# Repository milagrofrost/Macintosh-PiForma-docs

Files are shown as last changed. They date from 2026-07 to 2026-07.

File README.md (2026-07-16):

# Macintosh PiForma

**A Raspberry Pi-powered Macintosh Performa fever dream built inside an Apple IIc Monitor.**

Macintosh PiForma is a finished Raspberry Pi 4B build inside a retired Apple IIc Monitor shell. It is not a restoration. It is not pretending to be a museum piece. It is a working, portable, weirdly sincere Apple-flavored machine that lives somewhere between a Macintosh Performa, a Raspberry Pi desktop, a retro game station, and a piece of early-2000s Mac mod forum nostalgia.

The original CRT was already too far gone to justify saving. The case, power switch, AC inlet, rear openings, and overall monitor shape were kept and reused. The inside was rebuilt around a modern LCD, a Raspberry Pi 4B, an Anker battery, a custom 5V JST power rail, a boot chime module, a capacitive Apple logo button, and a Bluetooth-converted Apple ADB keyboard.

It is called **Macintosh PiForma** because puns are allowed here.

## What it does

- Boots a Raspberry Pi desktop with a Mac OS 9-ish look.
- Runs at 800x480 on an internal LCD panel.
- Uses the original Apple monitor power switch to turn the system rail on and off.
- Can charge its internal Anker battery through the original rear AC inlet.
- Can run from battery power.
- Has HDMI from the Raspberry Pi and RCA composite video input through the LCD controller.
- Has a rear source-select switch wired to the LCD controller's source button.
- Has a boot chime selector with multiple startup sounds.
- Uses the front Apple logo as a capacitive multi-tap gesture button.
- Has an internal USB speaker for Raspberry Pi audio.
- Uses a converted Apple ADB keyboard over Bluetooth.
- Uses a matching 3D printed Apple-style wireless mouse.
- Travels in a custom velvet-lined bag with a hidden wireless charging pad.

## Why this exists

I grew up looking at Macintosh mods on places like AppleFritter and other early Mac modding corners of the internet. G3s, G4s, weird translucent plastics, practical hacks, dumb hacks, beautiful hacks. I always wanted to build something that felt like that era.

Macintosh PiForma is not a perfect recreation of anything Apple shipped. It is more like a fever dream of what a portable Macintosh Performa-ish object could have been if it had Raspberry Pi guts, a pile of JST connectors, too many HDMI ribbon cables, and a stubborn refusal to stop being charming.

## Project status

This is documented as a **finished project**.

That does not mean there are no future improvements. It means this version is complete enough to put a bow on it and stop mentally treating it as a pile of loose tasks.

## PiForma software projects

Macintosh PiForma is one integrated build spread across this documentation repository and several companion application repositories. This repo explains the machine, recovery notes, hardware, wiring, and how the software pieces fit together. The app repositories own their own source, build, and release details.

| Project | Repository | Role |
|---|---|---|
| PiForma Panel | https://github.com/milagrofrost/piforma-panel | active Macintosh-style top panel and menu bar |
| AtEase Simulator | https://github.com/milagrofrost/AtEase-simulator | At Ease-style launcher surface |
| ControlStrip Simulator | https://github.com/milagrofrost/ControlStrip-Simulator | bottom-left Control Strip and app focus helper |
| About This PiForma | https://github.com/milagrofrost/about-this-pi | About This Mac-style PiForma system window |
| Clippy PiForma fork | https://github.com/milagrofrost/clippy-rpi | retro desktop assistant |
| Flight of the Toasters | https://github.com/milagrofrost/Flight-of-the-Toasters | local Flying Toasters web app used by the launcher |

For the current system layout, see [Software](docs/software.md). For package inventory and rebuild planning, see [PiForma Package Inventory](docs/package-inventory.md) and [Macintosh PiForma Software Installation](docs/software-installation.md). For how the custom apps work together, see [Software Ecosystem](docs/software-ecosystem.md). For the canonical repo map, see [Related Projects](docs/related-projects.md).

## Photo placeholders

Add final project photos here:

```text
docs/images/front-beauty-shot.jpg
docs/images/rear-panel.jpg
docs/images/interior-open.jpg
docs/images/shelf-assembly.jpg
docs/images/power-rail.jpg
docs/images/display-controller.jpg
docs/images/battery-position.jpg
docs/images/boot-chime-selector.jpg
docs/images/apple-logo-touch-sensor.jpg
docs/images/keyboard-mod.jpg
docs/images/mouse.jpg
docs/images/bag-interior.jpg
docs/images/monitor-stand.jpg
```

## Hardware overview

At a high level:

```mermaid
flowchart TD
    AC[Original rear AC inlet] --> Charger[Internal 100W USB power adapter]
    Charger --> Battery[Anker Prime 26K 300W battery]
    Battery --> Switch[Original Apple monitor power switch]
    Switch --> Rail[Custom 5V JST power rail]

    Rail --> Pi[Raspberry Pi 4B]
    Rail --> LCD[LCD controller board]
    Rail --> Chime[YS-M3 boot chime module]
    Rail --> Touch[TTP223 Apple logo touch sensor]

    Pi --> HDMI[HDMI ribbon path]
    HDMI --> LCD
    Pi --> Speaker[Internal USB speaker]
    Pi --> GPIO[GPIO controls]
    GPIO --> Touch
    GPIO --> Volume[EC11 volume encoder]

    RCA[Rear RCA composite input] --> LCD
    Source[Rear source select switch] --> LCD
    Chime --> ChimeSpeaker[Salvaged laptop speaker]
```

## Repo layout

```text
/
├── README.md
├── docs/
│   ├── hardware.md
│   ├── software.md
│   ├── wiring.md
│   ├── bom.md
│   ├── printed-parts.md
│   ├── build-log.md
│   ├── maintenance.md
│   ├── known-issues.md
│   ├── safety.md
│   └── images/
├── stl/
│   ├── shelf/
│   ├── bezel/
│   ├── screen-feet/
│   ├── power-rail/
│   ├── battery-plunger/
│   ├── boot-chime-switch/
│   └── monitor-stand/
├── scripts/
├── systemd/
├── config/
└── references/
```

## Major docs

- [Hardware](docs/hardware.md)
- [Software](docs/software.md)
- [Package Inventory](docs/package-inventory.md)
- [Software Installation](docs/software-installation.md)
- [Software Ecosystem](docs/software-ecosystem.md)
- [Related Projects](docs/related-projects.md)
- [Wiring](docs/wiring.md)
- [Bill of Materials](docs/bom.md)
- [Printed Parts](docs/printed-parts.md)
- [Build Log](docs/build-log.md)
- [Maintenance](docs/maintenance.md)
- [Known Issues](docs/known-issues.md)
- [Safety](docs/safety.md)

## Credits

Built by **Matthew Frost**.

The Apple ADB keyboard Bluetooth conversion is based on Matt Chesters' excellent work:

<https://github.com/mattchesters/zmk-apple-desktop-bus-keyboard>

That keyboard work is not my original design. It is included here because the keyboard became part of the complete Macintosh PiForma setup.

## License

Suggested license split:

- Code, scripts, and service files: MIT
- Documentation and printed part notes: CC BY 4.0
- Third-party designs remain under their original licenses

See [LICENSE.md](LICENSE.md).

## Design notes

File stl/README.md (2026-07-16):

# Macintosh PiForma Printable Files

These are the normalized printable and editable model files used in the finished Macintosh PiForma build.

## File-format warning

The `.3mf` files in this archive were created or saved with **Microsoft 3D Builder**. They are not Bambu Studio project files and are not guaranteed to import correctly into Bambu Studio or another slicer. Assemblies, transforms, or mock-up geometry may be interpreted differently.

For normal printing:

1. Prefer the supplied `.stl` when one exists.
2. When only a `.3mf` exists, open it in Microsoft 3D Builder and export or save the printable geometry as STL before slicing.
3. Do not assume a 3MF and STL with related names contain identical geometry. The exceptions are documented below.

Bambu Studio successfully handled the printable models used for the actual build, including models that other mesh-analysis tools may describe as multi-shell or non-watertight. Do not automatically repair or simplify a model without checking that the resulting geometry still matches the installed part.

## General print guidance

- The supplied orientation is the intended starting orientation in most cases.
- Support requirements depend on printer, material, and slicer settings.
- Unless noted otherwise, print one copy of the supplied file.
- `screen-retaining-feet-four-piece.stl` already contains all four feet.
- Test-fit before final assembly. Several parts depend on the exact geometry of this modified Apple IIc Monitor shell.
- Pilot holes may need to be carefully enlarged with a drill when using thicker screws.

## File inventory

| Folder | File | Status and purpose |
|---|---|---|
| `power-rail/` | `5v-rail-enclosure.3mf`, `.stl` | Enclosure for the handmade 5V JST distribution rail mounted to the shelf. |
| `status-led/` | `apple-crt-status-led-cover.3mf`, `.stl` | Light shield around the replacement green status LED behind the original acrylic indicator area. Prevents light leakage inside the case. |
| `battery-plunger/` | `anker-battery-button-plunger.3mf` | Current spring/plunger assembly used to press the Anker battery button through an existing rear control hole. This newer geometry is kept as one assembly. The older STL was intentionally omitted because it does not match the final design. Export an STL through Microsoft 3D Builder before slicing. |
| `bezel/` | `lcd-curved-bezel-final.stl` | Known-good final curved bezel joining the flat LCD to the original curved CRT opening. |
| `bezel/` | `lcd-curved-bezel-generator.scad` | Editable OpenSCAD generator. Parameter naming is historically mixed up; read the warning in the source before changing values. |
| `bezel/` | `lcd-bezel-braces-three-piece.3mf` | Contains three shallow braces spanning the rear of the LCD and fastening into the bezel. Export through Microsoft 3D Builder before slicing. Use short, shallow screws; enlarge pilot holes only as needed. |
| `monitor-stand/` | `folding-monitor-stand.3mf`, `.stl` | Folding external monitor stand. Raises the viewing angle approximately 15–20 degrees and folds flat for transport. |
| `screen-feet/` | `screen-retaining-feet-four-piece.stl` | Four feet already arranged in one STL. The original case screws and metal frame press these against the bezel to retain it. The rejected experimental 3MF was intentionally omitted. |
| `power-switch/` | `narrow-original-power-switch.3mf`, `.stl` | Narrower replacement actuator for the original power-switch opening. Prevents binding caused by the shifted internal assembly. |
| `shelf/` | `internal-three-level-rack.3mf`, `.stl` | Internal rack for the Raspberry Pi, power rail, LCD controller, power adapter, and USB speaker. |
| `shelf/` | `rpi-elevator.3mf`, `.stl` | Raises the Raspberry Pi above the upper shelf to create an airflow gap and reduce heat transfer into the shelf. |
| `shelf/` | `rpi-shelf-spacer.3mf`, `.stl` | Small optional spacer used with the zip-tied shelf arrangement to limit movement and help keep the Pi positioned. |
| `boot-chime-switch/` | `boot-chime-board-speaker-case.3mf`, `.stl` | Case for the boot-chime soundboard and salvaged laptop speaker, attached inside the metal enclosure with double-sided adhesive. |
| `boot-chime-switch/` | `boot-chime-selector-dial.stl` | Actual printable selector-dial part for the multi-position startup-sound selector. |
| `boot-chime-switch/` | `boot-chime-selector-dial-reference-mockup.3mf` | 3D Builder mock-up containing surrounding reference geometry. It is included for design context, not as the preferred print file. Print the STL instead. |
| `usb-panel-mount/` | `usb-panel-mount.3mf`, `.stl` | Compact threaded panel mount for a solder-tab female USB receptacle installed in an enlarged original control hole. |

## Thermal and electrical safety

The Pi elevator and rack are part of the current thermal mitigation. The Raspberry Pi previously heated and warped the upper shelf, which then flexed the LCD controller board and caused display glitches and color loss.

Current mitigation includes an air gap, a zip tie supporting the shelf, and aluminum foil used as a reflective layer above and below the Pi. Aluminum foil is conductive. It must remain electrically isolated from the Pi, GPIO pins, USB shields, solder joints, display-controller board, power rail, and all exposed electronics. A nonconductive thermal barrier is preferred for a future revision.

Use PETG or another heat-tolerant material for the rack and Pi elevator when possible. A future rack revision should add a center support column or rib.

## Third-party mouse model

The Apple-style wireless mouse is not redistributed here. The build uses the third-party [Retro Wireless Computer Mouse](https://www.printables.com/model/1339297-retro-wireless-computer-mouse) shell plus the project-specific [Custom scroll wheel and axle](https://www.printables.com/model/1774131-scroll-wheel-and-axle-for-retro-wireless-computer) documented in `docs/hardware.md`.

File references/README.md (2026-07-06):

# References

Add links and third-party project references here.

## Keyboard conversion

Matt Chesters' Apple Desktop Bus keyboard ZMK project:

https://github.com/mattchesters/zmk-apple-desktop-bus-keyboard

Used as the basis for the A9M0330 Bluetooth keyboard conversion.

## Mouser boot chime selector

CK1028 selector switch:

https://www.mouser.com/ProductDetail/105-CK1028

Used to select the YS-M3 boot chime.

## AliExpress display and HDMI parts

Known order links from project purchase history:

- Final 9-inch display kit: https://www.aliexpress.com/item/3256805818626591.html
- FPV HDMI ribbon adapters: https://www.aliexpress.com/item/3256808758230576.html
- PCB800099 / VS-TY2662 controller experiment: https://www.aliexpress.com/item/2251832767582592.html
- PCB800099 controller order: https://www.aliexpress.com/item/3256807476829617.html
- 9-inch 1024x600 LCD experiment: https://www.aliexpress.com/item/3256808854350207.html

## Mouse shell

TODO: add original Apple-style 3D printed mouse shell link.

```text
references/apple-style-wireless-mouse-link.txt
```

## Photos

TODO: add build photos under:

```text
docs/images/
```

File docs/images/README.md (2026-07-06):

# Images

Drop project images here.

Recommended filenames:

```text
front-beauty-shot.jpg
rear-panel.jpg
interior-open.jpg
shelf-assembly.jpg
power-rail.jpg
display-controller.jpg
battery-position.jpg
boot-chime-selector.jpg
apple-logo-touch-sensor.jpg
keyboard-mod.jpg
mouse.jpg
bag-interior.jpg
monitor-stand.jpg
```

These filenames are referenced from the main README and docs.

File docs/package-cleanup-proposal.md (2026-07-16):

# PiForma APT Cleanup Proposal

Audit date: 2026-07-15

This is the pre-change cleanup proposal for the live `macintosh-piforma` Raspberry Pi.
It is not the final fresh-install package manifest.

## Current Status: Preserved Inventory, Not Removal

This document began as a cleanup investigation. The owner has since decided that no package removal is authorized as part of this task, and no packages were removed during this work.

Experimental, compatibility, development, source-build, and possible future-feature software should be preserved and documented. Packages that were previously described as removal candidates are now classification candidates. "Not currently referenced" does not mean "unneeded"; it may mean development, experiment, fallback, alternate implementation, compatibility support, diagnostic utility, historical build dependency, or intentionally preserved unknown.

This file remains useful as the initial audit record. The canonical long-term package results now live in:

- [PiForma Package Inventory](package-inventory.md)
- [Macintosh PiForma Software Installation](software-installation.md)
- [`../packages/`](../packages/)

## System Snapshot

- OS: Debian GNU/Linux 13.5 (trixie)
- Kernel: `6.18.34+rpt-rpi-v8`
- Architecture: `arm64` / aarch64
- Foreign architecture: `armhf`
- Active desktop session: LightDM autologin, `rpd-x`, X11
- Active desktop processes: `lxsession -s rpd-x -e LXDE`, Openbox, `pcmanfm --desktop`, PiForma Panel, AtEase, ControlStrip Simulator, Clippy, PipeWire, WirePlumber
- dpkg status rows before cleanup investigation: 2911
- Installed/held-installed package rows before cleanup investigation: 2909 (`ii`: 2908, `hi`: 1)
- Config/status residue rows before cleanup investigation: 2 (`rc`: 2, `rpi-connect-lite` and `tint2`)
- Manually marked APT packages before cleanup investigation: 401
- Automatically marked APT packages before cleanup investigation: 2508
- Held packages: `libsdl2-dev`
- Failed systemd units before cleanup: none
- Failed user units before cleanup: none

## APT Sources

Configured repositories are Debian Trixie and Raspberry Pi Foundation Trixie for `arm64` and `armhf`:

- `http://deb.debian.org/debian/` suites `trixie trixie-updates`
- `http://deb.debian.org/debian-security/` suite `trixie-security`
- `http://archive.raspberrypi.com/debian/` suite `trixie`

No third-party APT repository was found. Local PiForma application packages installed outside configured repositories:

- `about-this-pi-forma`
- `at-ease`
- `clippy`
- `control-strip-simulator`
- `pi-forma-panel`

## Definitely Keep

These have direct live evidence from active services, live processes, or current launchers:

- Base display/session: `lightdm`, `rpd-x-core`, `rpd-x-extras`, `xserver-xorg`, `openbox`, `pcmanfm`, `lxsession`, `lxpolkit`, `picom`, `xcompmgr`
- PiForma apps: `pi-forma-panel`, `at-ease`, `control-strip-simulator`, `clippy`, `about-this-pi-forma`
- Audio/runtime: `pipewire`, `pipewire-audio`, `pipewire-pulse`, `wireplumber`, `pulseaudio-utils`, `alsa-utils`
- Script/runtime tools: `python3`, `python3-gpiozero`, `python3-rpi-lgpio`, `wmctrl`, `xdotool`, `x11-utils`, `jq`
- Launchers/features: `chromium`, `qmmp`, `flatpak`, `lxterminal`, `pcmanfm`
- Raspberry Pi support: `raspi-firmware`, `raspi-utils`, `rpi-eeprom`, `raspberrypi-sys-mods`, `raspberrypi-net-mods`, firmware packages, networking and Bluetooth packages

## Keep If Local Development Continues

These appear to support local building/packaging rather than base runtime:

- General build: `build-essential`, `cmake`, `gcc`, `g++`, `git`, `devscripts`, `debhelper`, `dh-autoreconf`, `shellcheck`
- Node/Tauri: `nodejs`, `npm`, `libwebkit2gtk-4.1-dev`, `libgtk-3-dev`, `libayatana-appindicator3-dev`
- PiForma/ControlStrip media or native builds: `libpipewire-0.3-dev`, `libspa-0.2-dev`, `libasound2-dev`, `libpulse-dev`, `libudev-dev`, `libx11-xcb-dev`, `libgbm-dev`, `libdrm-dev`, `libusb-1.0-0-dev`, FFmpeg dev packages
- Qt/local app experiments: `qt6-base-dev`, `qt6-multimedia-dev`, `qt6-tools-dev`, `qtcreator`, related Python/Qt packages
- Emulator or media build headers: `libvlc-dev`, `libvlccore-dev`, `libcdio-dev`, `libiso9660-dev`, `libsdl2-dev`, `libfreeimage-dev`, `libfreetype-dev`, `libboost-filesystem-dev`, `libspeexdsp-dev`

Do not remove this group until the owner decides whether this Pi remains a development machine.

## Optional Feature Packages

Keep unless the feature is intentionally removed:

- `qmmp`: current Winamp launcher target
- `flatpak`: current Kiwix/Encarta launcher target; Flatpak apps found: `org.kiwix.desktop`, `org.kde.marble`, `org.qgis.qgis`
- `chromium`: many AtEase kiosk launchers and Weather Channel/Flying Toasters
- `vlc`: no current AtEase launcher, but may be retained as optional media support
- `x11vnc`, RealVNC packages: remote access; owner decision
- RetroPie/EmulationStation: current AtEase launcher calls `emulationstation`, but it is not owned by APT
- SheepShaver: current AtEase launcher uses `/home/frost/emulation/SheepShaver-aarch64.AppImage`

## First Batch Reclassified As Preserved Experiments

These were initially identified as a possible small cleanup batch. That removal framing is now superseded. They are preserved as installed experiments unless future owner review establishes a different purpose.

| Package | Evidence | Simulation | Installed size | Disposition |
| --- | --- | --- | ---: | --- |
| `dosbox-x` | Docs mark DOSBox-X / Windows 98 as experimental or pending confirmation; no current AtEase launcher or live process found. | Earlier simulation removed only the four named packages; no real removal was run. | 11452 KiB | preserved experiment |
| `qtractor` | Audio workstation / music production experiment candidate; no service, current launcher, or live process found. | Earlier simulation removed only named packages; no real removal was run. | 8574 KiB | preserved experiment |
| `tuxpaint` | Docs mark Tux Paint as historical/dormant/pending owner confirmation; no current AtEase launcher or live process found. | Earlier simulation removed only named packages; no real removal was run. | 617 KiB | preserved experiment |
| `tuxpaint-config` | Configuration tool associated with the preserved Tux Paint experiment. | Earlier simulation removed only named packages; no real removal was run. | 1414 KiB | preserved experiment |

## Other Groups Reframed As Preserved Classifications

- XFCE packages: alternate desktop/session and appmenu experiment. Preserve.
- Wayland and Weston packages: alternate display/session experiment and Raspberry Pi desktop compatibility. Preserve.
- Xephyr: nested display testing tool. Preserve as experiment/diagnostic utility.
- `rpd-wayland` packages: Raspberry Pi desktop Wayland stack and alternate implementation. Preserve.
- `labwc`: Wayland compositor retained for alternate desktop testing. Preserve.
- `wayvnc`: Wayland remote-access support retained with the Wayland stack. Preserve.
- Wine and `armhf` packages: compatibility layer and foreign-architecture support. Preserve.
- VLC: optional media player and media-development support. Preserve.
- VNC packages: remote administration and fallback access. Preserve.
- Firefox: Raspberry Pi desktop application/fallback browser. Preserve.
- Old kernels: kernel history and possible boot fallback. Do not remove during package inventory work.
- Development headers: intentionally retained local build environment. Preserve.
- Qt development packages: Qt/local app experiments and development. Preserve.
- Media development packages: confirmed or likely source-build dependencies. Preserve.
- Emulator development packages: confirmed or likely emulator/source-build dependencies. Preserve.

## Superseded Cleanup Plan

The earlier plan to remove a first explicit batch is superseded and must not be followed. Current plan:

1. Preserve installed software.
2. Snapshot exact dpkg/APT state.
3. Classify packages by role and rebuild profile.
4. Document local `.deb` packages and non-APT software.
5. Build a future fresh-install guide without claiming reproducibility until a separate-media rebuild is tested.

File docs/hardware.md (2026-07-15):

# Hardware

This document describes the physical Macintosh PiForma build from the final working state.

## Donor shell

- Donor: Apple IIc Monitor
- Model: A2M4090
- Manufacture date: February 1985
- Original CRT: removed years ago
- Final use: Raspberry Pi-powered Macintosh-inspired portable computer

This is not a restoration. The CRT was discolored, flickering, and not worth saving for this project. The case, original power switch, original AC inlet, rear openings, metal chassis, and monitor shape were reused because the shell still had life in it.

## Internal layout

The build has four main physical zones:

1. Front display area
2. Three-level printed shelf
3. Rear battery area
4. Rear controls and ports

The shelf does not hold the Anker battery. The Anker battery sits separately toward the rear of the monitor on the metal chassis floor. It is installed lengthwise and held by friction between the sides of the case.

## Three-level shelf

The custom 3D printed shelf is the main internal component carrier.

### Top shelf

- Raspberry Pi 4B, 4GB RAM
- Custom 5V JST power rail
- Power rail enclosure
- Related wiring

The Raspberry Pi is mounted with zip ties.

### Middle shelf

- Internal 100W USB power adapter
- LCD controller board

The LCD controller slides into printed notches like a tray, which makes it serviceable instead of permanently buried.

### Bottom shelf

- Internal USB speaker

The USB speaker is connected directly to the Raspberry Pi and handles normal system audio.

## Rear battery area

The Anker Prime 26K 300W battery sits lengthwise across the rear metal chassis floor. It is a very tight fit and is held by friction rather than a printed mount.

A custom 3D printed plunger reaches the Anker's physical button. From the outside rear of the case, pressing the plunger lets the user wake the battery display or interact with the battery without opening the case.

## Display system

The final installed display is the 9-inch HDMI/VGA/AV LCD kit purchased on May 16, 2026. The current working mode is:

- Resolution: 800x480
- Inputs used: HDMI and RCA composite
- VGA: available on the controller but unused

Earlier experiments included 1024x600-class 9-inch panels, PCB800099-style boards, and multiple HDMI ribbon cable orientations. Those are part of the build history, but the final working display is the May 16 display kit running at 800x480.

## LCD mounting

The LCD is mounted with:

- 3D printed bezel
- 3D printed screen feet
- 3D printed horizontal braces
- small hot glue dabs for alignment during assembly
- original chassis screws that pull the metal chassis and front case together

The screen rests into the printed bezel. The bezel aligns it. The horizontal braces help keep it registered. The feet really do their job once the metal chassis is screwed into the front shell.

## Display ribbon

The current LCD ribbon is about 150mm. It is longer than needed, but it works.

Known behavior:

- the connection is sensitive
- the ribbon is taped down to reduce movement
- shorter 80mm or 50mm cable may be a future improvement
- once it works, do not mess with it just because you are bored

## Video paths

### Raspberry Pi video

The Raspberry Pi connects to the LCD controller over HDMI using angled and ribbon-style adapters. A normal HDMI connector would protrude too far and contact the back of the LCD, causing distortion.

### Composite video

A rear RCA panel jack replaces one of the original brightness/contrast control openings. It connects to the composite input on the LCD controller.

### Source select

The LCD controller's button daughterboard is mounted inside the case. The IR receiver is unused. The source button was soldered to wires and routed to a rear physical switch.

The source switch cycles:

```text
HDMI -> RCA -> VGA -> RCA2 -> repeat
```

Only HDMI and RCA are normally useful.

## Power system

The Anker battery is the heart of the power system.

Final power path:

```text
Original AC inlet
  -> internal 100W USB power adapter
  -> Anker Prime 26K 300W battery
  -> original Apple monitor power switch
  -> custom 5V JST power rail
  -> Raspberry Pi, LCD controller, boot chime module, touch sensor
```

The original monitor power switch interrupts battery output to the 5V rail. It does not interrupt AC input to the internal charger. That means the battery can still charge while the monitor is off.

The final internal charger is the 100W USB power adapter from eBay. A different Amazon power adapter caused noise and EMI weirdness, including false triggers from sensors and relay instability, so it was not used.

## Custom 5V JST rail

The rail is handmade from:

- through-hole perfboard
- about six small 2-pin JST outputs
- stripped solid-core wire used as bus bars
- soldered underside connections
- 3D printed enclosure

Connected loads include:

- Raspberry Pi 4B
- LCD controller
- YS-M3 boot chime module
- TTP223 Apple logo touch sensor

The USB speaker is powered through the Raspberry Pi USB port, not from the JST rail.

There are no relays in the final build and no fuses on the custom rail. The build relies on the Anker and connected devices for protection.

## Boot chime system

Parts:

- YS-M3 MP3 sound module
- Mouser CK1028 selector switch
- salvaged laptop speaker
- custom 3D printed sound module and speaker housing
- rear-mounted boot chime selector

Behavior:

- YS-M3 is powered from the 5V rail
- it plays a selected sound a couple seconds after power is applied
- CK1028 selects between about 9 or 10 boot chimes
- audio plays through its own salvaged laptop speaker

The selector is mounted in one of the rear holes where the original brightness/contrast controls used to be.

## Main audio

Normal Raspberry Pi audio uses the internal USB speaker mounted on the bottom shelf.

An external USB-to-3.5mm/RCA audio adapter can be used if RCA audio is needed, but it is not built into the monitor. The rear RCA jack is composite video only.

MAX98357A amplifier boards were purchased and tested but are not part of the final installed audio path.

## Apple logo gesture input

The front Apple logo has a TTP223 capacitive touch sensor behind it.

- Sensor: TTP223
- GPIO: 23
- Function: multi-tap and hold gesture input

Gesture map:

| Gesture | Action |
|---|---|
| 1 tap | Open Internet Explorer themed launcher |
| 2 taps | Open Mac OS 9 / SheepShaver |
| 3 taps | Open Winamp/QMMP style player |
| 4 taps | Open RetroPie / EmulationStation |
| Hold | Close the active window |

The four-tap RetroPie gesture is the practical one. Power on, plug in a controller, tap the Apple logo four times, and start playing without pulling out the keyboard and mouse.

The hold gesture also solves the N64 controller hotkey problem. Instead of sacrificing a controller button, holding the Apple logo closes the active game or EmulationStation.

## Volume knob

The original monitor volume area is repurposed with an EC11 rotary encoder.

| Function | GPIO |
|---|---:|
| Encoder A | GPIO 17 |
| Encoder B | GPIO 27 |
| Encoder push | GPIO 22 |

Rotation adjusts system volume. Push-to-mute exists in software but is not physically usable in the final installation.

## Keyboard

Keyboard: Apple ADB Keyboard A9M0330

The keyboard is converted to Bluetooth using Matt Chesters' ZMK ADB keyboard project:

https://github.com/mattchesters/zmk-apple-desktop-bus-keyboard

This keyboard conversion is part of the Macintosh PiForma setup, but it is not an original design from this project.

Installed keyboard components:

- Seeed XIAO nRF52840
- custom PCB
- nice!view display
- MCP23017 I/O expander
- USB-C charging
- JST battery connector
- 110mAh LiPo battery
- ZMK firmware

The keyboard currently works over Bluetooth and charges over USB-C.

## Mouse

The matching mouse uses:

- Bambu wireless mouse kit electronics
- [Retro Wireless Computer Mouse](https://www.printables.com/model/1339297-retro-wireless-computer-mouse) 3D printed shell
- [Custom scroll wheel and axle](https://www.printables.com/model/1774131-scroll-wheel-and-axle-for-retro-wireless-computer)
- USB receiver plugged into the Raspberry Pi
- Retro Platinum PLA for the printed shell

The original mouse design required the Bambu-supplied scroll wheel to be cut and whittled down to fit. That wheel broke during modification, so a complete replacement scroll wheel and axle were designed and printed instead.

## Bag system

The travel bag is part of the project.

Bag features:

- LOVFEIFAN / LOVFEI FAN style 55x30x20 cm bag
- corrugated plastic liner
- foam bottom
- green velvet covering
- spray adhesive
- hidden wireless charging transmitter
- alignment grooves for the monitor bottom

The bag stores the computer, ADB Bluetooth keyboard, mouse, controllers, USB hub, stand, cables, and power accessories.

The wireless charging pad is hidden under the velvet. A USB cable runs through the bag into a back pocket, where it can be pulled out to power the wireless charger. This is a trickle-charge setup for charging Macintosh PiForma while it is stored in the bag.

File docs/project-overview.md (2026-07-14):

# Project Overview

**Macintosh PiForma** is a Raspberry Pi-powered Macintosh Performa fever dream built inside an Apple IIc Monitor.

It is not a restoration. It is not trying to be a museum piece. It is a working, portable, weirdly sincere Apple-flavored machine that lives somewhere between a Macintosh Performa, a Raspberry Pi desktop, a retro game station, and a piece of early-2000s Mac mod forum nostalgia.

## The short version

This is a 1985 Apple IIc Monitor shell turned into a portable Raspberry Pi Macintosh-ish computer.

It has:

- a Raspberry Pi 4B running an 800x480 Mac OS 9-ish desktop
- the original monitor power switch repurposed as the system power switch
- an internal Anker Prime 26K battery
- an internal USB-C charger wired to the original rear AC inlet
- a handmade 5V JST power rail
- HDMI and RCA composite video support through the LCD controller
- a boot chime selector with multiple startup sounds
- a front Apple logo that works as a capacitive gesture button
- a Bluetooth-converted Apple ADB keyboard
- a 3D printed Apple-style wireless mouse
- a custom At Ease-style launcher
- a Control Strip-style dock
- an About This PiForma app
- a retro Clippy assistant
- a velvet-lined travel bag with hidden wireless trickle charging

## The software family

Macintosh PiForma now includes a small family of companion apps.

| Project | Repo | What it does |
|---|---|---|
| PiForma Panel | https://github.com/milagrofrost/piforma-panel | Macintosh-style top panel and menu bar |
| AtEase Simulator | https://github.com/milagrofrost/AtEase-simulator | At Ease-style launcher shell |
| ControlStrip Simulator | https://github.com/milagrofrost/ControlStrip-Simulator | Mac OS-style utility strip / dock |
| About This PiForma | https://github.com/milagrofrost/about-this-pi | About This Mac-style system info window |
| Clippy PiForma fork | https://github.com/milagrofrost/clippy-rpi | retro desktop assistant |
| Macintosh PiForma docs | https://github.com/milagrofrost/Macintosh-PiForma-docs | the build, BOM, wiring, lore, and maintenance notes |

## Why this works

The hardware gives the machine a body. The software gives it a personality.

The power switch, boot chime, Apple logo gestures, AtEase launcher, Control Strip, and matching keyboard all work together. Any one of those pieces alone would be cute. Together, they make the build feel like a complete little computer from a timeline that never existed.

## The important trick

The front Apple logo is a real input device.

| Gesture | Action |
|---|---|
| 1 tap | Open Internet Explorer / Netscape-style launcher |
| 2 taps | Open Mac OS 9 / SheepShaver |
| 3 taps | Open Winamp / QMMP |
| 4 taps | Open RetroPie / EmulationStation |
| Hold | Close the active game or window |

The four-tap RetroPie gesture is not just cute. It means the keyboard and mouse can stay in the bag when the only goal is playing games.

## What to read next

- [Hardware](hardware.md)
- [Software](software.md)
- [Software Ecosystem](software-ecosystem.md)
- [Live System Audit Summary](live-system-audit.md)
- [Wiring](wiring.md)
- [Bill of Materials](bom.md)
- [Printed Parts](printed-parts.md)
- [Build Log](build-log.md)
- [Related Projects](related-projects.md)
- [Cleanup and Archival Plan](cleanup-plan.md)
- [Media Plan](media-plan.md)
- [Maintenance](maintenance.md)
- [Known Issues](known-issues.md)
- [Safety](safety.md)

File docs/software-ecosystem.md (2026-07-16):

# Software Ecosystem

Macintosh PiForma is not just a Raspberry Pi in a monitor shell. The software stack is what makes it feel like a machine instead of a parts bin.

The hardware gives it a body. The software gives it a personality.

The package-level inventory and rebuild profile work lives in [PiForma Package Inventory](package-inventory.md) and [Macintosh PiForma Software Installation](software-installation.md).

## The desktop illusion

The live system is a Raspberry Pi 4 Model B running a Raspberry Pi OS / Debian 13 Trixie-style desktop stack on X11. The shell is built around LightDM, LXDE, Openbox, PCManFM, PiForma Panel, AtEase, ControlStrip Simulator, PipeWire, and a pile of intentionally nostalgic launchers.

The point is not to fake macOS perfectly. The point is to make a Raspberry Pi behave like a computer that fell out of a late-90s Apple fever dream.

Core pieces:

| Layer | Role |
|---|---|
| LightDM | graphical login |
| rpd-x / LXDE | session environment |
| Openbox | window manager |
| PiForma Panel | active Mac-style top menu bar |
| PCManFM | desktop background and file-manager integration |
| AtEase | At Ease-style launcher surface |
| ControlStrip Simulator | bottom-left dock and app focus helper |
| PipeWire / WirePlumber | audio |
| systemd | boots custom services into the graphical target |

## Custom apps in the PiForma family

These are the companion apps that turned the desktop from a theme into an ecosystem.

| App | Repo | Role |
|---|---|---|
| PiForma Panel | https://github.com/milagrofrost/piforma-panel | active Macintosh-style top panel and menu bar |
| AtEase Simulator | https://github.com/milagrofrost/AtEase-simulator | full-screen At Ease-style launcher shell |
| ControlStrip Simulator | https://github.com/milagrofrost/ControlStrip-Simulator | transparent Mac OS-style Control Strip dock |
| About This PiForma | https://github.com/milagrofrost/about-this-pi | About This Mac-style system window for the build |
| Clippy PiForma fork | https://github.com/milagrofrost/clippy-rpi | retro desktop assistant, forked from Felix Rieseberg's Clippy |
| Flight of the Toasters | https://github.com/milagrofrost/Flight-of-the-Toasters | local Flying Toasters web app used by the launcher |
| Macintosh PiForma docs | https://github.com/milagrofrost/Macintosh-PiForma-docs | build documentation, BOM, wiring, lore, and maintenance notes |

## AtEase Simulator

AtEase is the main retro launcher shell.

It is a Tauri app modeled after Apple's At Ease experience. It shows tabbed pseudo-folders full of big beveled launcher buttons. Each item launches a configured `.desktop` file rather than letting the front end run arbitrary shell commands.

Known installed paths from the live audit:

```text
/usr/bin/atease
/usr/share/applications/AtEase.desktop
~/.local/share/atease/config.yaml
~/.local/share/atease/apps/
~/.local/share/atease/apps-2/
~/.local/share/atease/
```

Service:

```text
atease.service
```

The current live config renders at x=77, y=0, width=656, height=480. It starts on the main At Ease Items folder and also defines a second `sites` folder backed by `~/.local/share/atease/apps-2/`.

This is the part that makes PiForma feel less like a Linux desktop and more like a kid-safe restoration CD from an alternate Apple timeline.

## ControlStrip Simulator

ControlStrip Simulator is the dock-like utility strip.

It is a Tauri app that runs as a frameless transparent window under X11. It reads pinned apps from YAML, detects visible windows using X11 tooling, marks running apps, and launches or focuses them.

Known installed paths from the live audit:

```text
/usr/bin/controlstrip-simulator
/usr/share/applications/ControlStrip Simulator.desktop
~/.local/share/control-strip/config.yaml
```

Service:

```text
controlstrip-simulator.service
```

The live config pins Chromium/Netscape, LXTerminal, and PCManFM. It detects running windows with X11 tooling and focuses windows through `wmctrl`. Wayland is not the target right now.

## About This PiForma

About This PiForma is the machine's little brag window, except it is not really bragging. It is the classic About This Mac format translated into PiForma language.

Instead of pretending to be a real Mac, it reports the things that make sense for this build:

- PiForma name and version
- Raspberry Pi model
- memory
- swap
- running apps
- OS/system details

Repo:

```text
https://github.com/milagrofrost/about-this-pi
```

## Clippy

Clippy is not Mac at all, which is why it is funny.

It is Felix Rieseberg's Clippy idea pushed into the PiForma world as a retro desktop assistant. It runs locally and gives the machine that late-90s software-toy energy.

Installed paths from the audit:

```text
/usr/bin/clippy
/usr/lib/clippy/Clippy
~/.config/autostart/clippy.desktop
```

Repo:

```text
https://github.com/milagrofrost/clippy-rpi
```

## The launcher set

The AtEase launcher set is intentionally a little ridiculous.

| Launcher | Actually runs |
|---|---|
| Netscape | Chromium with scaling |
| America Online | Chromium kiosk to a web AOL simulator |
| Encarta | Kiwix |
| Flying Toasters | Chromium kiosk to local web server |
| LimeWire | Chromium kiosk launcher |
| Macintosh HD | PCManFM home folder |
| Mac OS 9 | SheepShaver AppImage |
| RetroPie | EmulationStation in LXTerminal |
| Winamp | QMMP |
| Weather Channel | local Weather Channel launcher script |
| Terminal | LXTerminal |

Kid Pix, LinApple, DOSBox-X, Windows 98, and Tux Paint should be documented as historical, dormant, or pending owner confirmation until they have current launchers in the live AtEase folders.

This is not about historical purity. It is about making the machine fun to touch.

## Apple logo gestures

The front Apple logo is not just decorative. It is a capacitive gesture button.

| Gesture | Action |
|---|---|
| 1 tap | Open Internet Explorer / Netscape-style browser launcher |
| 2 taps | Open Mac OS 9 / SheepShaver |
| 3 taps | Open Winamp / QMMP |
| 4 taps | Open RetroPie / EmulationStation |
| hold 2 seconds | close active window |
| hold 6 seconds | close all windows and show desktop |
| hold 10 seconds | power off |

This is one of the most important usability details in the whole build. It lets the machine work as a game station without needing to pull out the keyboard and mouse.

## Weather Channel subsystem

The Weather Channel launcher recreates a cable-TV WeatherStar style flow.

```text
~/weather-channel/weather-channel.sh
  -> pkill chromium
  -> chromium kiosk
  -> local launch.html
  -> satellite.png splash
  -> weatherstar.netbymatt.com kiosk mode
```

It is one of those features that sounds optional until you see it running. Then it becomes obvious why it belongs here.

## Audio behavior

The system uses PipeWire and WirePlumber with a USB audio device as the default output.

The physical volume knob changes `@DEFAULT_SINK@` through `pactl`. The boot chime is separate and plays through the YS-M3 module and its own salvaged laptop speaker.

That split matters:

- boot chime is part of the machine's power-on personality
- USB speaker is normal operating audio
- optional USB-to-RCA adapter handles external RCA audio needs

## The important part

The software is not just a skin. It is how the machine becomes usable.

The Apple logo launches apps. The Control Strip gives it a living dock. AtEase makes it feel approachable. The boot chime gives it ceremony. The AtEase launcher set makes it silly in the right way.

That is the difference between a Raspberry Pi project and Macintosh PiForma.

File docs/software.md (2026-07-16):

# Software

This document captures the Macintosh PiForma software stack as currently known.

The software is not trying to be a perfect clone of classic Mac OS. It is Raspberry Pi OS dressed up like a Mac OS 9 / At Ease / early internet fever dream.

For the audited APT/dpkg inventory, local `.deb` packages, non-APT software, and rebuild profiles, see [PiForma Package Inventory](package-inventory.md) and [Macintosh PiForma Software Installation](software-installation.md).

## System

| Item | Value |
|---|---|
| Board | Raspberry Pi 4 Model B |
| RAM | 4GB |
| Storage | 256GB microSD |
| Hostname | `macintosh-piforma` |
| User | `frost` |
| OS | Raspberry Pi OS / Debian 13 Trixie-style Raspberry Pi desktop stack |
| Desktop | LXDE / Openbox / PCManFM desktop |
| Session | X11 |
| Display mode | 800x480 |

## Current graphical stack

The current live desktop is an X11 `rpd-x` session launched by LightDM. Openbox manages windows, PCManFM owns the desktop background, and PiForma Panel is the active top panel.

| Layer | Current implementation |
|---|---|
| Display manager | LightDM |
| Session | `rpd-x` / LXDE on X11 |
| Window manager | Openbox |
| Desktop background | PCManFM |
| Top panel | PiForma Panel |
| Launcher shell | AtEase |
| Dock / Control Strip | ControlStrip Simulator |
| Assistant | Clippy |
| Audio | PipeWire / WirePlumber |

LXPanel-pi and tint2 configuration files may still exist on the machine, but they are not the active top panel in the July 2026 live audit.

## Boot flow

Expected flow:

```text
Power switch on
  -> Anker battery output energizes 5V rail
  -> YS-M3 boot chime plays
  -> Raspberry Pi boots
  -> Plymouth splash
  -> RetroPie asplashscreen
  -> LightDM
  -> LXDE/Openbox desktop
  -> custom services start
```

## Desktop look

The desktop is intended to feel like a Mac OS 9-ish Raspberry Pi system.

Visual pieces:

- Mac OS 9 Platinum-style GTK theme
- Chicago-style font
- MoNine icons
- PiXflat as fallback
- At Ease inspired wallpaper
- Apple-menu-style top panel
- retro launchers

It is not macOS. It is Raspberry Pi OS wearing a thrift-store Macintosh costume, and honestly that is kind of the point.

## Important config paths

Known files and directories touched during the build:

```text
/boot/firmware/config.txt                 active boot config
/boot/config.txt                          pointer to /boot/firmware/config.txt
/etc/default/keyboard                     active keyboard defaults
/etc/xdg/lxsession/rpd-x/autostart        system LXSession fallback
~/.config/lxsession/rpd-x/autostart       active user LXSession override
~/.config/openbox/rpd-rc.xml              active Openbox config
~/.config/pcmanfm/LXDE-pi/desktop-items-0.conf
~/.local/share/piforma-panel/config.yaml
~/.local/share/control-strip/config.yaml
~/.local/share/control-strip/scripts/window-check.sh
~/.local/share/atease/config.yaml
~/.local/share/atease/apps/
~/.local/share/atease/apps-2/
~/.config/SheepShaver/prefs
~/weather-channel/
~/Desktop/
~/.icons/
~/.themes/
```

Historical or missing paths found during the July 2026 config audit:

```text
~/.config/lxpanel-pi/panels/panel         historical; PiForma Panel is active
~/.config/tint2/tint2rc                   historical; no tint2 process active
~/.config/atease/config.yaml              historical AtEase schema/path
~/.config/pcmanfm/default/desktop-items-0.conf
~/.sheepshaver_prefs                      not found
~/.asoundrc                               not found
```

## Custom services

| Service | Scope | Purpose |
|---|---|---|
| `apple-gesture-button.service` | system | Handles Apple logo capacitive gestures |
| `volume-knob.service` | system | Handles EC11 volume knob |
| `atease.service` | system | Starts the AtEase launcher as user `frost` |
| `flyingtoasters.service` | system | Serves local Flying Toasters web build |
| `piforma-panel.service` | user | Starts PiForma Panel |
| `controlstrip-simulator.service` | user | Starts ControlStrip Simulator |
| `usb-audio-loop.service` | user | Optional external USB audio-input loop |

## Apple logo gesture button

Script:

```text
/usr/local/bin/apple_gesture_button.py
```

Service:

```text
apple-gesture-button.service
```

Hardware:

- TTP223 capacitive touch sensor
- mounted behind the Apple logo
- GPIO 23
- active-low
- uses `gpiozero`
- uses `LGPIOFactory`

Gesture mapping:

| Gesture | Action |
|---|---|
| 1 tap | Open Internet Explorer / Netscape-style browser launcher |
| 2 taps | Open Mac OS 9 / SheepShaver |
| 3 taps | Open Winamp / QMMP |
| 4 taps | Open RetroPie / EmulationStation |
| Hold 2 seconds | Close active window |
| Hold 6 seconds | Close all windows and show desktop |
| Hold 10 seconds | Power off |

The four-tap RetroPie gesture exists so the keyboard and mouse can stay packed when the only goal is playing games. Power on, plug in a controller, tap the Apple logo four times, and go.

The timed hold gestures provide keyboard-free window and system control. A two-second hold closes the active game or application, a six-second hold clears the desktop, and a ten-second hold shuts down the PiForma.

## Volume knob

Script:

```text
/usr/local/bin/volume_knob.py
```

Service:

```text
volume-knob.service
```

Hardware:

- EC11 rotary encoder
- GPIO 17 and 27 for rotation
- GPIO 22 for push/mute support

Behavior:

- rotate clockwise: volume up
- rotate counterclockwise: volume down
- push-to-mute supported in software
- push-to-mute not physically usable in final hardware

## Audio stack

Normal output:

- PipeWire
- internal USB speaker
- speaker plugged directly into Raspberry Pi

Optional external audio:

- `usb-audio-loop.service` is not Nintendo 64-specific. It watches for the configured external USB audio-input or capture device and loops incoming audio to the PiForma's normal output speakers.
- The current helper selects the C-Media Cable Creation adapter by its PipeWire/PulseAudio source name.
- RCA is only one possible upstream connection method before the signal reaches the USB audio adapter; 3.5 mm or other analog connectors can also feed an appropriate adapter.
- The rear RCA jack described in the hardware documentation is composite video only. Analog external audio input requires an external USB audio adapter.

Previous experiments included MAX98357A I2S amplifier boards and other audio adapters. The final installed path is the internal USB speaker because it works.

## Included apps and launchers

Current visible launchers are managed by AtEase from `~/.local/share/atease/apps/` and `~/.local/share/atease/apps-2/`, not from `~/Desktop`.

| App / Feature | Role | Status |
|---|---|---|
| RetroPie / EmulationStation | games | primary practical use |
| Web browser | general use | primary practical use |
| SheepShaver / Mac OS 9 | classic Mac nostalgia | included |
| LinApple | Apple II emulation | dormant or pending confirmation |
| DOSBox-X / Windows 98 | retro Windows | experimental or pending confirmation |
| WeatherStar / Weather Channel kiosk | ambient retro weather | included |
| Flying Toasters | screensaver nostalgia | included |
| AOL simulator | early internet nostalgia | included |
| Netscape launcher | early internet nostalgia | included |
| Encarta | encyclopedia nostalgia | included |
| LimeWire | early internet nostalgia | included |
| Kid Pix | classic creative software | historical or pending confirmation |
| Winamp / QMMP style player | music nostalgia | included |

Some are practical. Some are there because the computer would feel wrong without them.

## Weather Channel kiosk

Known path:

```text
~/weather-channel/
```

Known files:

```text
weather-channel.sh
launch.html
satellite.png
```

The kiosk flow shows a satellite image first, then opens the WeatherStar web interface in Chromium kiosk/app mode.

## Archived repo files

The repository now archives the verified live service units and key helper/config snapshots. Use the service inventory in [../systemd/README.md](../systemd/README.md) as the scope-aware source for unit paths, enablement state, and recovery commands.

Archived scripts:

```text
scripts/apple_gesture_button.py
scripts/volume_knob.py
scripts/weather-channel.sh
scripts/usb-audio-loop.sh
```

Archived systemd units:

```text
systemd/system/apple-gesture-button.service
systemd/system/volume-knob.service
systemd/system/atease.service
systemd/system/flyingtoasters.service
systemd/user/piforma-panel.service
systemd/user/controlstrip-simulator.service
systemd/user/usb-audio-loop.service
```

Archived config snapshots:

```text
config/boot/firmware/config.txt
config/keyboard/default-keyboard
config/lxsession/rpd-x-autostart
config/lxsession/system-rpd-x-autostart
config/openbox/rpd-rc.xml
config/pcmanfm/desktop-items-0.conf
config/piforma-panel/config.yaml
config/control-strip/config.yaml
config/control-strip/scripts/window-check.sh
config/atease/config.yaml
config/atease/apps/
config/atease/apps-2/
config/sheepshaver/prefs
config/historical/lxpanel-pi/panel
config/historical/tint2/tint2rc
config/historical/atease-legacy/config.yaml
config/historical/pcmanfm-default/desktop-items-0.conf
```

See `config/README.md` for the verified archive status, restore paths, validation commands, and missing files such as `/home/frost/.asoundrc`.

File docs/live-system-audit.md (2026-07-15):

# Live System Audit Summary

This page summarizes the live PiForma software audit generated on 2026-06-23 and revised on 2026-07-05 with the newer apps and theme work.

> **Dated snapshot:** this page is historical. It was superseded by the July 14, 2026 Phase 1 and Phase 2 audits. Use `docs/software.md` for the current software architecture. Keep this file as a point-in-time audit record, not as the source of truth for active panel, launcher, or service state.

The audit matters because it captures what is actually running on the machine, not just what the build was supposed to be.

## Machine identity

| Item | Value |
|---|---|
| Hostname | `macintosh-piforma` |
| Primary user | `frost` |
| Board | Raspberry Pi 4 Model B, Rev 1.1 |
| OS base | Debian 13 / Trixie-style Raspberry Pi desktop stack |
| Session | X11, `rpd-x` |
| Window manager | Openbox |
| Display manager | LightDM |

## Active custom services

| Service | State | Purpose |
|---|---|---|
| `apple-gesture-button.service` | enabled, active | reads the Apple logo capacitive touch sensor on GPIO 23 and maps taps/holds to app launches and window actions |
| `atease.service` | enabled, active | starts the AtEase Tauri launcher shell at graphical target |
| `controlstrip-simulator.service` | enabled, active user unit | runs the Control Strip-style dock as a per-user graphical-session service |
| `flyingtoasters.service` | enabled, active | serves the local After Dark Flying Toasters web build on localhost port 3000 |
| `volume-knob.service` | enabled, active | reads the EC11 rotary encoder and controls PipeWire volume through `pactl` |
| `asplashscreen.service` | enabled, active oneshot | RetroPie VLC boot splash |

## Stock services worth knowing about

Running stock services include:

- LightDM
- NetworkManager
- wpa_supplicant
- PipeWire / WirePlumber
- Bluetooth
- CUPS
- Avahi
- cron
- ssh
- systemd-timesyncd

`pigpiod` is installed but inactive. The final GPIO scripts use `gpiozero` with `lgpio`, not pigpio.

`wayvnc-control.service` exists but is inactive because the system is using X11, not Wayland.

## Startup sequence

```text
Power on
  -> firmware reads /boot/firmware/config.txt
  -> kernel starts with quiet splash and Plymouth
  -> asplashscreen.service runs RetroPie VLC splash
  -> multi-user.target starts networking and support services
  -> graphical.target starts LightDM
  -> user frost enters rpd-x LXDE/Openbox session
  -> pcmanfm-pi and session autostart entries run
  -> custom graphical services start
```

Boot splash chain:

```text
Plymouth pix theme -> RetroPie asplashscreen -> LightDM -> desktop
```

Mac-style Plymouth themes are installed but not currently selected.

## GPIO integrations

| BCM pin | Hardware | Service | Function |
|---|---|---|---|
| GPIO 23 | capacitive touch pad behind Apple logo | `apple-gesture-button.service` | multi-tap and hold gestures |
| GPIO 17 | rotary encoder A | `volume-knob.service` | volume control |
| GPIO 27 | rotary encoder B | `volume-knob.service` | volume control |
| GPIO 22 | rotary encoder push | `volume-knob.service` | mute toggle in software |

All final GPIO code uses BCM numbering and `LGPIOFactory`.

## Apple logo gesture map

The deployed script lives at:

```text
/usr/local/bin/apple_gesture_button.py
```

The older copy at `~/apple_gesture_button.py` is a stale placeholder and should not be treated as source of truth.

Live gesture behavior:

| Gesture | Action |
|---|---|
| 1 tap | Chromium/Netscape style launcher |
| 2 taps | Mac OS 9 / SheepShaver |
| 3 taps | Winamp / QMMP |
| 4 taps | RetroPie / EmulationStation |
| hold 2 seconds | close active window |
| hold 6 seconds | close all windows and show desktop |
| hold 10 seconds | power off |

## Volume knob

The deployed script lives at:

```text
/usr/local/bin/volume_knob.py
```

It uses:

```text
RotaryEncoder(17, 27)
Button(22)
```

Each detent changes `@DEFAULT_SINK@` by roughly 2 percent through `pactl`.

Older scripts like `volume_control.py`, `volume_control2.py`, and `volume_knob.py_old` are superseded.

## Desktop theme state

Active visual stack:

| Area | Current choice |
|---|---|
| GTK theme | `Mac-OS-9-Platinum-Default` |
| Icons | `MoNine` |
| Cursor | `retrosmart-xcursor-black-color-shadow` |
| Font | `ChicagoFLF Medium 7` |
| Wallpaper | `~/atease-1.png` |
| Panel | Historical note: this audit revision listed `lxpanel-pi`, but the July 14, 2026 audit verified PiForma Panel as the active top panel |

Additional PiForma theme work exists in:

```text
~/.themes/PiForma-Platinum9-Classic
~/.themes/PiForma-PlatiPlus
~/.themes/PiForma-PlatiPlus26
~/.icons/PiForma-NineIcons
~/theme-lab/
```

## Desktop launchers

| Launcher | Backing app |
|---|---|
| Netscape | Chromium |
| America Online | Chromium kiosk to web AOL simulator |
| Encarta | Kiwix |
| Flying Toasters | Chromium kiosk to localhost:3000 |
| Kid Pix | Tux Paint |
| Macintosh HD | PCManFM home folder |
| Mac OS 9 | SheepShaver AppImage |
| RetroPie | EmulationStation |
| Winamp | QMMP |
| Weather Channel | local Weather Channel script |
| Terminal | LXTerminal |

## Weather Channel flow

```text
Desktop Weather Channel launcher
  -> ~/weather-channel/weather-channel.sh
  -> pkill chromium
  -> chromium kiosk fullscreen
  -> file:///home/frost/weather-channel/launch.html
  -> satellite.png splash for 3 seconds
  -> WeatherStar web emulator
```

Files:

```text
~/weather-channel/weather-channel.sh
~/weather-channel/launch.html
~/weather-channel/satellite.png
```

## Audio state

The live audit found PipeWire, WirePlumber, and `pipewire-pulse` active.

Known sinks include:

- GEMBIRD USB DAC, default output
- onboard 3.5mm audio
- HDMI audio

The volume knob controls `@DEFAULT_SINK@` through `pactl`.

The audit originally found the helper under the name `n64-audio-loop.sh`. It has since been renamed `usb-audio-loop.sh` because the helper supports any compatible external USB audio-input device and is not specific to Nintendo 64. It watches for the configured USB capture device and can loop external audio through the PiForma speakers when connected.

## Newer post-audit apps

The 2026-07-05 revision added the newer apps:

| App | Path | Purpose |
|---|---|---|
| AtEase | `~/atEase/` | fullscreen At Ease-style launcher shell |
| ControlStrip Simulator | `~/controlstrip-simualtor/` | transparent Mac-style Control Strip dock |
| Clippy | `~/clippy-rpi/` | local retro assistant |
| About This PiForma | `~/about-my-piforma/about-piforma-tauri/` | About This Mac-style info window |

Note the misspelling in the local ControlStrip directory: `controlstrip-simualtor`.

## Cleanup candidates

The audit identified old scripts, logs, and backups that can likely be archived once the live paths are copied into this repo.

Do not delete these without checking:

- `~/toggle-panel.sh`, still referenced
- `~/xdg.sh`, still referenced
- `/usr/local/bin/apple_gesture_button.py`, live source of truth
- `/usr/local/bin/volume_knob.py`, live source of truth

Good cleanup targets after review:

- old GPIO discovery scripts
- older home-directory placeholder gesture scripts
- old volume control iterations
- stale Weston logs
- old theme zip archives
- audit zip packages after they are preserved

## Best next archival step

Copy these from the Pi into this repo:

```text
/usr/local/bin/apple_gesture_button.py
/usr/local/bin/volume_knob.py
/etc/systemd/system/apple-gesture-button.service
/etc/systemd/system/volume-knob.service
/etc/systemd/system/atease.service
~/.config/systemd/user/controlstrip-simulator.service
~/.config/lxpanel-pi/panels/panel  # historical; July 2026 audit verified PiForma Panel as active
~/.config/openbox/rpd-rc.xml
~/.config/gtk-3.0/settings.ini
/boot/firmware/config.txt
~/weather-channel/
```

That is the difference between documentation and recoverability.

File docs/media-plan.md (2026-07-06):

# Media Plan

This project needs photos and video because the best parts are physical.

A wiring table can explain the build, but a shot of the original power switch waking the machine up will sell it in two seconds.

## Best video angle

Do not make the video about being a genius.

Make the machine the main character.

The pitch:

> This dead 1985 Apple IIc Monitor became a portable Raspberry Pi Macintosh fever dream with a boot chime selector, Bluetooth ADB keyboard, 3D printed mouse, Apple logo gestures, RetroPie, and a velvet-lined charging bag.

That is enough. The project is already interesting. It does not need chest-thumping.

## Title ideas

Best title:

```text
I Turned a Dead 1985 Apple Monitor into a Portable Raspberry Pi Macintosh
```

Other options:

```text
Macintosh PiForma: A Raspberry Pi Mac Built Inside an Apple IIc Monitor
This Dead Apple Monitor Became a Portable Retro Computer
I Built the Weird Macintosh Performa Apple Never Made
A Raspberry Pi, a Dead Apple Monitor, and Way Too Many HDMI Cables
```

## Thumbnail ideas

Use one strong image, not a clutter pile.

Best thumbnail:

- Macintosh PiForma powered on
- ADB keyboard next to it
- maybe the mouse visible
- Apple logo visible if possible

Short thumbnail text:

```text
Dead Monitor Reborn
```

Other options:

```text
Portable Pi Mac
1985 Apple Hack
Macintosh PiForma
```

## Video structure

### 0:00 to 0:30: cold open

Show the finished thing immediately.

Shots:

- dead-looking Apple monitor on desk
- flip original power switch
- boot chime plays
- screen lights up
- Apple logo tap launches app
- four taps opens RetroPie
- controller starts game
- quick shot of keyboard, mouse, bag

Voiceover idea:

```text
This started as a dead Apple IIc monitor from 1985. The CRT was gone, the case was too good to throw away, and I had this dumb idea stuck in my head for years. So I turned it into Macintosh PiForma.
```

### 0:30 to 1:30: what is it?

Explain the premise fast.

```text
It is not a restoration. It is not really a Hackintosh either. It is a Raspberry Pi 4 stuffed into an Apple IIc Monitor shell, dressed up like a Macintosh Performa that fell through a time portal.
```

Show:

- front
- rear ports
- side/profile
- keyboard
- mouse
- bag

### 1:30 to 3:30: show the fun features

Order matters. Start with the stuff normal people can understand.

1. Original power switch
2. Boot chime selector
3. Apple logo touch gestures
4. RetroPie without keyboard/mouse
5. Bluetooth ADB keyboard
6. 3D printed Apple-style mouse
7. Bag with wireless trickle charging

### 3:30 to 7:00: open it up

Show the inside.

Shots:

- shelf assembly
- Raspberry Pi on top shelf
- custom 5V JST rail
- LCD controller on middle shelf
- USB speaker on bottom shelf
- Anker battery wedged in rear
- battery plunger
- YS-M3 chime board and speaker
- source select wiring
- display ribbon taped down

Suggested line:

```text
The inside became a game of millimeters.
```

Another good line:

```text
This 5V rail is not fancy. It is perfboard, JST connectors, and solid-core wire. But it makes the whole thing serviceable.
```

### 7:00 to 9:00: show the ugly parts

People trust builds more when you show the failures.

Include:

- wrong display boards
- too many HDMI ribbons
- noisy Amazon power adapter causing EMI weirdness
- relay/touch source switching abandoned
- fragile LCD ribbon
- battery fit being too tight

Suggested line:

```text
A lot of this project was not genius. It was ordering every possible cable direction because I had no idea which way physics was going to betray me.
```

### 9:00 to 11:00: software world

Show the desktop and apps.

Shots:

- Mac OS 9-ish desktop
- AtEase
- ControlStrip
- About This PiForma
- Clippy
- Weather Channel
- Flying Toasters
- RetroPie
- SheepShaver / Mac OS 9
- Winamp / QMMP

Suggested line:

```text
This is not macOS. It is Raspberry Pi OS wearing a thrift-store Macintosh costume, and honestly that is kind of the point.
```

### 11:00 to end: close

Bring it back to the project feeling finished.

Suggested line:

```text
I do not think this is the most practical computer I own. But it might be the most complete expression of the kind of computer I wanted to build when I was reading Mac mod forums twenty years ago.
```

End with:

- boot chime
- Apple logo four taps
- game launch
- bag zip-up
- GitHub repo on screen

## Required photo list

Add these to `docs/images/`:

```text
front-beauty-shot.jpg
rear-panel.jpg
left-side.jpg
right-side.jpg
powered-on-desktop.jpg
atease-running.jpg
controlstrip-running.jpg
about-this-piforma.jpg
clippy-running.jpg
retropie-launch.jpg
weather-channel.jpg
flying-toasters.jpg
interior-open.jpg
shelf-assembly.jpg
power-rail.jpg
display-controller.jpg
battery-position.jpg
battery-plunger.jpg
boot-chime-selector.jpg
apple-logo-touch-sensor.jpg
keyboard-mod.jpg
mouse.jpg
bag-interior.jpg
bag-wireless-charger.jpg
monitor-stand.jpg
```

## B-roll checklist

- hand flipping original power switch
- boot chime selector click
- Apple logo tap sequence
- four taps launching RetroPie
- hold gesture closing game
- volume knob turning
- rear source switch cycling HDMI/RCA
- battery plunger press
- plugging in USB controller
- opening the bag
- setting PiForma into the charging grooves
- closing the bag
- closeup of the keyboard nice!view
- mouse movement on screen
- HDMI ribbon clearance shot
- display ribbon taped down

## The tone

Aim for:

```text
This is ridiculous. I love it. Here is how it works.
```

That tone gives people permission to enjoy the project without needing you to prove anything.

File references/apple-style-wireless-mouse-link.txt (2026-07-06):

TODO: add source link for the Apple-style 3D printed wireless mouse shell.

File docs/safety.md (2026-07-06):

# Safety

This build modifies a vintage monitor shell, reuses an AC inlet, contains a high-capacity lithium battery pack, and includes custom power wiring.

Do not copy the power wiring blindly.

## AC inlet warning

The original Apple IIc Monitor AC inlet is reused as part of the charging path.

In the final build:

- the AC inlet feeds an internal 100W USB power adapter
- the original monitor power switch does not switch mains AC
- the original power switch interrupts battery output to the 5V rail

This is safer than switching AC with the old monitor switch, but it still means there is AC wiring inside the case.

If reproducing:

- strain-relieve AC wiring
- insulate all AC connections
- keep AC wiring physically separated from low-voltage wiring
- do not leave exposed mains terminals
- do not route AC where it can rub against printed parts or sharp metal
- do not build this part if you are not comfortable with mains wiring

## Lithium battery warning

The build uses an Anker Prime 26K 300W battery.

The Anker handles battery management internally, but the build still physically traps a large battery inside an old monitor shell.

Do not:

- puncture the battery
- crush the battery
- block heat dissipation excessively
- use a swollen or damaged pack
- leave it charging unattended in a questionable state

## No custom rail fusing

The custom JST rail currently does not have separate fuse protection.

The build relies on the Anker and device protections.

If reproducing this, consider adding:

- a fuse on rail input
- per-output protection
- clear polarity markings
- strain relief
- wire gauge appropriate for load

## CRT warning

The donor CRT was removed years ago.

Anyone working with a vintage CRT monitor should understand that CRTs can hold dangerous voltages even after being unplugged. This documentation is for the finished LCD conversion, not a CRT repair guide.

## Heat

The build includes:

- Raspberry Pi 4B
- LCD driver
- internal USB power adapter
- Anker battery
- closed vintage plastic shell

Check heat under real use. Do not assume it is fine because it boots.

## The honest rule

If something smells hot, flickers weirdly, makes relays go crazy, causes touch sensors to false trigger, or behaves possessed, stop and debug power first.

That is not superstition. That is what already happened once.

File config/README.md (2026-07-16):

# PiForma Configuration Archive

## Purpose

This directory stores verified recovery snapshots for PiForma configuration files that are needed to rebuild the live `macintosh-piforma` desktop, launchers, panel layout, boot behavior, input defaults, and emulator preferences.

Configuration restore order and package prerequisites are documented in [../docs/software-installation.md](../docs/software-installation.md). The audited package state lives in [../docs/package-inventory.md](../docs/package-inventory.md) and [`../packages/`](../packages/).

The initial audit found that `config/` contained only this README. The files now archived here were copied from the live Pi during the July 2026 audit rather than recreated from documentation.

## Source-of-truth Policy

During the initial archival audit, the live Pi is the source of truth. Once a live file has been verified and imported here, the repository should become the maintained source for future revisions.

For future changes:

1. Compare the repository copy with the deployed file.
2. Import the verified live version if this archive is stale.
3. Make future changes in a Git branch.
4. Validate syntax and application-specific behavior.
5. Deploy the reviewed file to the Pi.
6. Restart the associated service or session component.
7. Verify logs and behavior.
8. Commit configuration and documentation changes together.

Do not replace a working live configuration with a file reconstructed from old notes. Also do not blindly restore files marked historical, fallback, missing, sanitized, hardware-specific, or unverified.

## Current Configuration Inventory

| Repository path | Live destination | Component | Status | Sanitized | Last verified |
|---|---|---|---|---|---|
| `config/boot/firmware/config.txt` | `/boot/firmware/config.txt` | Raspberry Pi firmware boot config | active | no | July 2026 audit |
| `config/keyboard/default-keyboard` | `/etc/default/keyboard` | Keyboard defaults | active | no | July 2026 audit |
| `config/lxsession/rpd-x-autostart` | `/home/frost/.config/lxsession/rpd-x/autostart` | User LXSession autostart | active user override | no | July 2026 audit |
| `config/lxsession/system-rpd-x-autostart` | `/etc/xdg/lxsession/rpd-x/autostart` | System LXSession autostart | system fallback | no | July 2026 audit |
| `config/openbox/rpd-rc.xml` | `/home/frost/.config/openbox/rpd-rc.xml` | Openbox window manager | active | no | July 2026 audit |
| `config/pcmanfm/desktop-items-0.conf` | `/home/frost/.config/pcmanfm/LXDE-pi/desktop-items-0.conf` | PCManFM desktop | active | no | July 2026 audit |
| `config/piforma-panel/config.yaml` | `/home/frost/.local/share/piforma-panel/config.yaml` | PiForma Panel | active | no | July 2026 audit |
| `config/control-strip/config.yaml` | `/home/frost/.local/share/control-strip/config.yaml` | Control Strip simulator | active | no | July 2026 audit |
| `config/control-strip/scripts/window-check.sh` | `/home/frost/.local/share/control-strip/scripts/window-check.sh` | Control Strip window detector | active helper | no | July 2026 audit |
| `config/atease/config.yaml` | `/home/frost/.local/share/atease/config.yaml` | AtEase shell | active | no | July 2026 audit |
| `config/atease/apps/*.desktop` | `/home/frost/.local/share/atease/apps/` | AtEase main folder launchers | active launcher configs | no | July 2026 audit |
| `config/atease/apps-2/*.desktop` | `/home/frost/.local/share/atease/apps-2/` | AtEase sites folder launchers | active launcher configs | no | July 2026 audit |
| `config/sheepshaver/prefs` | `/home/frost/.config/SheepShaver/prefs` | SheepShaver Mac OS 9 emulator | active for launcher | no | July 2026 audit |
| `config/historical/lxpanel-pi/panel` | `/home/frost/.config/lxpanel-pi/panels/panel` | LXPanel | historical fallback | no | July 2026 audit |
| `config/historical/tint2/tint2rc` | `/home/frost/.config/tint2/tint2rc` | tint2 | historical fallback | no | July 2026 audit |
| `config/historical/tint2/tint2rc_bak` | `/home/frost/.config/tint2/tint2rc_bak` | tint2 backup | historical fallback | no | July 2026 audit |
| `config/historical/atease-legacy/config.yaml` | `/home/frost/.config/atease/config.yaml` | older AtEase config path/schema | historical | no | July 2026 audit |
| `config/historical/pcmanfm-default/desktop-items-0.conf` | `/home/frost/.config/pcmanfm/default/desktop-items-0.conf` | older PCManFM profile | historical fallback | no | July 2026 audit |

The live `/boot/config.txt` file is only a pointer to `/boot/firmware/config.txt` on this Debian 13 Raspberry Pi installation and is not archived separately. `/home/frost/.asoundrc` and `/home/frost/.sheepshaver_prefs` were not found during the audit.

## Active Configurations

### Boot Firmware

`config/boot/firmware/config.txt` is the authoritative boot configuration. It preserves the live comments and PiForma-specific settings, including HDMI overscan margins, forced HDMI hotplug, disabled splash, UART enablement, VC4 KMS graphics, onboard audio enablement, CM4 USB OTG host behavior, and CM5 USB host overlay behavior.

The archived file should be restored to `/boot/firmware/config.txt`, not `/boot/config.txt`.

### Keyboard

`config/keyboard/default-keyboard` archives `/etc/default/keyboard`. The live file uses the US keyboard layout and sets `XKBOPTIONS="ctrl:swap_lwin_lctl"`, which affects modifier behavior on the PiForma keyboard setup.

### LXSession Autostart

The live user override and the system default both contain only:

```text
@pcmanfm-pi
@xscreensaver -no-splash
```

PiForma Panel, Control Strip, and AtEase are handled by services rather than by this autostart file. Restoring an older autostart that starts those components directly could create duplicate launches.

### Openbox

`config/openbox/rpd-rc.xml` is the active Openbox configuration. The live session is running `openbox --config-file /home/frost/.config/openbox/rpd-rc.xml`.

This snapshot includes PiForma-specific window placement and application rules, including behavior for the panel, Control Strip, AtEase, Clippy, fullscreen windows, decorations, focus, and desktop count. Restore it as a full file unless a later migration deliberately changes the window-manager policy.

### PCManFM Desktop

`config/pcmanfm/desktop-items-0.conf` controls the active PCManFM desktop profile. The live file uses a black color background, ChicagoFLF desktop font, no window-manager desktop menu, no thumbnails, trash icon visible, and mounted volumes hidden.

The historical default PCManFM profile is archived separately under `config/historical/pcmanfm-default/`.

### PiForma Panel

`config/piforma-panel/config.yaml` is the active PiForma Panel configuration. The live `piforma-panel.service` runs `/usr/bin/piforma-panel`, and the verified configuration path is `/home/frost/.local/share/piforma-panel/config.yaml`.

The file defines the panel size and position, top corner radii, Charcoal font settings, Apple logo path, clock format, application scan directories, menu visibility, and desktop applications that should continue showing while the panel is active.

The checked source code recognizes the `bar`, `apple`, `clock`, `applications`, `menus`, `actions`, and `diagnostics` sections. The live file also includes `show_desktop_apps`; preserve that key when restoring because it is part of the deployed configuration even though it was not present in the checked source schema.

### Control Strip

`config/control-strip/config.yaml` is the active Control Strip configuration and `config/control-strip/scripts/window-check.sh` is the archived helper script from `/home/frost/.local/share/control-strip/scripts/window-check.sh`.

The live `controlstrip-simulator.service` runs `/usr/bin/controlstrip-simulator` with `WorkingDirectory=%h/.local/share/control-strip`. The configuration defines window geometry, visible icon behavior, snap-back timing, rounded bottom-left screen corner behavior, filtered window classes, and pinned applications for Chromium, LXTerminal, and PCManFM.

The Control Strip source checkout on the Pi uses the misspelled path `/home/frost/controlstrip-simualtor`. Do not silently correct that path in source or service references; treat it as an operational detail until a coordinated migration is made.

### AtEase

`config/atease/config.yaml`, `config/atease/apps/`, and `config/atease/apps-2/` archive the current AtEase configuration. The live `atease.service` runs `/usr/bin/atease`.

The current config uses the newer `/home/frost/.local/share/atease/config.yaml` layout with render geometry, window behavior, two folders, and `startup_folder: main`. An older schema still exists at `/home/frost/.config/atease/config.yaml` and is archived as historical only.

### SheepShaver

`config/sheepshaver/prefs` archives the active SheepShaver preference file referenced by the Mac OS 9 AtEase launcher. It contains local paths for the disk image, ROM, shared folder, serial port, and display settings.

The ROM, disk images, and other binary emulator assets are not stored in this configuration archive. They must be supplied separately during recovery.

## Historical And Fallback Configurations

`config/historical/lxpanel-pi/panel` is preserved because the old desktop stack used LXPanel-style configuration, but no `lxpanel` process was active during the audit. PiForma Panel is the active top panel.

`config/historical/tint2/` is preserved because tint2 configuration files exist on the live system, but no `tint2` process was active during the audit.

`config/historical/atease-legacy/config.yaml` preserves the older AtEase configuration path and schema. It should not be restored over the current `.local/share/atease` configuration without checking the installed AtEase build.

`config/historical/pcmanfm-default/desktop-items-0.conf` preserves the older default PCManFM profile. The active profile is `LXDE-pi`.

## AtEase Launchers

These `.desktop` files were copied from the live AtEase folders. The executable targets were checked during the audit; all were present. `desktop-file-validate` reports category-field errors in several copied live launchers, and the Space Jam launcher references a missing icon file. These files are preserved as live snapshots rather than silently rewritten during archival.

| Launcher | Repository file | Live file | Exec target | Notes |
|---|---|---|---|---|
| America Online | `config/atease/apps/America Online.desktop` | `/home/frost/.local/share/atease/apps/America Online.desktop` | `chromium` | Chromium kiosk web app |
| Netscape | `config/atease/apps/Chromium-70.desktop` | `/home/frost/.local/share/atease/apps/Chromium-70.desktop` | `chromium` | Uses `--force-device-scale-factor=0.7` |
| Encarta | `config/atease/apps/Encarta.desktop` | `/home/frost/.local/share/atease/apps/Encarta.desktop` | `flatpak` | Runs `org.kiwix.desktop` |
| Flying Toasters | `config/atease/apps/FlyingToasters.desktop` | `/home/frost/.local/share/atease/apps/FlyingToasters.desktop` | `chromium` | Chromium kiosk to localhost; companion HTTP server is `flyingtoasters.service` |
| LimeWire | `config/atease/apps/LimeWire.desktop` | `/home/frost/.local/share/atease/apps/LimeWire.desktop` | `chromium` | Chromium kiosk web app |
| Mac OS 9 | `config/atease/apps/MacOS9.desktop` | `/home/frost/.local/share/atease/apps/MacOS9.desktop` | `/home/frost/emulation/SheepShaver-aarch64.AppImage` | Uses archived SheepShaver prefs |
| Macintosh HD | `config/atease/apps/Macintosh-HD.desktop` | `/home/frost/.local/share/atease/apps/Macintosh-HD.desktop` | `pcmanfm` | Opens `/home/frost` |
| Retropie | `config/atease/apps/Retropie.desktop` | `/home/frost/.local/share/atease/apps/Retropie.desktop` | `lxterminal` | Runs `emulationstation --debug` |
| Terminal | `config/atease/apps/Terminal.desktop` | `/home/frost/.local/share/atease/apps/Terminal.desktop` | `/usr/bin/lxterminal` | Opens zsh |
| Weather Channel | `config/atease/apps/Weather Channel.desktop` | `/home/frost/.local/share/atease/apps/Weather Channel.desktop` | `/home/frost/weather-channel/weather-channel.sh` | Custom script discovered through launcher |
| Winamp | `config/atease/apps/Winamp.desktop` | `/home/frost/.local/share/atease/apps/Winamp.desktop` | `qmmp` | Music player launcher |
| Cameron's World | `config/atease/apps-2/01-camerons-world.desktop` | `/home/frost/.local/share/atease/apps-2/01-camerons-world.desktop` | `chromium` | Uses `--force-device-scale-factor=0.7` |
| Homestar Runner | `config/atease/apps-2/02-homestar-runner.desktop` | `/home/frost/.local/share/atease/apps-2/02-homestar-runner.desktop` | `chromium` | Uses `--force-device-scale-factor=0.7` |
| Space Jam 1996 | `config/atease/apps-2/03-space-jam-1996.desktop` | `/home/frost/.local/share/atease/apps-2/03-space-jam-1996.desktop` | `chromium` | Icon path missing: `/home/frost/.local/share/icons/space-jam-1996.png` |
| Windows 93 | `config/atease/apps-2/04-windows-93.desktop` | `/home/frost/.local/share/atease/apps-2/04-windows-93.desktop` | `chromium` | Uses `--force-device-scale-factor=0.7` |
| Infinite Mac | `config/atease/apps-2/05-infinite-mac.desktop` | `/home/frost/.local/share/atease/apps-2/05-infinite-mac.desktop` | `chromium` | Uses `--force-device-scale-factor=0.7` |
| Shareware CDs | `config/atease/apps-2/06-shareware-cds.desktop` | `/home/frost/.local/share/atease/apps-2/06-shareware-cds.desktop` | `chromium` | Uses `--force-device-scale-factor=0.7` |
| TEXTFILES.COM | `config/atease/apps-2/07-textfiles.desktop` | `/home/frost/.local/share/atease/apps-2/07-textfiles.desktop` | `chromium` | Uses `--force-device-scale-factor=0.7` |
| Neocities | `config/atease/apps-2/08-neocities.desktop` | `/home/frost/.local/share/atease/apps-2/08-neocities.desktop` | `chromium` | Uses `--force-device-scale-factor=0.7` |
| The Old Net | `config/atease/apps-2/09-the-old-net.desktop` | `/home/frost/.local/share/atease/apps-2/09-the-old-net.desktop` | `chromium` | Uses `--force-device-scale-factor=0.7` |
| Web Design Museum | `config/atease/apps-2/10-web-design-museum.desktop` | `/home/frost/.local/share/atease/apps-2/10-web-design-museum.desktop` | `chromium` | Uses `--force-device-scale-factor=0.7` |

The Weather Channel launcher is the only archived launcher that directly invokes a custom shell script. Other launchers invoke Chromium, Flatpak, PCManFM, SheepShaver, EmulationStation through LXTerminal, LXTerminal itself, or QMMP. Launcher validation currently reports unregistered or incomplete `Categories` values for America Online, Encarta, LimeWire, Macintosh HD, Weather Channel, and Winamp; those values match the deployed files.

## Permissions And Ownership

The archive preserves live file modes. Important examples from the audit:

| Live file | Owner | Mode |
|---|---|---|
| `/boot/firmware/config.txt` | `root:root` | `755` |
| `/etc/default/keyboard` | `root:root` | `644` |
| `/home/frost/.config/openbox/rpd-rc.xml` | `frost:frost` | `644` |
| `/home/frost/.local/share/control-strip/scripts/window-check.sh` | `frost:frost` | `755` |
| `/home/frost/.local/share/atease/apps/*.desktop` | `frost:frost` | `775` |
| `/home/frost/.local/share/atease/apps-2/*.desktop` | `frost:frost` | `755` |

Executable helper scripts and launchers should retain executable mode. Service files belong under `systemd/system/` or `systemd/user/`, not in `config/`.

Check repository modes with:

```bash
git ls-files --stage config/
```

Check live modes with:

```bash
stat -c '%A %a %U:%G %n' /path/to/live/file
```

## Validation

Use format-specific validation after importing or editing files:

```bash
python3 - <<'PY'
import pathlib
import yaml

for path in pathlib.Path("config").rglob("*.yaml"):
    with path.open("r", encoding="utf-8") as handle:
        yaml.safe_load(handle)
    print(f"OK: {path}")
PY

xmllint --noout config/openbox/rpd-rc.xml
bash -n config/control-strip/scripts/window-check.sh
desktop-file-validate config/atease/apps/*.desktop
desktop-file-validate config/atease/apps-2/*.desktop
```

If `xmllint` is unavailable, use Python XML parsing:

```bash
python3 - <<'PY'
import xml.etree.ElementTree as ET
ET.parse("config/openbox/rpd-rc.xml")
print("OK: config/openbox/rpd-rc.xml")
PY
```

YAML parsing only proves syntax. For PiForma Panel, Control Strip, and AtEase, compare keys against the installed application source or the current documented schema before changing behavior.

## Comparing Before Copying

Always compare before importing from the live Pi or restoring to it:

```bash
diff -u \
  config/piforma-panel/config.yaml \
  /home/frost/.local/share/piforma-panel/config.yaml

diff -u \
  config/control-strip/config.yaml \
  /home/frost/.local/share/control-strip/config.yaml

diff -ruN \
  config/atease/apps \
  /home/frost/.local/share/atease/apps
```

For a verified import from live to repository:

```bash
cp --preserve=mode,timestamps \
  /home/frost/.local/share/control-strip/scripts/window-check.sh \
  config/control-strip/scripts/window-check.sh
```

For a reviewed restore from repository to live, use the matching destination from the inventory table, then restart or reload the owning component. For example:

```bash
cp --preserve=mode,timestamps \
  config/piforma-panel/config.yaml \
  /home/frost/.local/share/piforma-panel/config.yaml

systemctl --user restart piforma-panel.service
systemctl --user status piforma-panel.service --no-pager
```

Do not use the historical files as restore inputs unless you are intentionally rolling back to an older desktop stack.

## Sensitive Data Policy

The audit did not find passwords, tokens, private keys, API keys, Wi-Fi credentials, browser cookies, SSH keys, or private certificates in the archived files.

The SheepShaver prefs include local emulator asset paths, but not the ROM or disk images themselves. Those supporting binary files are intentionally excluded.

These locations are intentionally excluded from this archive unless a separate sanitized backup strategy is requested:

```text
/etc/NetworkManager/system-connections/
/home/frost/.ssh/
/home/frost/.config/chromium/
/home/frost/.mozilla/
```

If a future configuration file contains a required private value, replace only the repository snapshot with a clear marker such as `REDACTED_NOT_STORED_IN_REPOSITORY` and document that the archived file cannot be copied blindly.

## Missing Or Not Archived

| Live path | Status | Reason |
|---|---|---|
| `/boot/config.txt` | not archived | Stub pointing to `/boot/firmware/config.txt` |
| `/home/frost/.asoundrc` | not found | Current audio services do not depend on an archived ALSA dotfile |
| `/home/frost/.sheepshaver_prefs` | not found | Active SheepShaver prefs are under `.config/SheepShaver/prefs` |
| Browser profiles and caches | intentionally excluded | Runtime state and possible secrets |
| NetworkManager connections | intentionally excluded | Wi-Fi/network credentials |
| SSH configuration and keys | intentionally excluded | private credentials |

## Related Documentation

- [Software overview](../docs/software.md)
- [Maintenance guide](../docs/maintenance.md)
- [Live system audit](../docs/live-system-audit.md) is a dated snapshot, not the current source of truth.
- [Scripts archive](../scripts/README.md)
- [Systemd archive](../systemd/README.md)

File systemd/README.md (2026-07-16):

# PiForma systemd Services

## Purpose

This directory archives the verified systemd unit files from the live `macintosh-piforma` Pi. It is a recovery and maintenance reference, not a place for reconstructed service files.

Audit date: 2026-07-15.

Service package dependencies and rebuild profiles are documented in [../docs/package-inventory.md](../docs/package-inventory.md) and [../docs/software-installation.md](../docs/software-installation.md).

## System Units And User Units

System units are installed under `/etc/systemd/system/` and managed with `systemctl`. PiForma currently uses system units for GPIO hardware helpers, AtEase, and the Flying Toasters local web server.

User units are installed under `/home/frost/.config/systemd/user/` and managed with `systemctl --user` from the `frost` user manager. PiForma currently uses user units for graphical desktop components and the USB audio loop.

Running `systemctl status` without `--user` will not show a user unit.

## Source-Of-Truth Policy

1. During the initial audit, the installed live unit is the source of truth.
2. Import the verified live unit into Git.
3. After archival, make future service changes in this repository.
4. Validate the edited unit.
5. Deploy it to the correct system or user location.
6. Run the matching daemon reload.
7. Restart only the affected service.
8. Verify service state, logs, and actual behavior.
9. Commit implementation and documentation changes together.

Do not normalize or redesign a working unit during import unless the live system has a verified defect or a deliberate migration requires it.

## Current Service Inventory

Observed active state is a point-in-time audit result, not a permanent guarantee.

| Unit | Scope | Purpose | Live fragment path | Repository path | Enabled | Active | Started after | Exec target | Last verified |
|---|---|---|---|---|---|---|---|---|---|
| `apple-gesture-button.service` | system | Apple-logo touch gesture handler | `/etc/systemd/system/apple-gesture-button.service` | `systemd/system/apple-gesture-button.service` | enabled | active/running | `graphical.target`, `display-manager.service` | `/usr/bin/python3` -> `/usr/local/bin/apple_gesture_button.py` | 2026-07-15 |
| `volume-knob.service` | system | EC11 GPIO volume knob | `/etc/systemd/system/volume-knob.service` | `systemd/system/volume-knob.service` | enabled | active/running | `graphical.target` | `/usr/bin/python3` -> `/usr/local/bin/volume_knob.py` | 2026-07-15 |
| `atease.service` | system | AtEase launcher shell | `/etc/systemd/system/atease.service` | `systemd/system/atease.service` | enabled | active/running | `display-manager.service`, `graphical.target` | `/usr/bin/atease` | 2026-07-15 |
| `flyingtoasters.service` | system | Local Flying Toasters HTTP server | `/etc/systemd/system/flyingtoasters.service` | `systemd/system/flyingtoasters.service` | enabled | active/running | `network.target` | `/usr/bin/python3` | 2026-07-15 |
| `piforma-panel.service` | user | PiForma top panel | `/home/frost/.config/systemd/user/piforma-panel.service` | `systemd/user/piforma-panel.service` | enabled | active/running | `graphical-session.target` | `/usr/bin/piforma-panel` | 2026-07-15 |
| `controlstrip-simulator.service` | user | Control Strip simulator | `/home/frost/.config/systemd/user/controlstrip-simulator.service` | `systemd/user/controlstrip-simulator.service` | enabled | active/running | `graphical-session.target` | `/usr/bin/controlstrip-simulator` | 2026-07-15 |
| `usb-audio-loop.service` | user | External USB audio-input loop | `/home/frost/.config/systemd/user/usb-audio-loop.service` | `systemd/user/usb-audio-loop.service` | enabled | active/running | default user target | `/home/frost/bin/usb-audio-loop.sh` | 2026-07-15 |

No PiForma-specific drop-ins were found for these units.

`n64-audio-loop.service` was checked and was `not-found`. Keep that old name only in historical migration notes.

## Startup Relationships

| Component | System service | User service | LXSession autostart | XDG autostart | Openbox autostart | Desktop launcher only | AtEase launcher only | Manual command | Application self-start | Duplicate automatic startup |
|---|---|---|---|---|---|---|---|---|---|---|
| Apple gesture button | yes | no | no | no | no | no | no | no | no | no |
| Volume knob | yes | no | no | no | no | no | no | no | no | no |
| AtEase | yes | no | no | no | no | yes, `/usr/share/applications/AtEase.desktop` | no | possible | no | no |
| Flying Toasters server | yes | no | no | no | no | no | paired with AtEase Chromium launcher | possible | no | no |
| PiForma Panel | no | yes | no | no | no | yes, `/usr/share/applications/PiForma Panel.desktop` | no | possible | no | no |
| Control Strip | no | yes | no | no | no | yes, `/usr/share/applications/ControlStrip Simulator.desktop` | no | possible | no | no |
| USB audio loop | no | yes | no | no | no | no | no | possible | no | no |
| Clippy | no | no | no | yes, `/home/frost/.config/autostart/clippy.desktop` | no | yes | no | possible | no | not a systemd duplicate |

The visible `.desktop` files for AtEase, PiForma Panel, and Control Strip are manual launchers, not automatic startup paths. LXSession autostart contains only `pcmanfm-pi` and `xscreensaver` in the inspected files. Openbox autostart has no PiForma service launches.

`/etc/xdg/autostart/env-display.desktop` runs `dbus-update-activation-environment --systemd DISPLAY WAYLAND_DISPLAY`, which helps imported graphical environment state reach the user manager.

## System Services

### `apple-gesture-button.service`

Runs as `User=frost` from `/home/frost`:

```ini
ExecStart=/usr/bin/python3 /usr/local/bin/apple_gesture_button.py
Restart=always
RestartSec=1
```

The script monitors GPIO 23 through `gpiozero` with `LGPIOFactory`. It maps taps to desktop launchers under `/home/frost/Desktop` and timed holds to closing windows, showing the desktop, or running `sudo /bin/systemctl poweroff`.

Although this is a system unit, it launches user desktop actions by running as `frost` and setting:

```text
HOME=/home/frost
DISPLAY=:0
XAUTHORITY=/home/frost/.Xauthority
XDG_RUNTIME_DIR=/run/user/1000
DBUS_SESSION_BUS_ADDRESS=unix:path=/run/user/1000/bus
```

The live script exists and is executable. During the audit it was owned by `nobody:nogroup`, mode `0755`; that ownership is unusual for a system-executed helper and should be reviewed before future hardening.

### `volume-knob.service`

Runs as `User=frost` from `/home/frost`:

```ini
ExecStart=/usr/bin/python3 /usr/local/bin/volume_knob.py
Restart=always
RestartSec=1
```

The script reads the EC11 rotary encoder on GPIO 17 and 27 and the push switch on GPIO 22. It controls the PipeWire-compatible default sink with `pactl`, not direct ALSA mixer calls. The service supplies `XDG_RUNTIME_DIR=/run/user/1000` so `pactl` can reach the `frost` user audio session.

The live script exists and is executable. It was also owned by `nobody:nogroup`, mode `0755`; review that ownership before future hardening.

### `atease.service`

Runs AtEase as a system service under the `frost` user:

```ini
ExecStart=/usr/bin/atease
Restart=on-failure
RestartSec=2
```

The unit sets `DISPLAY=:0`, `XAUTHORITY=/home/frost/.Xauthority`, and `XDG_RUNTIME_DIR=/run/user/1000`. It does not set `DBUS_SESSION_BUS_ADDRESS`. The AtEase process was active during the audit and launched applications through `gio` from `/home/frost/.local/share/atease/apps/`.

AtEase also has a normal application launcher at `/usr/share/applications/AtEase.desktop`; that launcher is manual and is not an automatic duplicate.

The journal showed recurring Chromium D-Bus warnings from GUI applications launched by AtEase. These were not observed to stop the service.

### `flyingtoasters.service`

Runs a local static HTTP server as `frost`:

```ini
WorkingDirectory=/home/frost/.local/share/flyingtoasters/build
ExecStart=/usr/bin/python3 -m http.server 3000 --bind 127.0.0.1
Restart=always
RestartSec=3
```

The server listens on `127.0.0.1:3000`, so it is not exposed beyond localhost by this unit. Chromium is launched separately by the AtEase launcher `/home/frost/.local/share/atease/apps/FlyingToasters.desktop`.

The working directory exists. The journal showed normal local GET traffic and repeated 404s for `/joemama`; no restart loop was observed.

## User Services

### `piforma-panel.service`

Runs the PiForma top panel in the `frost` user manager:

```ini
ExecStart="/usr/bin/piforma-panel"
Restart=on-failure
RestartSec=2
After=graphical-session.target
PartOf=graphical-session.target
```

The binary exists and is executable. The service relies on the user manager's imported graphical environment. During the audit, `systemctl --user show-environment` included `DISPLAY=:0`, `XAUTHORITY=/home/frost/.Xauthority`, `DBUS_SESSION_BUS_ADDRESS=unix:path=/run/user/1000/bus`, `XDG_RUNTIME_DIR=/run/user/1000`, and `XDG_SESSION_TYPE=x11`.

The panel is the custom menu bar and should not be duplicated by LXPanel or tint2 startup entries.

### `controlstrip-simulator.service`

Runs the Control Strip in the `frost` user manager:

```ini
ExecStart=/usr/bin/controlstrip-simulator
WorkingDirectory=%h/.local/share/control-strip
Restart=on-failure
RestartSec=2
After=graphical-session.target
PartOf=graphical-session.target
```

The binary and working directory exist. It uses the live configuration under `/home/frost/.local/share/control-strip`. The source checkout on the Pi is known to use the misspelled path `/home/frost/controlstrip-simualtor`; do not silently correct that operational path unless every reference is migrated together.

The status log showed active window placement and a non-fatal duplicate `.desktop` match for `About-piforma`.

### `usb-audio-loop.service`

Runs the canonical external USB audio loop helper:

```ini
ExecStart=%h/bin/usb-audio-loop.sh
Restart=always
```

The service runs `/home/frost/bin/usb-audio-loop.sh`. The old `n64-audio-loop.sh` and `n64-audio-loop.service` names are retired.

The script checks every five seconds for this PipeWire/PulseAudio source:

```text
alsa_input.usb-C-Media_Electronics_Inc._Cable_Creation-00.mono-fallback
```

When present, it sets the source volume to `50%` and starts `pw-loopback --capture="$SOURCE"` if `pgrep -f "$SOURCE"` does not already find a matching process. The supervising script stays active while the USB device is absent. It uses `pactl` and `pw-loopback`; it does not use `arecord`, `aplay`, `parec`, or `pacat` in the current live script.

## Installing Units

Install only units that are intended to be present and enabled on the target system.

System unit example:

```bash
sudo install -m 0644 \
  systemd/system/UNIT.service \
  /etc/systemd/system/UNIT.service

sudo systemctl daemon-reload
sudo systemctl enable UNIT.service
sudo systemctl restart UNIT.service
systemctl status UNIT.service --no-pager
```

User unit example:

```bash
install -m 0644 \
  systemd/user/UNIT.service \
  /home/frost/.config/systemd/user/UNIT.service

systemctl --user daemon-reload
systemctl --user enable UNIT.service
systemctl --user restart UNIT.service
systemctl --user status UNIT.service --no-pager
```

Do not enable every archived unit indiscriminately. Enabled state is deployment metadata, not unit source.

## Enabling And Disabling Units

Common unit-file states:

- `enabled`: starts through an install target.
- `disabled`: installed but not linked into an install target.
- `static`: has no independent enablement configuration.
- `indirect`: enabled through another unit relationship.
- `masked`: deliberately prevented from starting.
- `generated`: created dynamically.
- `not-found`: stale reference or missing unit.

This archive does not include `.wants/` or `.requires/` symlinks. Recreate enablement with `systemctl enable` or `systemctl --user enable` only when the target deployment should start that service.

## Validating Units

Repository validation commands:

```bash
systemd-analyze verify systemd/system/*.service
systemd-analyze --user verify systemd/user/*.service
grep -RIn '^ExecStart=' systemd/
grep -RIn '^WorkingDirectory=' systemd/
grep -RIn '^EnvironmentFile=' systemd/
```

Audit result: `systemd-analyze --user verify systemd/user/*.service` succeeded. `systemd-analyze verify systemd/system/*.service` could not run in the sandboxed shell because the system bus check failed with `SO_PASSCRED failed: Operation not permitted`; validate the system units on the Pi console or an unrestricted shell before deployment.

Syntax validation does not prove that the executable, display, D-Bus session, audio server, or working directory is available.

## Viewing Service Status And Logs

System services:

```bash
systemctl status UNIT.service --no-pager
journalctl -u UNIT.service -b --no-pager
systemctl cat UNIT.service
systemctl show UNIT.service
```

User services:

```bash
systemctl --user status UNIT.service --no-pager
journalctl --user -u UNIT.service -b --no-pager
systemctl --user cat UNIT.service
systemctl --user show UNIT.service
```

If running through `sudo` or from another account, make sure `systemctl --user` is querying the `frost` user manager, not root's user manager.

## Linger And Login Behavior

`loginctl show-user frost` could not be queried from this sandbox because the system bus was unavailable. User services were successfully queried through the active `frost` user manager, and the observed user environment had an active X11 `rpd-x` session.

Do not enable lingering automatically. Graphical user services generally should start after the graphical session exists. Persistent background user services can use lingering when intentionally configured, but audio and X11 applications may still fail without an active session even if lingering is enabled.

## Updating A Service

1. Edit the repository unit.
2. Run the relevant `systemd-analyze verify` command.
3. Check every `ExecStart=`, `WorkingDirectory=`, and `EnvironmentFile=` path.
4. Deploy only the affected unit.
5. Run `systemctl daemon-reload` or `systemctl --user daemon-reload`.
6. Restart only the affected service.
7. Check status, logs, and actual user-visible behavior.

## Recovery Procedure

For a broken system service:

```bash
sudo install -m 0644 systemd/system/UNIT.service /etc/systemd/system/UNIT.service
sudo systemctl daemon-reload
sudo systemctl restart UNIT.service
systemctl status UNIT.service --no-pager
journalctl -u UNIT.service -b --no-pager
```

For a broken user service:

```bash
install -m 0644 systemd/user/UNIT.service /home/frost/.config/systemd/user/UNIT.service
systemctl --user daemon-reload
systemctl --user restart UNIT.service
systemctl --user status UNIT.service --no-pager
journalctl --user -u UNIT.service -b --no-pager
```

If a graphical service fails, confirm `DISPLAY`, `XAUTHORITY`, `DBUS_SESSION_BUS_ADDRESS`, and `XDG_RUNTIME_DIR` in `systemctl --user show-environment`.

## Historical And Retired Units

- `n64-audio-loop.service`: obsolete name, `not-found` during this audit. Use `usb-audio-loop.service`.
- `n64-audio-loop.sh`: obsolete script name. Use `/home/frost/bin/usb-audio-loop.sh`.
- `asplashscreen.service`: present on the system as a RetroPie boot splash unit, but not archived here because it was outside the PiForma-specific service set for this task.
- `app-clippy@autostart.service`: generated from XDG autostart, not a hand-authored PiForma unit.
- `pipewire-media-session.service`, `pipewire-session-manager.service`, and `pulseaudio.service`: stale/not-found user references shown by `systemctl --user list-units --all`; current audio uses PipeWire and WirePlumber.

## Security Notes

- PiForma system services are configured with absolute paths and run as `frost`, not root, except for systemd itself supervising them.
- `apple-gesture-button.service` intentionally allows a desktop gesture to request shutdown through `sudo /bin/systemctl poweroff`; keep the corresponding sudoers rule narrow.
- The live `/usr/local/bin/apple_gesture_button.py`, `/usr/local/bin/volume_knob.py`, `/usr/bin/atease`, `/usr/bin/piforma-panel`, and `/usr/bin/controlstrip-simulator` were owned by `nobody:nogroup` during the audit. That is unusual for executable deployment paths and should be reviewed before any hardening pass.
- `flyingtoasters.service` binds to `127.0.0.1`, limiting exposure to localhost.
- No `EnvironmentFile=` directives were found, and no secrets were copied.
- `/home/frost/bin/usb-audio-loop.sh` and several working directories are user-writable by `frost`; this is expected for user services but should not be reused from root-running units without review.

## Related Documentation

- [Software](../docs/software.md)
- [Maintenance](../docs/maintenance.md)
- [Scripts](../scripts/README.md)
- [Config archive](../config/README.md)
- [Historical live audit](../docs/live-system-audit.md)

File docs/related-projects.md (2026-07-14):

# Related Projects

Macintosh PiForma is the hardware build, but the full experience now spans several companion repos.

This page keeps those pieces tied together so the project does not look like a random pile of separate apps.

## Project map

| Project | Repo | What it is | Role in PiForma |
|---|---|---|---|
| Macintosh PiForma docs | https://github.com/milagrofrost/Macintosh-PiForma-docs | documentation repo | build docs, BOM, wiring, maintenance, photos, STLs |
| PiForma Panel | https://github.com/milagrofrost/piforma-panel | Tauri top panel | active Macintosh-style menu bar |
| AtEase Simulator | https://github.com/milagrofrost/AtEase-simulator | Tauri launcher shell | full-screen At Ease-style app launcher |
| ControlStrip Simulator | https://github.com/milagrofrost/ControlStrip-Simulator | Tauri dock/control strip | Mac OS-style utility strip and app focus helper |
| About This PiForma | https://github.com/milagrofrost/about-this-pi | About This Mac-style app | shows PiForma system info and top-memory apps |
| Clippy PiForma fork | https://github.com/milagrofrost/clippy-rpi | forked retro AI assistant | desktop personality layer |
| Flight of the Toasters | https://github.com/milagrofrost/Flight-of-the-Toasters | local web app | Flying Toasters launcher backend |

## How they fit together

```mermaid
flowchart TD
    PiForma[Macintosh PiForma hardware] --> OS[Raspberry Pi OS / Debian desktop]
    OS --> Theme[Mac OS 9-ish theme, icons, fonts]
    OS --> Panel[PiForma Panel]
    OS --> AtEase[AtEase Simulator]
    OS --> ControlStrip[ControlStrip Simulator]
    OS --> About[About This PiForma]
    OS --> Clippy[Clippy]
    OS --> Retro[RetroPie and nostalgia launchers]

    AtEase --> Launchers[AtEase launcher folders and .desktop files]
    ControlStrip --> WindowMgmt[X11 window detection and focus]
    About --> SystemInfo[Pi model, OS, memory, top apps]
    Clippy --> Assistant[local assistant / retro personality]
```

## AtEase Simulator

Repo:

```text
https://github.com/milagrofrost/AtEase-simulator
```

Role:

- replaces a normal Linux desktop launcher with an At Ease-style shell
- gives PiForma a simple front-end for launching the curated app set
- runs as `atease.service`
- uses `~/.local/share/atease/config.yaml`
- reads launcher files from `~/.local/share/atease/apps/` and `~/.local/share/atease/apps-2/`
- launches through `.desktop` files instead of arbitrary front-end commands

Why it matters:

AtEase makes the machine feel like something you can hand to a kid, a friend, or your future self without explaining Linux menus.
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

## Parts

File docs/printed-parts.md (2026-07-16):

# Printed Parts

The `stl/` directory contains the normalized printable and editable model files used in the finished Macintosh PiForma build. These are custom mechanical parts for the Apple IIc Monitor enclosure, internal electronics, controls, display, and external stand.

Most hidden internal parts were printed from whatever filament was available. The current internal rack was printed in brown PETG. Dark colors work well inside the case because they disappear visually. PETG or another heat-tolerant material is strongly preferred for parts near the Raspberry Pi.

For file-specific warnings, original-to-normalized filename mapping, and SHA-256 hashes, see:

- [`../stl/README.md`](../stl/README.md)
- [`../stl/file-manifest.tsv`](../stl/file-manifest.tsv)

## Important 3MF warning

The `.3mf` files were created or saved with **Microsoft 3D Builder**. They are not Bambu Studio project files. Bambu Studio and other slicers may interpret their assemblies, transforms, or reference objects incorrectly.

Use this order of preference:

1. Print the supplied STL when one exists.
2. When only a 3MF exists, open it in Microsoft 3D Builder and export the printable geometry to STL.
3. Read the part notes before assuming a related 3MF and STL contain the same geometry.

The actual models printed successfully through the Bambu workflow used for this project. Some files may be described by mesh-analysis tools as multi-shell or non-watertight. Do not automatically repair or simplify them without confirming that the result still matches the installed part.

## Repository layout

```text
stl/
├── README.md
├── file-manifest.tsv
├── battery-plunger/
│   └── anker-battery-button-plunger.3mf
├── bezel/
│   ├── lcd-bezel-braces-three-piece.3mf
│   ├── lcd-curved-bezel-final.stl
│   └── lcd-curved-bezel-generator.scad
├── boot-chime-switch/
│   ├── boot-chime-board-speaker-case.3mf
│   ├── boot-chime-board-speaker-case.stl
│   ├── boot-chime-selector-dial-reference-mockup.3mf
│   └── boot-chime-selector-dial.stl
├── monitor-stand/
│   ├── folding-monitor-stand.3mf
│   └── folding-monitor-stand.stl
├── power-rail/
│   ├── 5v-rail-enclosure.3mf
│   └── 5v-rail-enclosure.stl
├── power-switch/
│   ├── narrow-original-power-switch.3mf
│   └── narrow-original-power-switch.stl
├── screen-feet/
│   └── screen-retaining-feet-four-piece.stl
├── shelf/
│   ├── internal-three-level-rack.3mf
│   ├── internal-three-level-rack.stl
│   ├── rpi-elevator.3mf
│   ├── rpi-elevator.stl
│   ├── rpi-shelf-spacer.3mf
│   └── rpi-shelf-spacer.stl
├── status-led/
│   ├── apple-crt-status-led-cover.3mf
│   └── apple-crt-status-led-cover.stl
└── usb-panel-mount/
    ├── usb-panel-mount.3mf
    └── usb-panel-mount.stl
```

## Printed parts inventory

| Part | Repository location | Purpose | Installed? | Important notes |
|---|---|---|---|---|
| Three-level internal rack | `stl/shelf/internal-three-level-rack.*` | Holds the Raspberry Pi, 5V rail, LCD controller, internal power adapter, and USB speaker | yes | Current part was printed in brown PETG |
| Raspberry Pi elevator | `stl/shelf/rpi-elevator.*` | Raises the Pi above the upper shelf to provide airflow and reduce heat transfer | yes | Part of the current thermal mitigation; PETG recommended |
| Raspberry Pi shelf spacer | `stl/shelf/rpi-shelf-spacer.*` | Small optional spacer used with the zip-tied shelf arrangement to limit lift and movement | yes | Not essential to basic operation |
| Curved LCD bezel | `stl/bezel/lcd-curved-bezel-final.stl` | Mates the flat LCD to the original curved CRT opening | yes | Known-good final print |
| Bezel generator | `stl/bezel/lcd-curved-bezel-generator.scad` | Parametric OpenSCAD source for changing curvature, thickness, and opening | source | Historical variable names are mixed up; read comments before editing |
| LCD bezel braces | `stl/bezel/lcd-bezel-braces-three-piece.3mf` | Three braces span the back of the LCD and screw into the bezel | yes | 3MF only; export to STL in 3D Builder; use short, shallow screws |
| Screen-retaining feet | `stl/screen-feet/screen-retaining-feet-four-piece.stl` | Original case screws and metal frame press the feet against the bezel to retain it | yes | STL already contains all four feet; rejected experimental 3MF omitted |
| 5V rail enclosure | `stl/power-rail/5v-rail-enclosure.*` | Protects and mounts the handmade JST power rail | yes | Keeps the soldered underside isolated while leaving connectors accessible |
| Anker battery-button plunger | `stl/battery-plunger/anker-battery-button-plunger.3mf` | Spring/plunger mechanism presses the physical Anker button through an existing rear hole | yes | Final newer geometry is kept as one assembly; older mismatched STL omitted |
| Narrow original power-switch actuator | `stl/power-switch/narrow-original-power-switch.*` | Replaces the original actuator with a narrower version that does not bind | yes | Needed because the rebuilt internal assembly shifted the original alignment |
| Boot-chime board and speaker case | `stl/boot-chime-switch/boot-chime-board-speaker-case.*` | Holds the soundboard and salvaged laptop speaker as one module | yes | Mounted inside the metal case with double-sided adhesive |
| Boot-chime selector dial | `stl/boot-chime-switch/boot-chime-selector-dial.stl` | Interfaces with the multi-position selector used to choose startup sounds | yes | STL is the actual printable part |
| Selector reference mock-up | `stl/boot-chime-switch/boot-chime-selector-dial-reference-mockup.3mf` | Shows the selector part with surrounding reference geometry | reference | Not the preferred print file; print the STL instead |
| Green status-LED cover | `stl/status-led/apple-crt-status-led-cover.*` | Surrounds the replacement green LED behind the original acrylic indicator area | yes | Prevents light from bleeding through the interior |
| USB panel mount | `stl/usb-panel-mount/usb-panel-mount.*` | Minimal threaded mount for a solder-tab female USB receptacle | yes | Installed in an original control opening that was drilled slightly larger |
| Folding monitor stand | `stl/monitor-stand/folding-monitor-stand.*` | Angles the monitor upward and folds flat for transport | yes | Approximate working angle is 15–20 degrees |
| Apple-style wireless mouse | third-party links below | Matching wireless mouse using the Bambu electronics kit | yes | Third-party shell is linked, not redistributed here |

## Shelf arrangement

The rack is a three-level structure. It does not hold the Anker battery.

Approximate placement:

```text
Top shelf:
  Raspberry Pi 4B on the Pi elevator
  custom 5V JST rail

Middle shelf:
  internal USB power adapter
  LCD controller board

Bottom shelf:
  USB speaker

Rear metal floor:
  Anker battery, friction fit
```

The small Pi shelf spacer is optional. It was added to keep the Pi and zip-tied shelf arrangement from moving farther than intended.

## Display bezel, braces, and retaining feet

The display assembly uses the original case geometry, metal chassis, screws, and several printed parts together:

- curved bezel visually frames and aligns the LCD
- three braces span the rear of the LCD and fasten into the bezel
- four retaining feet press the bezel into position when the original metal frame is screwed down
- small hot-glue dabs may be used to prevent movement during assembly

The screen-feet STL already contains all four feet. Print the file once.

Use short, shallow screws for the three bezel braces so the screws do not penetrate farther than intended. The existing holes are best treated as pilot holes. If thicker screws are used, enlarge the holes carefully in the printed parts rather than forcing the screws and splitting the plastic.

## Bezel OpenSCAD source warning

The final STL is the known-good installed bezel. The OpenSCAD source is included so the curvature and thickness can be adapted, but its historical axis naming is confusing:

- `gap_long_*` controls curvature across the 147 mm X/width axis
- `gap_short_*` controls curvature across the 197 mm Y/height axis

The names therefore do not correspond cleanly to the physical long and short dimensions. Width and height assumptions elsewhere in the file may also feel reversed. Do not casually rename or swap the variables. Compare every changed render against the known-good final STL and expect some trial and error.

## Battery-button plunger

The Anker battery is buried tightly in the rear of the enclosure. This part uses a mechanical plunger and spring to provide access to the battery's physical button through one of the original control holes.

Only the newer 3MF assembly is included. The older STL did not match the final geometry and was intentionally excluded. Open the 3MF in Microsoft 3D Builder and export the printable assembly to STL before bringing it into a slicer.

## Boot-chime selector and soundboard case

The boot-chime system uses a multi-position selector and a small soundboard connected to a salvaged laptop speaker.

Two selector files are intentionally different:

- `boot-chime-selector-dial.stl` is the actual printable part
- `boot-chime-selector-dial-reference-mockup.3mf` contains surrounding mock-up geometry for design context

The reference 3MF should not be mistaken for the preferred print file.

## Thermal and electrical warning

The Raspberry Pi previously sat directly on the upper printed shelf. Heat softened and warped the shelf, which then pressed against and flexed the LCD controller board below it. That caused graphical glitches, color loss, instability, and apparent ribbon-cable problems.

Current mitigation includes:

- Pi elevator creating an air gap
- shelf supported with a zip tie
- reflective aluminum foil below and above the Pi
- display controller checked for mechanical pressure

Aluminum foil is conductive. It must remain electrically isolated from the Raspberry Pi, GPIO pins, USB shields, solder joints, LCD controller, power rail, and all exposed electronics. A properly secured nonconductive thermal barrier is preferable in a future revision.

Use PETG or another heat-tolerant material for the rack and Pi elevator when possible. A future rack revision should add a center support column or reinforcing rib.

## Mouse shell

The matching mouse is documented in [Hardware](hardware.md#mouse). The project does not redistribute the third-party shell files.

- [Retro Wireless Computer Mouse](https://www.printables.com/model/1339297-retro-wireless-computer-mouse)
- [Custom scroll wheel and axle](https://www.printables.com/model/1774131-scroll-wheel-and-axle-for-retro-wireless-computer)

The mouse uses the Bambu wireless mouse kit electronics and was printed in Retro Platinum PLA.

## General print settings

These are starting points, not strict requirements:

| Setting | Recommendation |
|---|---|
| Material | PETG for the rack and Pi elevator; PLA or PETG for most other hidden parts |
| Layer height | approximately 0.20 mm |
| Walls | 3 |
| Infill | approximately 15–25 percent |
| Supports | choose based on slicer preview and printer capability |
| Orientation | begin with the supplied model orientation |
| Quantity | one file unless noted; the feet STL already contains four feet |
| Color | darker colors for hidden internals; retro/off-white for visible parts |

Test-fit every mechanical part before final assembly. The models reflect one heavily modified Apple IIc Monitor shell and may need adjustment for another enclosure.

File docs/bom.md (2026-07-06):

# Bill of Materials

This BOM is based on the final installed build, purchase history, and project notes. Some parts are exact. Some are representative because they came from existing bins, local hardware stores, old project stock, or salvage.

The goal is not to pretend the project was clean. Hardware projects are not clean. This is the closest practical record of what is actually in the machine.

## Core donor and compute

| Item | Qty | Status | Purpose | Source / Notes |
|---|---:|---|---|---|
| Apple IIc Monitor A2M4090, Feb 1985 | 1 | final | donor shell | existing collection |
| Original Apple IIc Monitor AC inlet | 1 | final | charger input | reused from donor |
| Original Apple IIc Monitor power switch | 1 | final | interrupts battery output to 5V rail | reused from donor |
| Raspberry Pi 4 Model B, 4GB | 1 | final | compute board | already owned |
| 256GB microSD card | 1 | final | storage | already owned or existing stock |

## Display

| Item | Qty | Status | Purpose | Source / Notes |
|---|---:|---|---|---|
| 9-inch 800x480 HDMI/VGA/AV LCD monitor kit | 1 | final | screen and controller | May 16 AliExpress order |
| LCD controller board from final kit | 1 | final | HDMI/RCA display control | May 16 AliExpress order |
| 150mm FFC/LVDS ribbon cable | 1 | final | LCD to controller | currently installed |
| 50mm or 80mm FFC/LVDS ribbon cable | 1+ | future/backup | shorter cleaner LCD ribbon path | purchased as possible replacement |
| HDMI ribbon / angled adapter path | multiple | final | tight internal HDMI routing | AliExpress/Amazon experiments |
| Micro HDMI angled adapter | 1 | final | Raspberry Pi HDMI clearance | Amazon/AliExpress |
| RCA panel jack | 1 | final | composite video input | Amazon |
| RCA internal cable | 1 | final | rear RCA to LCD controller | Amazon/existing stock |

## Display experiments and engineering tax

| Item | Qty | Status | Purpose |
|---|---:|---|---|
| 9-inch 1024x600 LCD with board | 1 | experiment | early display approach |
| Additional 9-inch LCD panel | 1 | experiment | early panel attempt |
| PCB800099 LCD controller board | 1 | experiment/canceled | early controller attempt |
| PCB800099 / VS-TY2662 style controller | 1 | experiment | HDMI/VGA/AV LCD control |
| Multiple FPV HDMI ribbon cables | many | experiment/final mix | find the orientation that physically fit |
| VSDISPLAY 50-pin ZIF extension | 1 | experiment/backup | display ribbon extension |
| MECCANIXITY 50-pin 0.5mm FFC cables | 1 set | backup | possible shorter ribbon options |

Known AliExpress references:

- Final 9-inch display kit: https://www.aliexpress.com/item/3256805818626591.html
- FPV HDMI ribbon adapters: https://www.aliexpress.com/item/3256808758230576.html
- PCB800099 / VS-TY2662 controller experiment: https://www.aliexpress.com/item/2251832767582592.html
- PCB800099 controller order: https://www.aliexpress.com/item/3256807476829617.html
- 9-inch 1024x600 LCD experiment: https://www.aliexpress.com/item/3256808854350207.html

## Power

| Item | Qty | Status | Purpose | Source / Notes |
|---|---:|---|---|---|
| Anker Prime Power Bank 26K 300W | 1 | final | main battery / UPS / power management | eBay Jan 30 order |
| 100W USB-C power adapter | 1 | final | internal charger | eBay Jan 31 order |
| Original AC inlet wiring reuse | 1 | final | routes rear AC input to internal charger | donor part |
| Custom 5V JST rail | 1 | final | power distribution | handmade |
| Through-hole perfboard | 1 | final | power rail base | existing stock/local |
| Solid-core wire | several | final | soldered bus bars | existing stock |
| Small 2-pin JST connectors | about 6 | final | pluggable 5V outputs | Amazon/LCSC |
| 3D printed rail enclosure | 1 | final | protect rail underside and expose JST ports | printed |
| 18AWG DC barrel pigtails | set | final/stock | power wiring options | Amazon |
| USB-A to bare wire cable | set | final/stock | 5V power lead fabrication | Amazon |
| USB-C solder connector boards | set | stock/experiment | custom USB power/cable work | Amazon |
| Hook and loop cable wrap | 1 roll | final | cable management | Amazon |

Important: no fuses are currently installed in the custom rail. The build relies on the Anker and connected devices for protection.

## Audio

| Item | Qty | Status | Purpose | Source |
|---|---:|---|---|---|
| USB speaker | 1 | final | Raspberry Pi system audio | eBay Jan 30 order |
| YS-M3 MP3 module | 1 | final | boot chime playback | existing/purchased module |
| Mouser CK1028 selector switch | 1 | final | boot chime selector | https://www.mouser.com/ProductDetail/105-CK1028 |
| Salvaged laptop speaker | 1 | final | YS-M3 boot chime output | salvaged |
| 3D printed YS-M3/speaker mount | 1 | final | holds sound module and speaker | printed |
| USB-to-3.5mm/RCA audio adapter | 1 | external accessory | RCA audio when needed | Amazon |
| 3.5mm to RCA audio cable | 1 | external accessory | adapter to RCA | already owned |
| MAX98357A I2S amplifier boards | 2 | unused/experiment | possible audio amp path | Amazon |

## Controls and sensors

| Item | Qty | Status | Purpose | Source |
|---|---:|---|---|---|
| TTP223 capacitive touch sensor | 1 | final | Apple logo gesture input | Amazon |
| TTP223 spare modules | many | stock | experiments/spares | Amazon |
| EC11 rotary encoder | 1 | final | volume knob | Amazon |
| Physical source-select switch | 1 | final | LCD source button extension | existing stock/Amazon |
| Battery plunger button | 1 | final | external Anker button access | printed |
| LDR / LM393 light sensor modules | set | unused/experiment | possible ambient light behavior | Amazon |
| Relay modules | set | unused/abandoned | early touch/source switching idea | Amazon |
| MOSFET modules / transistors | set | unused/experiment | switching experiments | Amazon |

## Keyboard

| Item | Qty | Status | Purpose | Source |
|---|---:|---|---|---|
| Apple ADB Keyboard A9M0330 | 1 | final | main keyboard | existing collection |
| Seeed Studio XIAO nRF52840 | 1 | final | BLE keyboard controller | Seeed order #4000477519 |
| Custom keyboard PCB | 1 | final | ADB keyboard conversion | Fusion PCB order |
| nice!view display | 1 | final | keyboard status display | nice!view order |
| MCP23017-E/SS I/O expander | 2 purchased | final/stock | keyboard matrix I/O | LCSC |
| 110mAh LiPo battery | 1 | final | keyboard battery | Amazon |
| USB-C receptacle | multiple | final/stock | keyboard charging | LCSC |
| JST battery connector | multiple | final/stock | keyboard battery connector | LCSC |
| Slide switch | multiple | final/stock | keyboard power switch | LCSC |
| 10k resistors | 100 | stock | keyboard PCB passives | LCSC |
| 5.1k resistors | 100 | stock | USB-C CC resistors | LCSC |
| ZMK firmware | 1 | final | keyboard firmware | https://github.com/mattchesters/zmk-apple-desktop-bus-keyboard |

Keyboard attribution: the BLE ADB keyboard conversion is based on Matt Chesters' work and should be credited as such.

## Mouse

| Item | Qty | Status | Purpose | Source |
|---|---:|---|---|---|
| Bambu wireless mouse kit | 1 kit in use, 4 purchased | final/spares | matching wireless mouse electronics | Amazon |
| Apple-style 3D printed mouse shell | 1 | final | matching mouse enclosure | link to be added |
| Bambu Smooth PEI plate | 1 | used | better mouse shell printing | Bambu |
| Retro Platinum PLA | 1kg | used | retro-colored printed mouse | Polar Filament |
| USB mouse receiver | 1 | final | plugged into Raspberry Pi | from mouse kit |

## Bag and portability

| Item | Qty | Status | Purpose | Source |
|---|---:|---|---|---|
| LOVFEIFAN / LOVFEI FAN 55x30x20 cm bag | 1 | final | carrying case | Amazon |
| Corrugated plastic | several panels | final | bag liner | Menards/local hardware |
| Foam bottom | 1 | final | padding and alignment | Menards/local hardware |
| Green velvet fabric | 1 yard | final | interior finish | Amazon |
| Spray adhesive | 1 | final | velvet to liner/foam | local hardware |
| Qi wireless charging transmitter | 1 | final | hidden bag trickle charger | Amazon/existing |
| Hidden USB cable | 1 | final | powers wireless charging pad | existing/Amazon |
| Alignment grooves | 1 set | final | aligns monitor with charging pad | handmade/printed/foam work |
| Monitor stand | 1 | final | supports monitor when in use | 3D printed |

## Purchased but not final

| Item | Reason |
|---|---|
| Relay modules | source switching via touch was abandoned |
| Noisy Amazon power adapter | caused EMI problems |
| MAX98357A amps | USB speaker path won |
| Extra LCD panels/controllers | final May 16 display kit won |
| Many HDMI ribbons | only the fit-friendly path mattered |
| LDR modules | not part of final installed behavior |
| MOSFET switch boards | not part of final installed behavior |

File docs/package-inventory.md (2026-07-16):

# PiForma Package Inventory

## Purpose

This document explains the package snapshots under `packages/`. Those machine-readable files are the authoritative record of the live `macintosh-piforma` package state as audited on 2026-07-15.

## Audit scope and non-destructive decision

This began as a cleanup investigation, but the owner decided not to remove packages as part of this task. No APT or dpkg packages were installed, removed, purged, upgraded, marked, held, unheld, or reconfigured during this inventory work.

Experimental, compatibility, and development software is intentionally preserved. A package may belong to more than one conceptual role; the TSV assigns one primary role so future audits have readable diffs.

## System baseline

- Current OS: Debian GNU/Linux 13.5 / Raspberry Pi OS Trixie-style desktop stack.
- Hostname: `macintosh-piforma`.
- Native architecture: `arm64`.
- Foreign architecture: `armhf`.
- Active session: LightDM, Xorg, `rpd-x`, LXSession/LXDE, Openbox, PCManFM.
- Active PiForma processes: AtEase, PiForma Panel, Control Strip Simulator, Clippy, PipeWire, WirePlumber, Apple gesture button, volume knob, USB audio loop.
- Initial counts: 2911 dpkg status rows, 2908 fully installed `ii` rows, 1 held-installed `hi` row (`libsdl2-dev:arm64`), 2 config/status residue `rc` rows, 401 manual marks, 2508 automatic marks, held package `libsdl2-dev`.

The probable original image family is Raspberry Pi OS with desktop for Debian 13/Trixie. The exact image date or filename is not proven and must be named only after a rebuild test.

## APT repositories and architectures

Configured APT sources are Debian Trixie, Trixie updates, Trixie security, and Raspberry Pi Foundation Trixie. Components include `main`, `contrib`, `non-free`, and `non-free-firmware` for Debian, and `main` for Raspberry Pi.

See `packages/apt-sources.txt` for the sanitized source snapshot, architecture settings, policy output, and packages with no configured repository version. The scan found only the five local PiForma Debian packages as local-only; `libsdl2-dev` has a held local/status version but a lower Debian repository version exists.

## Installed package summary

There are two layers under `packages/`:

- Forensic state snapshots record what exists now, including dependency closure, local-only packages, experiments, foreign-architecture packages, historical kernels, and dpkg residue rows.
- Curated rebuild roots are deliberately selected top-level APT package names for future rebuild experiments. They are not generated from categories and intentionally omit dependency closure, local `.deb` packages, residue rows, and exact historical kernels.

Primary forensic classification totals:

- `base-os`: 41
- `compatibility`: 14
- `dependency`: 1593
- `development-toolchain`: 600
- `experiment`: 71
- `feature-runtime`: 16
- `foreign-architecture`: 262
- `kernel-history`: 20
- `local-deb`: 5
- `optional-utility`: 227
- `piforma-core-runtime`: 29
- `raspberry-pi-hardware`: 31
- `unknown`: 2

APT marks are not functional roles. Manual marks may be experiments or convenience utilities. Automatic marks may be required by active applications.

## How packages were classified

Classification used dpkg status, APT marks, APT history, dpkg history, live process evidence, systemd unit files, launcher `Exec=` lines, script imports and commands, local source checkouts, and installed dependency parents.

For automatic packages, `packages/apt-package-roles.tsv` records dependency status and, where practical, nearby installed parent/root packages. Many dependency families are intentionally documented as groups here rather than thousands of repeated paragraphs.

## Base operating system and Raspberry Pi support

The curated base profile selects Debian/Raspberry Pi OS roots, firmware and hardware support, networking, Bluetooth, supported Pi 4 arm64 kernel metapackages, and LightDM/X11 desktop foundations. Exact historical kernels and `rpd-wayland-*` are excluded from this X11 base profile and documented separately.

See `packages/apt-system-base.txt`.

## Desktop runtime

The active desktop runtime is X11. Live process evidence shows LightDM, Xorg, `lxsession -s rpd-x -e LXDE`, Openbox, PCManFM, `picom`, and `xcompmgr`.

Both compositors are installed and were observed running with parent PID 1 and the same start time. `picom` has explicit user LXDE-pi autostart evidence in `/home/frost/.config/lxsession/LXDE-pi/autostart`; `xcompmgr -aR` is referenced by `/etc/xdg/autostart/xcompmgr.desktop`. The core curated runtime includes `picom` only. `xcompmgr` is preserved in the experimental profile as a current-state compatibility/anomaly until a display test proves whether it is intentionally required.

## Core PiForma runtime

Confirmed core repository-backed runtime roots include:

`pipewire-audio`, `pipewire-bin`, `pipewire-pulse`, `wireplumber`, `pulseaudio-utils`, `python3`, `python3-gpiozero`, `python3-lgpio`, `wmctrl`, `xdotool`, `x11-utils`, `jq`, `libglib2.0-bin`, `lxterminal`, `zsh`, and `picom`.

The five local PiForma `.deb` packages (`about-this-pi-forma`, `at-ease`, `clippy`, `control-strip-simulator`, and `pi-forma-panel`) are core runtime applications but are deliberately excluded from repository-backed APT install commands.

`pulseaudio-utils` is core because it supplies `pactl`, used by the volume knob and USB audio loop scripts. `alsa-utils` is preserved as audio foundation/diagnostic support; no current script directly requires it as core runtime.

`libglib2.0-bin` is included because it supplies `gio`. No active launcher or service inspected in this audit directly invokes `gio`, and `dex` is not installed; AtEase may still use desktop-launching behavior internally, so `gio` is preserved as runtime support rather than treated as disposable. The AtEase and Control Strip repositories recommend `dex` as an optional fallback, so it should be tested during the fresh-media rebuild before deciding whether to add it to the runtime roots.

`python3-dbus-next`, `python3-libgpiod`, and `python3-rpi-lgpio` remain in the forensic installed-package inventory, but no direct active consumer was established during this audit. They are therefore not treated as minimal core installation roots.

See `packages/apt-piforma-runtime.txt`.

## Optional PiForma features

Optional/current features include Chromium kiosk launchers, QMMP/Winamp launcher, Flatpak/Kiwix Encarta launcher, VLC, Firefox, VNC packages, media tools, Flying Toasters, Weather Channel, RetroPie/EmulationStation, and SheepShaver.

Not all optional features are APT-owned. SheepShaver is an AppImage, RetroPie lives outside APT, and Kiwix is a Flatpak.

## Development and build toolchains

Development packages are intentionally preserved. Confirmed or likely groups include:

- Tauri/Rust/Node: `nodejs`, `npm`, Rust/Cargo from user-local tooling, WebKitGTK, GTK, Ayatana appindicator, GLib/GIO, OpenSSL, XDo, and related libraries for PiForma Panel, AtEase, Control Strip, and About This PiForma.
- Debian packaging: `devscripts`, `debhelper`, `dh-autoreconf`, `dpkg-dev`, `build-essential`.
- C/C++ and media: GCC/G++, CMake, FFmpeg development libraries, PipeWire/ALSA/PulseAudio development libraries, USB/udev/DRM/GBM/X11 headers.
- Qt/media experiments: Qt 6 development packages and Qt Creator.
- Emulator/media source builds: SDL, FreeImage, FreeType, Boost filesystem, SpeexDSP, VLC development libraries, CDIO/ISO9660.

APT history shows explicit February 2026 source-build dependency batches for these groups.

## Experiments and possible future features

Preserved experiments include DOSBox-X, Qtractor, Tux Paint, XFCE, appmenu plugins, Weston/Wayland, Xephyr, `rpd-wayland`, `labwc`, `wayvnc`, Qt tools, and alternate desktop/media paths.

The first previously proposed removal batch, `dosbox-x`, `qtractor`, `tuxpaint`, and `tuxpaint-config`, is now classified as preserved experiments.

## Compatibility and foreign architecture

Compatibility packages include `armhf` libraries, Wine-related packages, Xwayland, Wayland libraries, and fallback display/session support. The foreign architecture remains configured and unchanged.

## Local Debian packages

Five locally built Debian packages are installed and not available from configured repositories:

- `about-this-pi-forma`
- `at-ease`
- `clippy`
- `control-strip-simulator`
- `pi-forma-panel`

Source paths, current checkout commits, dirty state, found `.deb` paths, found `.deb` metadata, SHA-256 hashes, file-comparison notes, and build-command confidence are recorded in `packages/local-deb-packages.tsv`. Current checkout commit does not prove the found `.deb` was built from that commit; `verified_build_source_commit` remains blank unless a build record proves it.

The discovered About This PiForma `.deb` did not fully match the live installed files. One compared file differed and another expected file was missing. Treat that package as an unverified recovery artifact until it is rebuilt or independently validated.

## Non-APT software

Non-APT inventory includes Flatpak apps (`org.kiwix.desktop`, `org.kde.marble`, `org.qgis.qgis`), SheepShaver AppImage, Tauri AppImage helpers, Pi-Apps, RetroPie, `/opt/retropie`, local emulation files, user-local Codex/Claude binaries, the rustup Rust toolchain, and Python virtual environments. `packages/python-environments.tsv` separates Debian-managed Python distributions from virtualenvs and is not a pip restore manifest.

An APT-only package list cannot recreate the complete PiForma software stack.

## Held packages

`libsdl2-dev` is held. Installed version: `2.32.10+1rpi` for `arm64`; candidate version is also `2.32.10+1rpi` from the local dpkg status, while Debian Trixie offers `2.32.4+dfsg-1`. APT/dpkg history shows it was installed on 2026-02-21 during emulator/media development dependency work. No log line proving when the hold was set was found. The exact reason for the hold was not conclusively identified, so it remains unresolved for owner review. The hold was not changed.

## Unknown or unresolved package purposes

`packages/apt-unknown.txt` currently contains no curated install roots. The dpkg config/status residue rows `rpi-connect-lite` and `tint2` are recorded in `packages/dpkg-residue.txt` and remain visible in the forensic snapshots for transparency.

## Rebuild profiles

- Core PiForma: `apt-system-base.txt`, `apt-piforma-runtime.txt`, local PiForma `.deb` packages, scripts, configs, systemd units, and required visual assets.
- Current-feature PiForma: core plus `apt-optional-features.txt`, Flatpak applications, SheepShaver, RetroPie/EmulationStation, Weather Channel assets, Flying Toasters build, and retained remote access.
- PiForma development workstation: current-feature plus `apt-development.txt`, Rust toolchain, Node/npm build environment, and project source repositories.
- Experimental full clone: development workstation plus `apt-experiments.txt`, `apt-compatibility.txt`, foreign architecture configuration, and forensic historical package-state references. Historical exact kernel packages are documented but not automatically installed without an explicit historical-clone decision.

Curated root counts are: system base 36, PiForma runtime 15, optional features 31, development 85, experiments 25, compatibility 9, unknown 0. `apt-kernel-history.txt` records 20 historical kernel status entries.

## Known limitations

Exact package versions may not remain available in repositories forever. Local `.deb` files are present on this machine but are not committed here. Private or copyrighted assets, ROMs, disk images, Kiwix content, and some visual assets need separate archival decisions.

## Related files

- `packages/README.md`
- `packages/apt-installed.tsv`
- `packages/apt-package-roles.tsv`
- `packages/local-deb-packages.tsv`
- `packages/non-apt-software.tsv`
- `packages/python-environments.tsv`
- `packages/development-toolchains.md`
- `packages/validate-package-profiles.py`
- `docs/software-installation.md`
- `docs/package-cleanup-proposal.md`

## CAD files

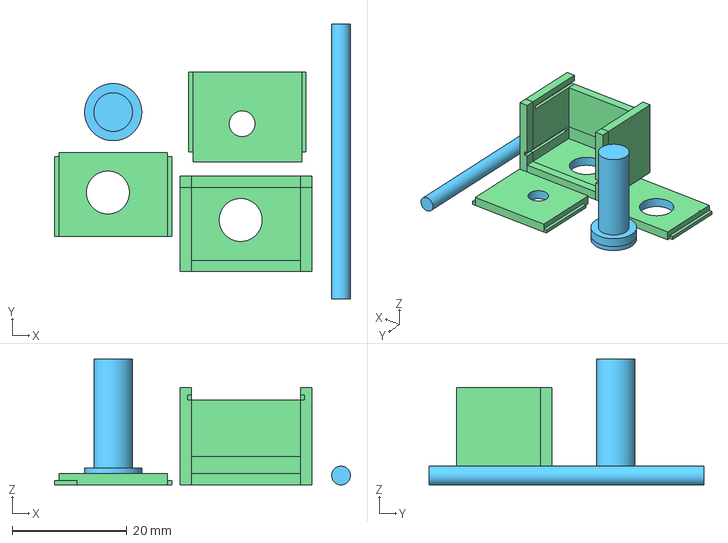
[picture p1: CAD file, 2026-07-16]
stl/battery-plunger/anker-battery-button-plunger.3mf
51.7 x 48.0 x 22.0 mm

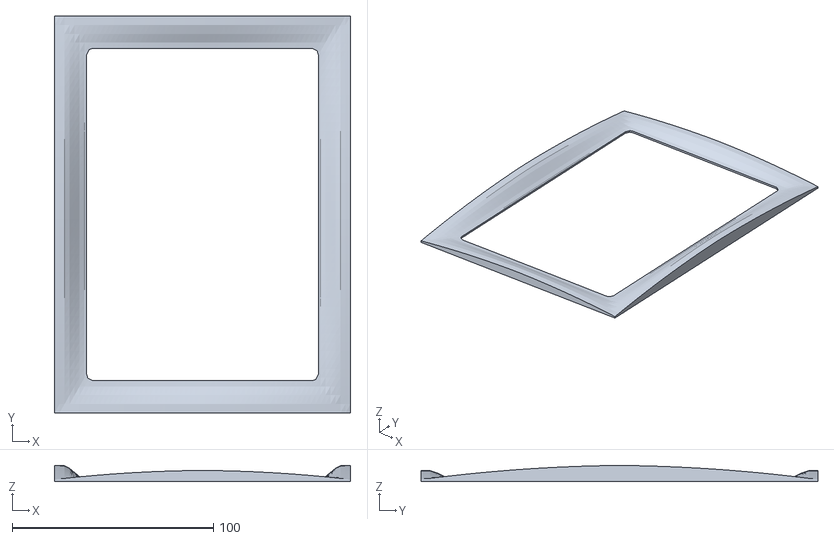
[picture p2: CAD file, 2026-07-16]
stl/bezel/lcd-curved-bezel-final.stl
147.0 x 197.0 x 7.97

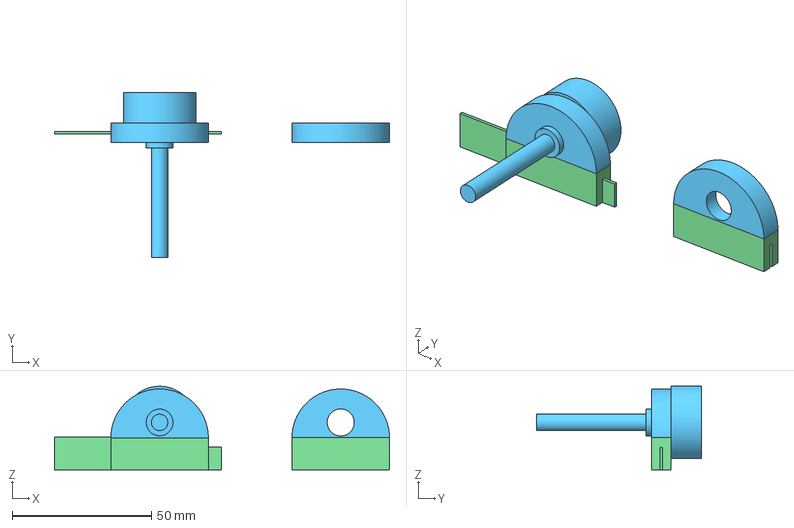
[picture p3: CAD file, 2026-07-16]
stl/boot-chime-switch/boot-chime-selector-dial-reference-mockup.3mf
120.2 x 59.3 x 30.0 mm

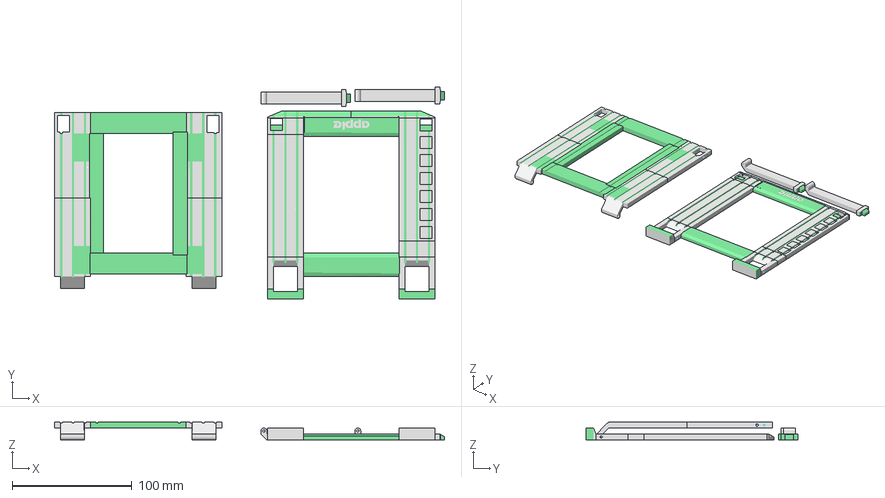
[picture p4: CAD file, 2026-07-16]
stl/monitor-stand/folding-monitor-stand.3mf
326.2 x 176.9 x 15.0 mm

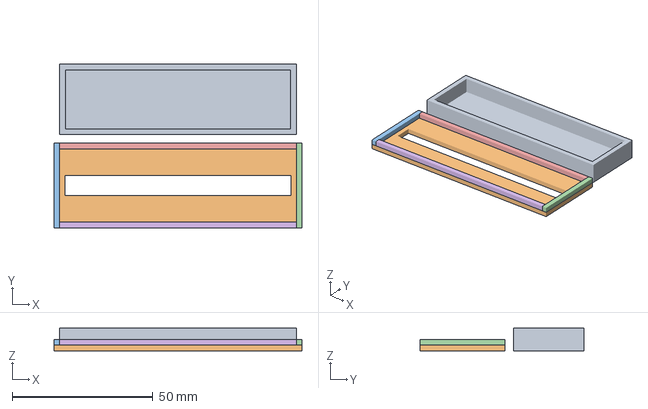
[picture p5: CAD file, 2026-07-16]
stl/power-rail/5v-rail-enclosure.3mf
88.0 x 58.0 x 8.00 mm

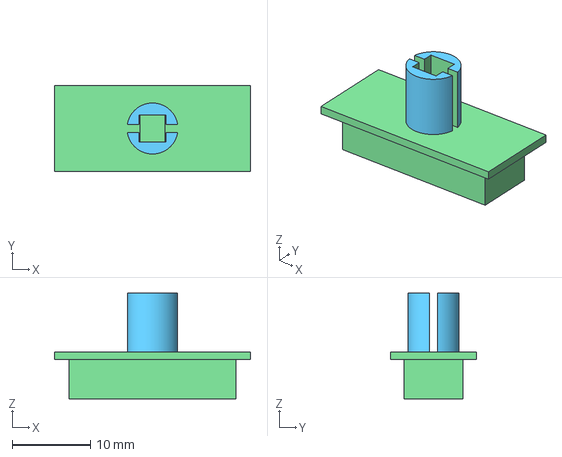
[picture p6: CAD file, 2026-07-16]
stl/power-switch/narrow-original-power-switch.3mf
25.0 x 11.0 x 13.5 mm

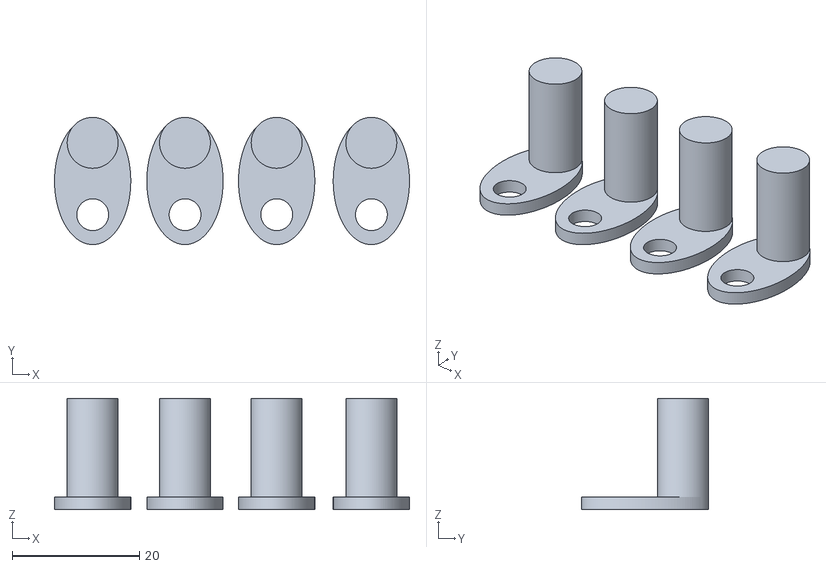
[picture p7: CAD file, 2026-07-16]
stl/screen-feet/screen-retaining-feet-four-piece.stl
55.8 x 20.0 x 17.5

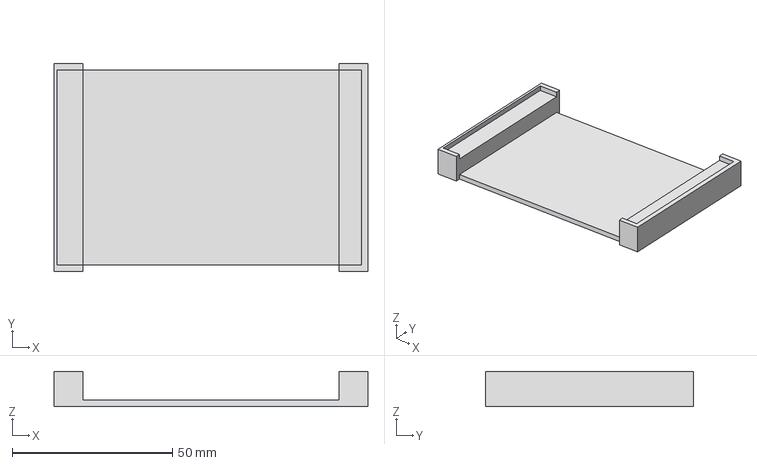
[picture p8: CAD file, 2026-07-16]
stl/shelf/rpi-elevator.3mf
98.0 x 65.0 x 11.0 mm

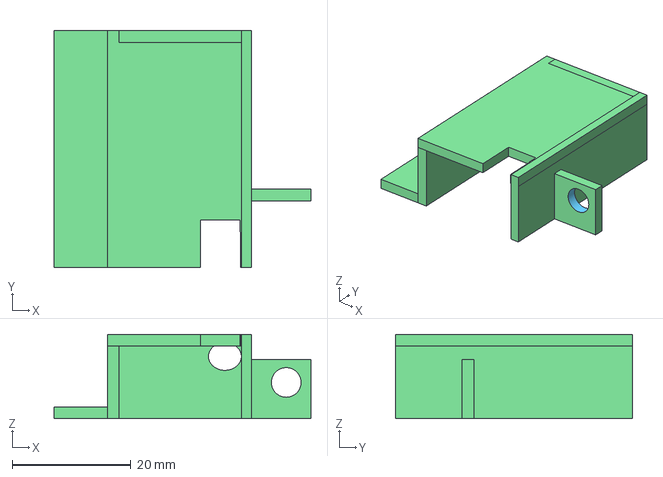
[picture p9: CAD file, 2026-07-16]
stl/status-led/apple-crt-status-led-cover.3mf
43.3 x 40.0 x 14.3 mm

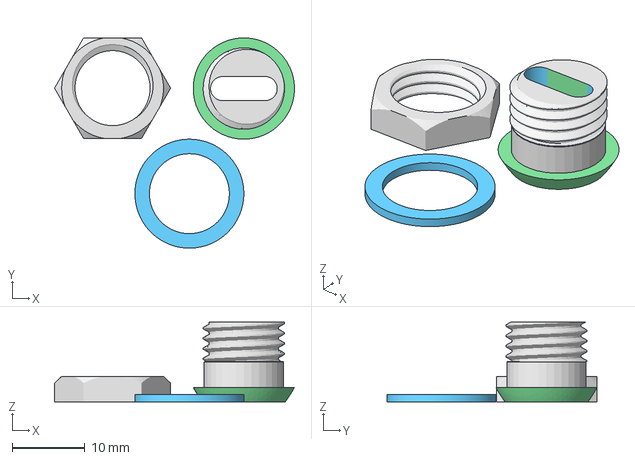
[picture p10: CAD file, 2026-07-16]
stl/usb-panel-mount/usb-panel-mount.3mf
33.0 x 29.0 x 11.0 mm

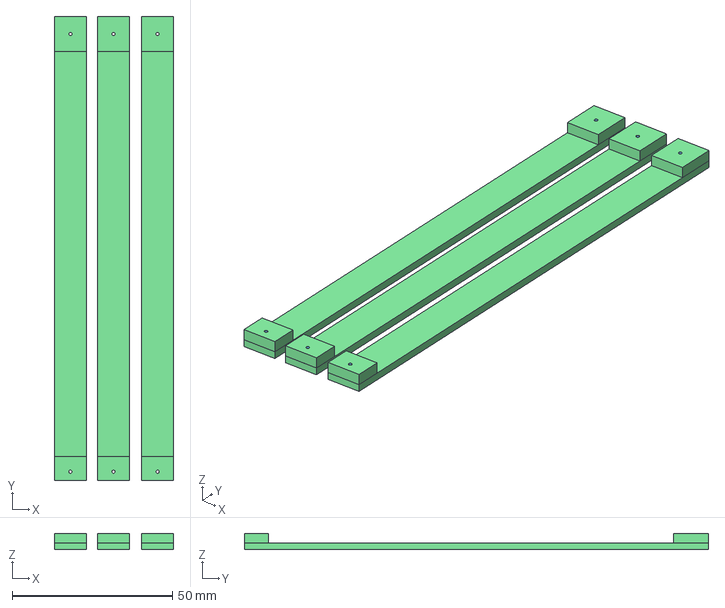
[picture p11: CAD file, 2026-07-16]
stl/bezel/lcd-bezel-braces-three-piece.3mf
37.2 x 145.0 x 5.00 mm

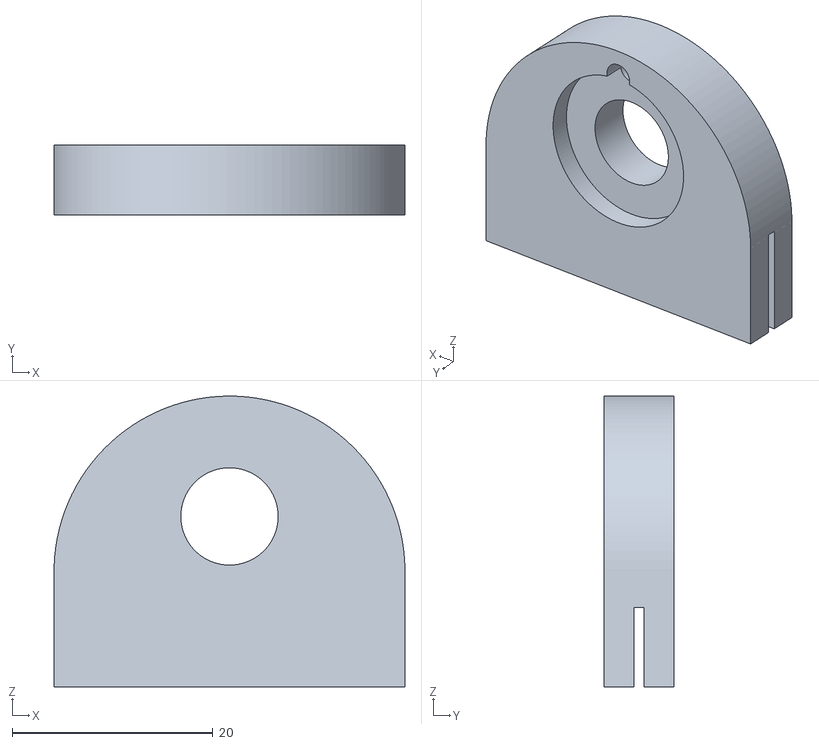
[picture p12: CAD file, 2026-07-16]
stl/boot-chime-switch/boot-chime-selector-dial.stl
35.0 x 7.00 x 29.0

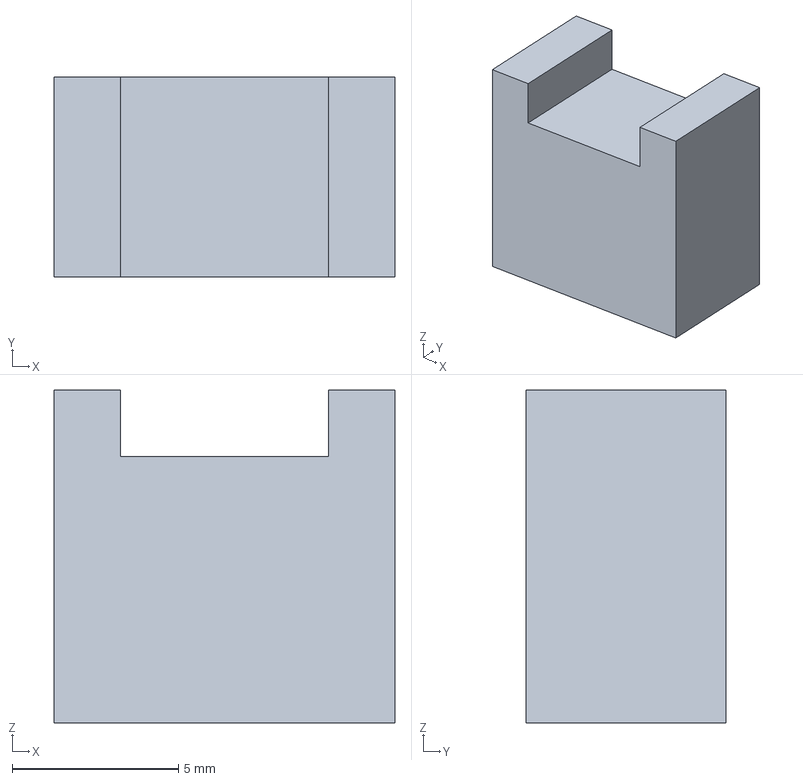
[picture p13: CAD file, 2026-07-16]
stl/shelf/rpi-shelf-spacer.3mf
10.2 x 6.00 x 10.00 mm

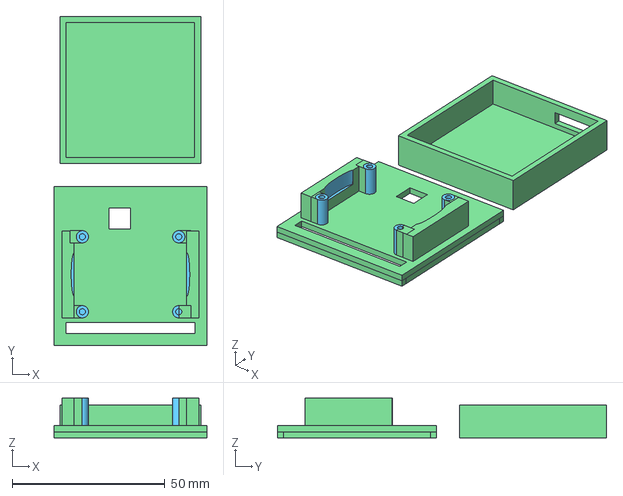
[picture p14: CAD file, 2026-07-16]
stl/boot-chime-switch/boot-chime-board-speaker-case.3mf
50.0 x 107.5 x 13.0 mm

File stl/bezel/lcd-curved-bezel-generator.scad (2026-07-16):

////////////////////////////////////////////////////////////
// CRT BEZEL GAP FILLER
// Inner region flat at t_flat, outer region follows curve
// Transition based on distance from INNER cutout edge
////////////////////////////////////////////////////////////

// ---------- BEZEL INNER OPENING (mm) ----------
bezel_inner_w = 147;
bezel_inner_h = 197;

// IMPORTANT HISTORICAL PARAMETER WARNING:
// This file generates the installed bezel, but some axis names are reversed.
// The gap_long_* values are evaluated with tx(x), so they control curvature
// across the 147 mm X/width axis. The gap_short_* values are evaluated with
// ty(y), so they control curvature across the 197 mm Y/height axis.
// In other words, "long" and "short" do not match the physical long and short
// dimensions. Width/height terminology elsewhere may also feel counterintuitive.
// Do not rename, swap, or "correct" these variables without comparing the
// rendered result to the known-good final STL. Expect trial and error when
// adapting this generator to another display or enclosure.

// ---------- GAP MEASUREMENTS (lip -> LCD plane) ----------
gap_short_center  = 7.0;
gap_short_quarter = 5.0;
gap_short_corner  = 0.0;

gap_long_center  = 4.25;
gap_long_quarter = 3.25;
gap_long_corner  = 0.0;   // set 0.0 if corners touch

// ---------- STRUCTURE ----------
min_thickness = 0.8;       // do not go below this anywhere

outer_hold = 4.0;   // mm of guaranteed full-curve at the outer edge

// ---------- INNER FLAT TARGET ----------
t_flat = 1.0;              // your request: inner part equals 1 mm everywhere

// Blend control (distance measured from INNER cutout edge, outward)
// For the first flat_inner_band mm from the cutout edge, stay flat.
// Then blend up to the curved thickness over blend_band mm.
flat_inner_band = 0;

blend_band = 12;

// ---------- VIEW CUTOUT / PER-SIDE BORDERS (mm) ----------
border_left   = 16;
border_right  = 16;
border_top    = 16;
border_bottom = 16;

// Optional cutout offset if LCD is not centered
cutout_offset_x = 0;
cutout_offset_y = 0;

// Rounded inside corners of view hole
view_corner_r = 3;         // 0 = square

// ---------- RESOLUTION ----------
nx = 60;
ny = 46;


// ========================================================
// MATH
// ========================================================

function quad_coeff(c,q,k) = [
    2*(k + c - 2*q),
    (4*q - 3*c - k),
    c
];

// distance from point to nearest OUTER edge of bezel rectangle
function dist_to_outer_edge(x,y) =
    min( (bezel_inner_w/2 - abs(x)), (bezel_inner_h/2 - abs(y)) );


function quad_eval(C,t) = C[0]*t*t + C[1]*t + C[2];

function clamp01(x) = x < 0 ? 0 : (x > 1 ? 1 : x);

function smoothstep(e0, e1, x) =
    let(t = clamp01((x - e0)/(e1 - e0)))
    t*t*(3 - 2*t);

// Axis curves
longC  = quad_coeff(gap_long_center,  gap_long_quarter,  gap_long_corner);
shortC = quad_coeff(gap_short_center, gap_short_quarter, gap_short_corner);

function tx(x) = clamp01(abs(x)/(bezel_inner_w/2));
function ty(y) = clamp01(abs(y)/(bezel_inner_h/2));

function gap_xy(x,y) =
    max( quad_eval(longC,tx(x)), quad_eval(shortC,ty(y)) );

// ========================================================
// INNER CUTOUT SIZE
// ========================================================

vw = bezel_inner_w - (border_left + border_right);
vh = bezel_inner_h - (border_top + border_bottom);

vw_safe = vw < 1 ? 1 : vw;
vh_safe = vh < 1 ? 1 : vh;

// Distance from a point to the INNER cutout rectangle edge (outside the cutout).
// Uses Chebyshev style distance for blending: max(dx,dy).
function dist_to_inner_edge(x,y) =
    let(
        xi = x - cutout_offset_x,
        yi = y - cutout_offset_y,
        dx = abs(xi) - (vw_safe/2),
        dy = abs(yi) - (vh_safe/2)
    )
    max(0, max(dx, dy));

// Thickness field:
// flat near inner edge, rises toward outer edge.
// Curved target is t_flat + gap_xy.
function thickness_xy(x,y) =
    let(
        tf = max(min_thickness, t_flat),
        tc = max(min_thickness, t_flat + gap_xy(x,y)),

        d_in  = dist_to_inner_edge(x,y),
        d_out = dist_to_outer_edge(x,y),

        // 0 => flat, 1 => curved, based on distance from inner cutout edge outward
        a = smoothstep(flat_inner_band, flat_inner_band + blend_band, d_in)
    )
    // Outer band override: always curved for outer_hold mm
    (d_out <= outer_hold) ? tc : ((1 - a)*tf + a*tc);


// ========================================================
// HEIGHTFIELD SOLID
// ========================================================

module heightfield_block(w,h,nx,ny)
{
    x0 = -w/2; x1 = w/2;
    y0 = -h/2; y1 = h/2;
    dx = (x1-x0)/(nx-1);
    dy = (y1-y0)/(ny-1);

    function idx(i,j) = j*nx + i;
    top_offset = nx*ny;

    points =
        concat(
            // bottom grid
            [ for(j=[0:ny-1], i=[0:nx-1])
                [ x0 + i*dx, y0 + j*dy, 0 ] ],

            // top grid
            [ for(j=[0:ny-1], i=[0:nx-1])
                let(
                    x = x0 + i*dx,
                    y = y0 + j*dy,
                    t = thickness_xy(x,y)
                )
                [ x, y, t ]
            ]
        );

    bottom_faces =
        [ for(j=[0:ny-2], i=[0:nx-2])
            each [
                [ idx(i,j), idx(i+1,j), idx(i+1,j+1) ],
                [ idx(i,j), idx(i+1,j+1), idx(i,j+1) ]
            ]
        ];

    top_faces =
        [ for(j=[0:ny-2], i=[0:nx-2])
            let(
                a=idx(i,j)+top_offset,
                b=idx(i+1,j)+top_offset,
                c=idx(i+1,j+1)+top_offset,
                d=idx(i,j+1)+top_offset
            )
            each [
                [ a,c,b ],
                [ a,d,c ]
            ]
        ];

    side_faces =
        concat(
            [ for(i=[0:nx-2])
                let(b0=idx(i,0), b1=idx(i+1,0), t0=b0+top_offset, t1=b1+top_offset)
                each [[ b0,t1,b1 ], [ b0,t0,t1 ]]
            ],
            [ for(i=[0:nx-2])
                let(b0=idx(i,ny-1), b1=idx(i+1,ny-1), t0=b0+top_offset, t1=b1+top_offset)
                each [[ b0,b1,t1 ], [ b0,t1,t0 ]]
            ],
            [ for(j=[0:ny-2])
                let(b0=idx(0,j), b1=idx(0,j+1), t0=b0+top_offset, t1=b1+top_offset)
                each [[ b0,b1,t1 ], [ b0,t1,t0 ]]
            ],
            [ for(j=[0:ny-2])
                let(b0=idx(nx-1,j), b1=idx(nx-1,j+1), t0=b0+top_offset, t1=b1+top_offset)
                each [[ b0,t1,b1 ], [ b0,t0,t1 ]]
            ]
        );

    polyhedron(points=points, faces=concat(bottom_faces,top_faces,side_faces));
}


// ========================================================
// CUTOUT
// ========================================================

module rounded_rect_cutout(w,h,r,cut_h=300)
{
    if(r<=0)
        cube([w,h,cut_h],center=true);
    else
        linear_extrude(height=cut_h,center=true)
            offset(r=r)
                square([w-2*r,h-2*r],center=true);
}


// ========================================================
// FINAL MODEL
// ========================================================

difference()
{
    heightfield_block(bezel_inner_w,bezel_inner_h,nx,ny);

    translate([cutout_offset_x, cutout_offset_y, -1])
        rounded_rect_cutout(vw_safe, vh_safe, view_corner_r, 400);
}

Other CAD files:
stl/shelf/internal-three-level-rack.3mf
stl/boot-chime-switch/boot-chime-board-speaker-case.stl
stl/power-rail/5v-rail-enclosure.stl
stl/power-switch/narrow-original-power-switch.stl
stl/shelf/internal-three-level-rack.stl
stl/shelf/rpi-elevator.stl
stl/shelf/rpi-shelf-spacer.stl
stl/status-led/apple-crt-status-led-cover.stl
stl/usb-panel-mount/usb-panel-mount.stl

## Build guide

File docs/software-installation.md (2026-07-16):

# Macintosh PiForma Software Installation

## Scope

This is the beginning of the fresh-install software saga. It documents the current known-good machine and a safe conceptual rebuild order. It is not yet a fully tested installer or a guarantee that the PiForma is reproducible from blank media.

## Current known-good system baseline

Confirmed current OS: Debian GNU/Linux 13.5 / Raspberry Pi OS Trixie-style desktop stack on `arm64`, with `armhf` enabled.

Probable original image family: Raspberry Pi OS with desktop for Debian 13/Trixie.

Unknown: exact Raspberry Pi OS image filename, image date, and whether every non-APT asset is archived.

## Rebuild profiles

Core PiForma contains the Raspberry Pi OS and X11 desktop foundation, LightDM, Openbox, PCManFM, PipeWire/WirePlumber, GPIO script dependencies, PiForma Panel, AtEase, Control Strip, Clippy, core scripts, configs, and services.

Current-feature PiForma adds actively configured features such as Chromium kiosk launchers, Weather Channel, Flying Toasters, QMMP, Flatpak/Kiwix, SheepShaver, RetroPie/EmulationStation, and retained remote access.

PiForma development workstation adds Rust/Cargo, Node.js/npm, Tauri build dependencies, Debian packaging tools, C/C++/CMake/Qt/media/emulator/hardware development headers.

Experimental full clone recreates the current package state most closely, including XFCE, Wayland/Weston, Xephyr, DOSBox-X, Tux Paint, Qtractor, Wine/armhf compatibility, alternate media tools, and historical build dependencies.

## Stage 1: Raspberry Pi OS base

Install the confirmed Raspberry Pi OS base on separate media. Create user `frost`, set hostname `macintosh-piforma`, and confirm UID, home path, graphical-session, and display assumptions before restoring PiForma services.

The future tested guide must name the exact starting image after a real rebuild test.

## Stage 2: APT sources and architecture

Restore Debian/Raspberry Pi Trixie APT sources as documented in `packages/apt-sources.txt`. Confirm native architecture `arm64` and foreign architecture `armhf`.

Do not add repositories or enable foreign architectures blindly on a live system without an explicit rebuild plan.

## Stage 3: System and desktop packages

Use `packages/apt-system-base.txt` as the base package reference. It contains curated top-level roots, not every dependency and not historical kernel versions.

Future rebuild simulation command, not run as an install during this audit:

```bash

grep -Ev '^[[:space:]]*(#|$)' packages/apt-system-base.txt \
  | xargs -r apt-get -s install
```

Future rebuild install command, to run only on rebuild media after simulation review:

```bash

grep -Ev '^[[:space:]]*(#|$)' packages/apt-system-base.txt \
  | xargs -r sudo apt install -y
```

## Stage 4: PiForma runtime packages

Use `packages/apt-piforma-runtime.txt` for directly evidenced repository-backed runtime roots. The local PiForma `.deb` package names are intentionally not in this APT profile.

```bash

grep -Ev '^[[:space:]]*(#|$)' packages/apt-piforma-runtime.txt \
  | xargs -r apt-get -s install
```

```bash

grep -Ev '^[[:space:]]*(#|$)' packages/apt-piforma-runtime.txt \
  | xargs -r sudo apt install -y
```

Then restore scripts, configs, local apps, and services before expecting the desktop to behave like PiForma.

The AtEase and Control Strip repositories recommend `dex` as an optional fallback for launching `.desktop` files when `gio launch` is unavailable or fails. `dex` was not installed on the audited live Pi, so it is not included in the current-state runtime profile. Test it during the fresh-media rebuild and add it to the runtime roots only if the fallback is needed.

## Stage 5: Local PiForma Debian packages

The local packages cannot be restored through normal configured APT repositories unless a package repository is created later.

Rebuild or reinstall:

- `about-this-pi-forma`
- `at-ease`
- `clippy`
- `control-strip-simulator`
- `pi-forma-panel`

Use `packages/local-deb-packages.tsv` for source paths, current checkout commits, found `.deb` files, found `.deb` metadata, hashes, build-command confidence, and file-comparison notes. Do not assume a found `.deb` was built from the current checkout unless `verified_build_source_commit` is populated. Do not assume the `.deb` files are safely archived just because they exist on the live machine.

> **Recovery warning:** The discovered About This PiForma `.deb` did not fully match the live installed files. One compared file differed and another expected file was missing. Do not use that package as a trusted recovery artifact until it has been rebuilt or independently verified.

## Stage 6: Optional applications and features

Install optional APT feature roots from `packages/apt-optional-features.txt` only for the current-feature or larger profiles.

```bash

grep -Ev '^[[:space:]]*(#|$)' packages/apt-optional-features.txt \
  | xargs -r apt-get -s install
```

```bash

grep -Ev '^[[:space:]]*(#|$)' packages/apt-optional-features.txt \
  | xargs -r sudo apt install -y
```

Restore Flatpak apps and AppImages from `packages/non-apt-software.tsv`.

## Stage 7: Development environment

Install development roots from `packages/apt-development.txt` for the development workstation profile.

```bash

grep -Ev '^[[:space:]]*(#|$)' packages/apt-development.txt \
  | xargs -r apt-get -s install
```

```bash

grep -Ev '^[[:space:]]*(#|$)' packages/apt-development.txt \
  | xargs -r sudo apt install -y
```

This intentionally includes broad C/C++, Tauri-adjacent, Qt, media, emulator, and Debian packaging support. Rust itself is managed through `rustup` and documented in `packages/development-toolchains.md`.

## Stage 8: Experimental and compatibility packages

Install experiments and compatibility roots only for the experimental full clone.

```bash

grep -Ev '^[[:space:]]*(#|$)' packages/apt-experiments.txt \
  | xargs -r apt-get -s install

grep -Ev '^[[:space:]]*(#|$)' packages/apt-compatibility.txt \
  | xargs -r apt-get -s install
```

```bash

grep -Ev '^[[:space:]]*(#|$)' packages/apt-experiments.txt \
  | xargs -r sudo apt install -y

grep -Ev '^[[:space:]]*(#|$)' packages/apt-compatibility.txt \
  | xargs -r sudo apt install -y
```

This is the closest APT root profile to the current machine, but it still does not automatically install exact historical kernel packages or guarantee exact old package versions.

## Stage 9: Non-APT software

Restore Flatpak apps, SheepShaver AppImage, RetroPie/EmulationStation, Pi-Apps if intentionally retained, user-local binaries, Rust toolchain state, Python virtual environments, and any emulator trees not owned by APT. `packages/python-environments.tsv` is an ownership inventory, not a blanket pip requirements file.

## Stage 10: Restore scripts, configurations, and services

Safe conceptual order:

1. install confirmed Raspberry Pi OS base
2. create user `frost`
3. configure hostname `macintosh-piforma`
4. confirm UID and graphical-session assumptions
5. configure APT sources and foreign architecture
6. install base and desktop packages
7. install PiForma runtime dependencies
8. install or rebuild local PiForma Debian packages
9. install optional applications
10. install development and experimental packages for those profiles
11. restore scripts
12. restore configuration files
13. restore system and user services
14. restore `.desktop` launchers
15. restore themes, icons, fonts, wallpaper, and other assets
16. restore non-APT applications
17. enable intended services
18. reboot
19. validate every feature

## Stage 11: Restore visual assets

Rebuild gaps needing owner archival decisions:

- exact Raspberry Pi OS image: unknown
- local PiForma `.deb` files: documented but not archived in Git
- PiForma source commits: documented
- GTK theme and icon themes: partially archived/configured, verify assets
- Chicago and Charcoal fonts: documented but not fully archived here
- Apple logo image, wallpaper, launcher icons, favicons: partially documented, verify archive completeness
- Weather Channel `launch.html` and `satellite.png`: documented but verify archive state
- Flying Toasters build directory: documented but not fully reproducible here
- Clippy assets: rebuildable from local source/deb, verify upstream/private assets
- Plymouth theme and boot files: partially archived, verify binary assets
- RetroPie, EmulationStation config, controller mappings: documented but not fully archived here
- SheepShaver AppImage: present locally
- SheepShaver ROM and Mac OS disk image: private or copyrighted asset
- Flatpak applications and Kiwix content: documented but content not fully archived
- sudoers rule for Apple-logo shutdown: verify and archive
- `env-display.desktop`: documented in systemd notes, verify archive
- Python packages not supplied by APT: dedicated inventory created in `packages/python-environments.tsv`; currently observed system Python distributions are Debian-managed, with three virtual environments requiring separate review

## Stage 12: Verification

After a rebuild, validate boot, display mode, LightDM autologin, Openbox, PCManFM desktop, PiForma Panel, AtEase, Control Strip, Clippy, Apple-logo tap/hold gestures, volume knob, audio output, USB audio loop, Weather Channel, Flying Toasters, Chromium launchers, QMMP, SheepShaver, RetroPie, Flatpak/Kiwix, VNC if retained, and service health.

## Remaining reproducibility gaps

The system is not ready to claim full reproducibility. Curated profiles have been validated as repository-backed roots, but they still require a fresh-media test. A tested fresh-install procedure requires separate media, an exact base image, confirmed asset archival, local `.deb` archival or rebuild automation, non-APT restore steps, and full feature validation.

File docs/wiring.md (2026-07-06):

# Wiring

This file documents Macintosh PiForma wiring at a system level. It is not a pin-perfect schematic yet. It is a map for Future Matthew so the machine does not become a mystery box.

## Power diagram

```mermaid
flowchart LR
    AC[Original Apple IIc Monitor AC inlet] --> Charger[Internal 100W USB power adapter]
    Charger -->|USB power| Battery[Anker Prime 26K 300W]

    Battery -->|Output port| AppleSwitch[Original Apple monitor power switch]
    AppleSwitch -->|Switched 5V| Rail[Custom 5V JST rail]

    Rail --> Pi[Raspberry Pi 4B]
    Rail --> LCD[LCD driver board]
    Rail --> Chime[YS-M3 boot chime module]
    Rail --> Touch[TTP223 Apple logo touch sensor]

    Pi --> USBSpeaker[Internal USB speaker]
    Pi --> RearUSB[Rear USB host port]
    Pi --> MouseDongle[Bambu mouse USB receiver]
```

## Charging behavior

The original Apple monitor power switch interrupts battery output to the 5V rail.

It does not interrupt charger input.

Monitor off:

```text
AC inlet -> charger -> Anker battery
Anker output -> interrupted by original Apple switch
5V rail -> off
Pi/display/audio -> off
```

Monitor on:

```text
AC inlet -> charger -> Anker battery
Anker output -> original Apple switch -> 5V rail
Pi/display/chime/touch/display -> on
```

## Anker port usage

| Anker port | Use |
|---|---|
| Port 1 | Input from internal 100W USB power adapter |
| Port 2 | Powers wireless charging transmitter in the bag |
| Port 3 | Output to original power switch, then custom 5V rail |

Exact physical port numbering may vary. The function matters more than the label.

## Custom 5V JST rail

Construction:

```text
through-hole perfboard
  + small 2-pin JST connectors in a row
  + stripped solid-core wire as positive bus
  + stripped solid-core wire as ground bus
  + soldered underside
  + 3D printed enclosure
```

Approximate outputs:

```text
6 JST outputs
```

Current loads:

| Load | Powered by rail? | Notes |
|---|---:|---|
| Raspberry Pi 4B | yes | main compute board |
| LCD controller | yes | final display controller |
| YS-M3 boot chime module | yes | plays startup sounds |
| TTP223 Apple logo touch sensor | yes | GPIO 23 signal to Pi |
| USB speaker | no | powered by Raspberry Pi USB |
| Relays | no | relay idea abandoned in final build |

## GPIO mapping

| Function | GPIO | Notes |
|---|---:|---|
| Apple logo touch sensor | GPIO 23 | active-low, multi-tap and hold gestures |
| Volume encoder A | GPIO 17 | EC11 rotary encoder |
| Volume encoder B | GPIO 27 | EC11 rotary encoder |
| Volume encoder push | GPIO 22 | software supports mute, physical push not usable |

## Video diagram

```mermaid
flowchart TD
    Pi[Raspberry Pi 4B] -->|Micro HDMI angled adapter| HDMIPath[HDMI ribbon/angled cable path]
    HDMIPath --> LCD[LCD controller HDMI input]
    RearRCA[Rear RCA composite jack] --> LCDRCA[LCD controller RCA composite input]
    LCD --> Panel[800x480 LCD panel]

    SourceSwitch[Rear source select switch] --> ButtonBoard[LCD controller button daughterboard]
    ButtonBoard --> LCD
```

## Display source select

The LCD controller has a button/IR daughterboard. The IR function is unused.

The source button was soldered to external wires and routed to a rear physical switch.

Pressing the switch cycles:

```text
HDMI -> RCA -> VGA -> RCA2 -> repeat
```

Only HDMI and RCA are currently useful.

## Audio diagram

```mermaid
flowchart TD
    Pi[Raspberry Pi 4B] -->|USB| USBSpeaker[Internal USB speaker]
    Rail[5V JST rail] --> Chime[YS-M3 MP3 module]
    Selector[CK1028 boot chime selector] --> Chime
    Chime --> LaptopSpeaker[Salvaged laptop speaker]
    ExternalUSB[Optional external USB audio adapter] --> RCAAudio[3.5mm/RCA audio cables]
```

## Boot chime selector

The CK1028 switch selects the YS-M3 startup sound.

Expected behavior:

1. Original monitor power switch turns on the 5V rail.
2. YS-M3 receives power.
3. After roughly two seconds, YS-M3 plays the selected startup sound.
4. The selected sound comes out of the dedicated salvaged laptop speaker.

## Rear ports and controls

| Rear item | Function |
|---|---|
| Original AC inlet | Charger input to internal USB power adapter |
| Original power switch | Interrupts battery output to 5V rail |
| RCA jack | Composite video input |
| USB port | Raspberry Pi USB host extension for hub/controllers |
| Source select switch | Cycles LCD controller input |
| Boot chime selector | Selects startup sound |
| Battery plunger | Presses Anker battery button from outside case |

## Bag charging diagram

```mermaid
flowchart LR
    USB[USB cable hidden in bag pocket] --> QiTx[Wireless charging transmitter under velvet]
    QiTx -->|trickle charge through aligned bottom| PiForma[Macintosh PiForma in bag]
```

The bag wireless charger is meant for trickle charging the Macintosh PiForma while it is sitting in the bag. It is not a fast-charge system.

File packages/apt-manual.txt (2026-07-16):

about-this-pi-forma
adduser
appmenu-gtk3-module
appmenu-registrar
apt
apt-listchanges
apt-transport-https
apt-utils
aria2
at-ease
avahi-daemon
base-files
base-passwd
bash
bash-completion
bc
bluetooth
bluez
bluez-firmware
bluez-tools
bsdutils
build-essential
bzip2
ca-certificates
cifs-utils
clippy
cloud-init
cmake
console-setup
control-strip-simulator
coreutils
cpio
cron
cron-daemon-common
curl
dash
debconf
debconf-i18n
debconf-utils
debhelper
debian-archive-keyring
debianutils
debsums
devscripts
dh-autoreconf
dhcpcd-base
dialog
diffutils
dmidecode
dosbox-x
dosfstools
dpkg
e2fsprogs
ed
ethtool
fbi
fbset
fcitx-libs-dev
fdisk
ffmpegthumbnailer
file
findutils
firmware-atheros
firmware-brcm80211
firmware-libertas
firmware-mediatek
firmware-realtek
flatpak
gcc-14-base
gdb
gh
git
gnupg
gpiod
grep
gzip
hostname
htop
imagemagick
init
init-system-helpers
initramfs-tools
iproute2
iputils-ping
jq
keyboard-configuration
kmod
kms++-utils
less
libacl1
libapparmor1
libapt-pkg7.0
libasound2-dev
libattr1
libaudit-common
libaudit1
libavcodec-dev
libavdevice-dev
libavformat-dev
libayatana-appindicator3-dev
libblkid1
libboost-filesystem-dev
libbpf1
libbsd0
libbz2-1.0
libc-bin
libc6
libcap-ng0
libcap2
libcap2-bin
libcdio-dev
libcdio-utils
libcom-err2
libcrypt1
libcurl4-openssl-dev
libdb5.3t64
libdbus-1-dev
libdbusmenu-gtk3-dev
libdebconfclient0
libdiscid-dev
libdiscid0
libdrm-dev
libedit2
libegl1-mesa-dev
libelf1t64
libext2fs2t64
libfdisk1
libfmt-dev
libfreeimage-dev
libfreetype-dev
libfuse2t64
libgbm-dev
libgcc-s1
libgl1
libgl1-mesa-dev
libgles2-mesa-dev
libgmp10
libgssapi-krb5-2
libgtk-3-0t64
libgtk-3-dev
libgtk3-perl
libhogweed6t64
libibus-1.0-dev
libidn2-0
libiso9660-dev
libjansson4
libk5crypto3
libkeyutils1
libkmod2
libkrb5-3
libkrb5support0
liblastlog2-2
liblocale-gettext-perl
liblz4-1
liblzma5
libmd0
libmnl0
libmount1
libmtp-runtime
libncursesw6
libnettle8t64
libnewt0.52
libnftables1
libnftnl11
libpam-chksshpwd
libpam-modules
libpam-modules-bin
libpam-runtime
libpam0g
libpcre2-8-0
libpipewire-0.3-dev
libpopt0
libproc2-0
libpulse-dev
libreadline8t64
librsvg2-bin
librsvg2-dev
libsamplerate0-dev
libsdl2-dev
libseccomp2
libselinux1
libsemanage-common
libsemanage2
libsepol2
libslang2
libsmartcols1
libsndio-dev
libspa-0.2-dev
libspeexdsp-dev
libsqlite3-0
libss2
libssl3t64
libstdc++6
libsystemd-shared
libsystemd0
libtag1-dev
libtext-charwidth-perl
libtext-iconv-perl
libtext-wrapi18n-perl
libtinfo6
libtirpc-common
libtirpc3t64
libudev-dev
libudev1
libunistring5
libusb-1.0-0-dev
libuuid1
libvlc-dev
libvlccore-dev
libwebkit2gtk-4.1-dev
libx11-xcb-dev
libxcursor-dev
libxi-dev
libxinerama-dev
libxkbcommon-dev
libxrandr-dev
libxss-dev
libxtables12
libxv-dev
libxxf86vm-dev
libxxhash0
libzstd1
linux-headers-rpi-2712
linux-headers-rpi-v8
linux-image-rpi-2712
linux-image-rpi-v8
linux-sysctl-defaults
locales
login
login.defs
logrotate
logsave
lsb-release
lua5.1
luajit
lxappearance
lxpanel-data
man-db
manpages-dev
mawk
mc
mkvtoolnix
mount
nano
ncdu
ncurses-base
ncurses-bin
net-tools
netbase
network-manager
network-manager-gnome
nftables
nodejs
npm
ntfs-3g
obconf
openbox
openssl
openssl-provider-legacy
p7zip
p7zip-full
parted
passwd
pciutils
perl-base
pi-bluetooth
pi-forma-panel
picom
pipenv
pipewire
pipewire-audio
pipewire-pulse
pixflat-icons
pixflat-theme
pkg-config
plymouth
plymouth-themes
pngcheck
portaudio19-dev
procps
psmisc
pulseaudio-utils
python-is-python3
python3
python3-cdio
python3-dbus-next
python3-dev
python3-full
python3-gpiozero
python3-libdiscid
python3-libgpiod
python3-musicbrainzngs
python3-pip
python3-pyqt6
python3-rpi-lgpio
python3-sdl2
python3-smbus2
python3-spidev
python3-uinput
python3-urwid
python3-venv
python3-vlc
qmmp
qt6-base-dev
qt6-base-dev-tools
qt6-multimedia-dev
qt6-tools-dev
qtcreator
qtractor
rapidjson-dev
raspberrypi-archive-keyring
raspberrypi-net-mods
raspberrypi-sys-mods
raspi-config
raspi-firmware
raspi-utils
readline-common
reptyr
rpd-applications
rpd-developer
rpd-graphics
rpd-preferences
rpd-theme
rpd-utilities
rpd-wayland-core
rpd-wayland-extras
rpd-x-core
rpd-x-extras
rpi-cloud-init-mods
rpi-eeprom
rpi-keyboard-config
rpi-keyboard-fw-update
rpi-loop-utils
rpi-swap
rpi-update
rpi-usb-gadget
rpicam-apps-lite
rpm
rsync
sed
sensible-utils
shellcheck
sqv
ssh
ssh-import-id
strace
subversion
sudo
surf
swig
systemd
systemd-coredump
systemd-sysv
systemd-timesyncd
sysvinit-utils
tar
thunar
tumbler
tuxpaint
tuxpaint-config
tuxpaint-data
tuxpaint-plugins-default
tuxpaint-stamps-default
tzdata
udev
udisks2
unzip
usb-modeswitch
usbutils
userconf-pi
util-linux
v4l-utils
vim-common
vim-tiny
vlc
wayland-utils
weston
wget
whiptail
wireless-tools
wireplumber
wmctrl
wpasupplicant
x11-apps
x11-utils
x11vnc
xdotool
xfce4-appmenu-plugin
xfce4-panel
xfce4-session
xfce4-settings
xfce4-terminal
xfdesktop4
xfwm4
xserver-xephyr
yad
yt-dlp
zenity
zip
zlib1g
zsh

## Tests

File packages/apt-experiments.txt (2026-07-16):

# Curated top-level APT roots for retained experiments and possible future work.
# This is not a dependency closure. It intentionally preserves experiment intent
# without implying these packages are required by the core PiForma runtime.

# DOS/Windows-era and launcher experiments
dosbox-x

# Creative and audio-production experiments
qjackctl
qtractor
tuxpaint
tuxpaint-config

# Wayland, Weston, labwc, and nested-display experiments
labwc
rpd-wayland-core
rpd-wayland-extras
wayland-utils
wayvnc
weston
xserver-xephyr

# XFCE and alternate desktop/panel experiments
appmenu-gtk3-module
appmenu-registrar
thunar
xfce4-appmenu-plugin
xfce4-panel
xfce4-session
xfce4-settings
xfce4-terminal
xfdesktop4
xfwm4

# Qt style and alternate UI experiments
qt5ct
qt6ct

# Retained compositor fallback/current-state anomaly
xcompmgr

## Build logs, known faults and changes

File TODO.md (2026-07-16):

# Documentation Completion Checklist

Macintosh PiForma is a finished project. This checklist tracks the remaining work needed to make the repository archival-grade and independently rebuildable. It is not a package-cleanup or hardware-redesign list.

## Completed foundation

- [x] Archive the final STL, 3MF, and OpenSCAD files under `stl/`
- [x] Add the printed-parts manifest, hashes, and file-format warnings
- [x] Archive the live PiForma Python and shell scripts under `scripts/`
- [x] Archive the live system and user systemd units under `systemd/`
- [x] Archive the verified desktop and application configuration under `config/`
- [x] Document the APT/dpkg package state and curated rebuild profiles under `packages/`
- [x] Document the Raspberry Pi 4B, 256GB microSD, Debian 13.5/Trixie, and X11 system baseline
- [x] Link the third-party mouse shell and project-specific scroll-wheel design
- [x] Document the companion application repositories and their integration
- [x] Add hardware, maintenance, known-issues, and safety documentation

## Priority 1: recovery blockers

These are the remaining items most likely to prevent a clean recovery from the repository.

- [ ] Identify and record the exact Raspberry Pi OS image filename, release date, architecture, and checksum used as the tested rebuild starting point
- [ ] Perform a complete fresh-microSD rebuild using only the repository and record every undocumented intervention
- [ ] Archive trusted copies of the five local PiForma `.deb` packages, or add repeatable build/release instructions that recreate them from documented commits
- [ ] Rebuild and independently verify the About This PiForma `.deb`; the currently discovered package does not match the live installation
- [ ] Archive `/boot/firmware/cmdline.txt`
- [ ] Archive the active LightDM autologin configuration and document the required `frost` UID/session assumptions
- [ ] Archive `~/.config/gtk-3.0/settings.ini` and any other active GTK appearance settings
- [ ] Archive `~/.config/autostart/clippy.desktop`
- [ ] Archive `/etc/xdg/autostart/env-display.desktop`
- [ ] Archive or document the narrow sudoers rule used by the Apple-logo ten-second shutdown gesture
- [ ] Archive the four exact `~/Desktop` launchers used by `apple_gesture_button.py`: `Chromium-70.desktop`, `MacOS9.desktop`, `Winamp.desktop`, and `Retropie.desktop`
- [ ] Archive the active GTK theme, icon theme, cursor theme, Chicago/Charcoal fonts, wallpaper, Apple logo image, launcher icons, and favicons needed to reproduce the desktop appearance
- [ ] Archive the Weather Channel `launch.html` and `satellite.png` files alongside the existing launcher script
- [ ] Preserve the deployed Flying Toasters build or document a tested process that recreates it from the companion repository
- [ ] Archive the selected Plymouth theme, RetroPie/asplashscreen configuration, and required boot-splash assets
- [ ] Archive the RetroPie and EmulationStation configuration, controller mappings, and any PiForma-specific launch/exit behavior
- [ ] Preserve the SheepShaver AppImage and document a private backup procedure for the ROM and Mac OS disk image
- [ ] Document how Kiwix content files are backed up and restored separately from the Flatpak application
- [ ] Review the three archived Python virtual environments and mark each one as required, optional, historical, or disposable

## Priority 2: exact hardware reproduction

- [ ] Replace the system-level wiring map with a connector-by-connector schematic showing polarity, pin numbers, wire colors, wire gauges, connector orientation, and strain relief
- [ ] Label every custom 5V rail output and document the exact load connected to each JST socket
- [ ] Record the exact JST connector family, pitch, mating housings, and terminal part numbers if they can be confirmed
- [ ] Record the exact final LCD panel and controller-board model text, connector type, and ribbon orientation if visible
- [ ] Add a strict disassembly and assembly sequence, including shelf insertion, cable-routing order, LCD/bezel/braces/feet order, and when each connector must be attached
- [ ] Record screw locations, screw lengths, thread sizes, original fasteners reused, zip-tie locations, tape locations, adhesive locations, and any critical clearances
- [ ] Document the boot-chime storage medium, supported audio format, track filenames, selector-position mapping, and replacement procedure
- [ ] Archive or privately preserve the boot-chime audio files used by the final selector configuration
- [ ] Document the complete bag-charging path from Qi transmitter through the PiForma receiver and into the Anker charging input
- [ ] Record measured idle/load power, rail voltage under load, approximate battery runtime, charging time, maximum Pi temperature, throttling state, and internal charger temperature
- [ ] Record the exact deployed ZMK keyboard firmware commit, configuration branch, build command, firmware hash, flashing procedure, and Bluetooth reset/pairing procedure

## Priority 3: documentation corrections and polish

- [ ] Update `docs/hardware.md` so the Apple-logo hold behavior lists the current 2-second, 6-second, and 10-second actions
- [ ] Replace the stale “link to be added” mouse-shell note in `docs/bom.md` with the existing Printables links
- [ ] Restore or replace the missing Space Jam launcher icon
- [ ] Correct invalid or incomplete `Categories=` fields in the archived AtEase launchers after comparing them with the live files
- [ ] Update `docs/cleanup-plan.md` so every archive item is marked completed, still missing, historical, or intentionally excluded
- [ ] Explicitly state the license for original STL, 3MF, and OpenSCAD files in `LICENSE.md`
- [ ] Decide whether the unusual `nobody:nogroup` ownership of deployed PiForma scripts and binaries should be corrected, then document the intended ownership
- [ ] Validate the archived system units on the unrestricted Pi console with `systemd-analyze verify`
- [ ] Decide whether `dex` should be installed as the documented `.desktop` launcher fallback used by the companion application guidance

## Final project photos

- [ ] Front beauty shot
- [ ] Rear controls and ports
- [ ] Interior with the case open
- [ ] Three-level shelf assembly
- [ ] Custom 5V power rail
- [ ] LCD controller and ribbon orientation
- [ ] Battery position and rear plunger
- [ ] Boot-chime selector and sound module
- [ ] Apple-logo touch sensor
- [ ] Bluetooth ADB keyboard conversion
- [ ] Matching wireless mouse
- [ ] Bag interior and wireless charging arrangement
- [ ] Folding monitor stand

## Definition of archival-grade

This checklist is complete when a second microSD card can be built from a named base image using the repository, the hardware can be disassembled and rewired without relying on memory, all legally distributable recovery assets are archived, private/copyrighted assets have an explicit private-backup procedure, and every final feature passes the verification checklist in `docs/software-installation.md`.

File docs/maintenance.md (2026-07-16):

# Maintenance

This is the future-me-forgot-how-this-worked page.

For package-state recovery, use [PiForma Package Inventory](package-inventory.md), [Macintosh PiForma Software Installation](software-installation.md), and the machine-readable files under [`../packages/`](../packages/). Package removal is currently deferred in favor of inventory and reproducibility.

## Opening the case

Be careful with:

- LCD ribbon cable
- HDMI ribbon path
- wires to rear source switch
- wires to boot chime selector
- power rail JST plugs
- Apple logo touch sensor wiring

The display ribbon is the most delicate final-build item. Do not let it flop around.

## Display problems

Symptoms:

- weird lines
- flicker
- image distortion
- display cuts in and out

Check:

1. LCD ribbon seating
2. tape/strain relief
3. HDMI ribbon clearance
4. Pi HDMI adapter touching rear of LCD
5. display controller power JST

## No boot

Check:

1. Anker battery is charged
2. rear AC inlet is providing charge
3. original power switch is on
4. Anker output is awake
5. battery plunger can wake the Anker
6. 5V rail input is live
7. Pi power JST is seated
8. microSD card is seated

## No boot chime

Check:

1. 5V rail output to YS-M3
2. CK1028 selector position
3. YS-M3 speaker connection
4. SD/card/media on YS-M3 if applicable
5. wait two seconds after power-on

## No audio from Pi

Check:

1. USB speaker connected to Pi
2. PipeWire default sink
3. volume knob did not turn volume down
4. USB speaker is not muted
5. service logs for volume knob

Useful commands:

```bash
pactl list short sinks
pactl get-sink-volume @DEFAULT_SINK@
systemctl status volume-knob.service --no-pager
```

## Apple logo gestures not working

Check:

1. TTP223 gets 5V from rail
2. GPIO signal wire to GPIO 23
3. service is running
4. script uses `LGPIOFactory`
5. no old pigpio assumptions

Useful commands:

```bash
systemctl status apple-gesture-button.service --no-pager
journalctl -u apple-gesture-button.service -f
```

## Volume knob not working

Check:

1. GPIO 17 and 27 encoder lines
2. GPIO 22 push line if needed
3. service is running
4. script has permissions
5. PipeWire default sink exists

```bash
systemctl status volume-knob.service --no-pager
journalctl -u volume-knob.service -f
```

## RetroPie controller exit behavior

The Apple logo hold gesture is intentional.

For the N64 USB controller, there is no spare clean hotkey button. Hold the Apple logo to close the running game. Hold again to close EmulationStation if needed.

## Source select

The rear source button cycles through:

```text
HDMI -> RCA -> VGA -> RCA2 -> repeat
```

Only HDMI and RCA are normally useful.

## Bag charging

If wireless bag charging does not work:

1. confirm hidden USB cable is powered
2. confirm wireless transmitter is aligned under velvet
3. confirm monitor bottom is seated in alignment grooves
4. remember this is trickle charging, not fast charging

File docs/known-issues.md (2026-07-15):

# Known Issues and Future Improvements

This is the honest list. Every finished hardware project has one.

## Display ribbon sensitivity

The LCD ribbon currently works, but it is sensitive.

Current state:

- 150mm ribbon cable installed
- taped down to reduce movement
- needs careful alignment
- can cause display issues if shifted during assembly

Future improvement:

- test 80mm or 50mm cable
- reduce slack
- add better strain relief
- avoid disturbing the connector once stable

## Raspberry Pi heat can warp the upper shelf

The Raspberry Pi 4B runs very hot inside the enclosed case. Because the Pi originally sat directly on the upper printed shelf, prolonged heat softened and warped the shelf plastic.

The LCD display controller board is mounted directly beneath that shelf. As the shelf sagged and flexed, it began pressing against or bending the display controller board. This produced symptoms that initially looked like a bad ribbon cable or loose display connection, including:

- graphical glitches
- intermittent display failure
- loss or distortion of color
- image instability
- behavior that changed when the shelf, controller board, or ribbon area was disturbed

The actual cause was mechanical pressure on the display controller board resulting from heat deformation above it, not necessarily a failed LCD ribbon.

Current mitigation:

- Raspberry Pi elevated above the printed shelf with an additional 3D printed cradle or mount
- air gap added between the Pi and the shelf
- aluminum foil used as a heat-reflective layer below the Pi and above it near the top of the shelf enclosure
- shelf secured to the case with a zip tie to reduce further sagging
- display controller board checked to ensure the shelf is no longer flexing it

The foil must remain electrically isolated from the Raspberry Pi, display controller, GPIO pins, solder joints, and other exposed electronics because aluminum foil is conductive.

Current result:

- the shelf appears more stable
- heat transfer into the printed shelf is reduced
- display glitches caused by pressure on the controller board have not returned so far

Future improvement:

- redesign the upper shelf with a center support column or rib
- use a more heat-resistant filament for the shelf
- add a purpose-built Pi mount with permanent airflow clearance
- add active or passive cooling for the Raspberry Pi
- replace loose foil with a nonconductive thermal barrier or properly secured insulated heat shield
- add ventilation openings if they can be incorporated without harming the exterior appearance
- monitor Pi temperature during extended use
- inspect the display controller board and shelf whenever unexplained display problems appear

## Battery fit is tight

The Anker battery is held in the rear by friction.

This works, but it is tight. Probably tighter than ideal.

Future improvement:

- design a dedicated rear cradle
- add thin padding
- add a removable retaining strap
- avoid stressing the case sides

## No fuse protection on custom 5V rail

The rail has no inline fuse or polyfuse.

Current protection depends on:

- Anker battery protection
- device-level protection
- common sense

Future improvement:

- add inline fuse on rail input
- add per-output fusing if rebuilding
- add reverse-polarity protection

## Battery display visibility

The Anker battery display is only visible by peeking through the top slits.

The rear plunger can press the battery button, but the display is not cleanly exposed.

Future improvement:

- add a light pipe
- add a tiny mirror/window
- integrate battery status another way
- ignore it because this is already good enough

## Source select is physical, not touch

Original idea: touch sensor and relay source switching.

Final reality: physical switch wired to LCD controller source button.

Reason:

- noisy power adapter made relays and touch sensors unreliable
- physical switch worked

Future improvement:

- revisit touch-based source selection only if a clean power/noise strategy is used

## Raspberry Pi 5 upgrade

A Raspberry Pi 5 would be nice, but the Pi 4B is currently doing the job.

Future upgrade considerations:

- thermals
- power draw
- HDMI connector differences
- mounting differences
- software compatibility
- cost

## Audio could be fancier

The internal USB speaker is simple and works.

Future improvement:

- better internal speaker
- proper stereo amp
- cleaner RCA audio integration
- keep boot chime speaker separate because it is charming

## External RCA audio is not built in

The rear RCA jack is composite video only. RCA audio requires an external USB-to-audio adapter.

Future improvement:

- add rear RCA audio jacks
- integrate USB audio internally
- add a switchable audio path

## Documentation needs real photos

This repo expects photos to be added under `docs/images/`.

Most important photos:

- front beauty shot
- rear controls
- inside open
- shelf closeup
- battery position
- power rail
- display controller
- Apple logo sensor
- keyboard
- mouse
- bag charging setup

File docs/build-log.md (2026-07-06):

# Build Log

This is the story version. The technical docs explain what it is. This explains how it became that way.

## The old idea

Macintosh PiForma started as one of those future-me-will-do-something-with-this objects.

The donor Apple IIc Monitor came from the existing collection. The CRT was not in good shape. It was discolored, flickering, and not worth turning into a heroic restoration project. The CRT was removed years ago, but the case, screws, internals, and shell were kept because maybe someday there would be a reason.

This build is that reason.

## The influence

This project owes a lot of its spirit to the old Macintosh modding scene. AppleFritter, G3 and G4 mods, painted cases, weird internal hacks, utilitarian mods, and builds that made no sense except that they absolutely made sense to the person building them.

That is the lane Macintosh PiForma lives in.

It is not a museum restoration. It is a Mac mod. A Pi mod. A Performa pun. A portable retro computer. A small pile of what-if-this-actually-worked.

## January 2026: display and power start to take shape

The early purchases were about proving the core idea:

- 9-inch LCD with controller
- Anker Prime 26K 300W battery
- USB speaker
- 100W USB-C charger
- Apple-ish supporting parts
- early display boards and adapters

The Anker became the right choice because it solved the ugly power problems:

- charging
- battery management
- protection
- portable runtime
- USB power output

Instead of building a battery management system, the build wraps around a battery pack that already knows how to be a battery pack.

## February 2026: the cable and controller era

This was the part where theory got punched in the face by connector orientation.

A lot of HDMI ribbon cables and display controller options were purchased because there was no way to know exactly what angle, length, or connector direction would fit until parts were physically inside the case.

This is the engineering tax phase.

Not waste. Tuition.

Also around this time, the keyboard conversion work became real:

- XIAO nRF52840
- custom PCB
- nice!view
- LiPo
- ZMK
- ADB keyboard conversion based on Matt Chesters' work

## March and April 2026: structure and refinement

The project moved from will-this-display-work to how-does-everything-live-inside-this-thing.

This is where the custom internal shelf becomes the actual heart of the build.

The shell is vintage. The Pi is the compute module. The Anker is the battery. But the shelf is what makes it one machine.

It organizes:

- Pi
- display controller
- internal charger
- speaker
- 5V rail
- cable paths

The battery stayed separate, sitting on the rear metal chassis floor, wedged in by friction.

## May 2026: final display and less nonsense

The May 16 LCD kit became the final working display setup. The build settled around 800x480.

The noisy Amazon power adapter was rejected after causing EMI weirdness. Relays and touch sensors were acting possessed. The eBay 100W adapter behaved better and became the final internal charger.

The source select plan also got simpler. Instead of using touch sensors and relays, the final build wires the LCD controller's source button to a physical rear switch.

That is not less clever. It is more finished.

## June 2026: software, gestures, and putting a bow on it

The software side matured into the final experience:

- Mac OS 9-ish desktop
- Apple logo gesture button
- volume knob service
- boot chime selector
- RetroPie launch without keyboard/mouse
- Weather Channel kiosk
- Flying Toasters
- Mac OS 9 / SheepShaver
- Winamp/QMMP
- browser launchers

The Apple logo gesture button became one of the most useful features. Four taps launches RetroPie. Holding the logo closes the game or exits EmulationStation, solving the N64 controller hotkey problem without sacrificing a game button.

That is exactly the kind of feature that makes this feel integrated instead of just assembled.

## What made it finished

The project felt done when these things were true:

- it powered on with the original monitor switch
- it played a selectable boot chime
- it had a working internal display
- it had working internal audio
- it had a usable desktop
- it could launch RetroPie from the Apple logo
- it had a working Bluetooth ADB keyboard
- it had a matching mouse
- it had a travel bag that protected and charged it

At that point, it stopped being a project I need to finish and became a computer I built.

That is where this documentation freezes the build.

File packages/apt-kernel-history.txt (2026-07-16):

# Forensic record of exact versioned kernel packages present in dpkg status.
# These are not normal fresh-install roots. Use the kernel metapackages in
# apt-system-base.txt for a future Pi 4 rebuild unless performing an explicit
# historical clone with a known need for these exact versions.

linux-base-6.18.34+rpt-rpi-2712
linux-base-6.18.34+rpt-rpi-v8
linux-headers-6.12.47+rpt-common-rpi
linux-headers-6.12.47+rpt-rpi-2712
linux-headers-6.12.47+rpt-rpi-v8
linux-headers-6.12.62+rpt-common-rpi
linux-headers-6.12.62+rpt-rpi-2712
linux-headers-6.12.62+rpt-rpi-v8
linux-headers-6.18.34+rpt-common-rpi
linux-headers-6.18.34+rpt-rpi-2712
linux-headers-6.18.34+rpt-rpi-v8
linux-image-6.12.47+rpt-rpi-2712
linux-image-6.12.47+rpt-rpi-v8
linux-image-6.12.62+rpt-rpi-2712
linux-image-6.12.62+rpt-rpi-v8
linux-image-6.18.34+rpt-rpi-2712
linux-image-6.18.34+rpt-rpi-v8
linux-kbuild-6.12.47+rpt
linux-kbuild-6.12.62+rpt
linux-kbuild-6.18.34+rpt

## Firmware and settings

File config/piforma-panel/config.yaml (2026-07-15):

bar:
  width: 658
  height: 20
  x: 76
  y: 0
  radius_top_left: 10
  radius_top_right: 10
  font_family: Charcoal
  font_size: 12

apple:
  logo_path: /home/frost/.local/share/icons/apple-9.png

clock:
  enabled: true
  format: "%I:%M %p"

applications:
  scan_dirs:
    - /home/frost/.local/share/applications
    - /usr/local/share/applications
    - /usr/share/applications
  show_no_display: false
  group_by_categories: true
  show_category_labels: false
  max_menu_height: 420

menus:
  show_file: true
  show_edit: true
  show_view: true
  show_special: true

show_desktop_apps:
  - piforma-panel
  - controlstrip-simulator
  - atease
  - clippy

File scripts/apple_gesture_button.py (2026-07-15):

#!/usr/bin/env python3
import os
import re
import shlex
import time
import subprocess
import threading
from typing import Callable, Dict, Optional, List

from gpiozero import Device, Button
from gpiozero.pins.lgpio import LGPIOFactory

Device.pin_factory = LGPIOFactory()

GPIO_PIN = 23

# Tap behavior
MULTITAP_WINDOW_S = 0.70
BOUNCE_S = 0.05

# Hold thresholds (seconds)
HOLD_CLOSE_ACTIVE_S = 2.0     # 2 to 3 seconds closes top window
HOLD_CLOSE_ALL_S = 6.0        # 6 to 10 seconds closes everything and shows desktop
HOLD_SHUTDOWN_S = 10.0        # 10+ seconds powers off

# Path to your desktop entries
DESKTOP_DIR = "/home/frost/Desktop"
DESKTOP_MAP = {
    1: f"{DESKTOP_DIR}/Chromium-70.desktop",
    2: f"{DESKTOP_DIR}/MacOS9.desktop",
    3: f"{DESKTOP_DIR}/Winamp.desktop",
    4: f"{DESKTOP_DIR}/Retropie.desktop",
}

def log(msg: str) -> None:
    print(msg, flush=True)

def run_bg(argv: List[str], env: Optional[dict] = None) -> None:
    subprocess.Popen(argv, env=env or os.environ.copy())

def run_capture(argv: List[str], env: Optional[dict] = None) -> subprocess.CompletedProcess:
    return subprocess.run(argv, stdout=subprocess.PIPE, stderr=subprocess.PIPE, text=True, env=env)

def x_env() -> dict:
    env = os.environ.copy()
    env.setdefault("HOME", "/home/frost")
    env.setdefault("DISPLAY", ":0")
    env.setdefault("XAUTHORITY", "/home/frost/.Xauthority")
    env.setdefault("XDG_RUNTIME_DIR", "/run/user/1000")
    env.setdefault("DBUS_SESSION_BUS_ADDRESS", "unix:path=/run/user/1000/bus")
    return env

def parse_desktop_exec(desktop_file: str) -> Optional[List[str]]:
    if not os.path.exists(desktop_file):
        log(f"Desktop file not found: {desktop_file}")
        return None

    exec_line = None
    in_desktop_entry = False

    with open(desktop_file, "r", encoding="utf-8", errors="ignore") as f:
        for raw in f:
            line = raw.strip()
            if line.startswith("[") and line.endswith("]"):
                in_desktop_entry = (line == "[Desktop Entry]")
                continue
            if not in_desktop_entry:
                continue
            if line.startswith("Exec="):
                exec_line = line[len("Exec="):].strip()
                break

    if not exec_line:
        log(f"No Exec= found in {desktop_file}")
        return None

    # Remove desktop placeholders like %U, %u, %F, %f, etc.
    exec_line = re.sub(r"\s%[fFuUdDnNickvm]", "", exec_line).strip()

    try:
        return shlex.split(exec_line)
    except Exception as e:
        log(f"Failed to parse Exec line in {desktop_file}: {e}")
        return None

def launch_desktop(desktop_file: str) -> None:
    argv = parse_desktop_exec(desktop_file)
    if not argv:
        return
    log(f"Launching from {os.path.basename(desktop_file)}: {' '.join(argv)}")
    run_bg(argv, env=x_env())

def close_active_window() -> None:
    env = x_env()
    # Close the currently active window
    run_bg(["wmctrl", "-c", ":ACTIVE:"], env=env)

def show_desktop() -> None:
    env = x_env()
    # Try EWMH show-desktop
    r = run_capture(["wmctrl", "-k", "on"], env=env)
    if r.returncode == 0:
        return
    # Fallback: Super+D if xdotool exists
    if subprocess.call(["which", "xdotool"], stdout=subprocess.DEVNULL, stderr=subprocess.DEVNULL) == 0:
        run_bg(["xdotool", "key", "super+d"], env=env)

def close_all_windows() -> None:
    env = x_env()
    r = run_capture(["wmctrl", "-l"], env=env)
    if r.returncode != 0:
        log("wmctrl -l failed, cannot close all windows")
        return

    # Lines look like: 0x03a00007  0 host Window Title
    window_ids = []
    for line in r.stdout.splitlines():
        parts = line.split()
        if parts and parts[0].startswith("0x"):
            window_ids.append(parts[0])

    for wid in window_ids:
        # -i means use the hex window id
        run_bg(["wmctrl", "-i", "-c", wid], env=env)

def shutdown_pi() -> None:
    # This will require permissions. See sudoers note below.
    log("Shutdown requested (hold >= 10s)")
    run_bg(["sudo", "/bin/systemctl", "poweroff"])

class GestureButton:
    def __init__(self, pin: int):
        self.btn = Button(pin, pull_up=True, bounce_time=BOUNCE_S)

        self._tap_count = 0
        self._tap_timer: Optional[threading.Timer] = None

        self._pressed_at: Optional[float] = None
        self._hold_consumed = False

        self.btn.when_pressed = self._on_pressed
        self.btn.when_released = self._on_released

    def _on_pressed(self) -> None:
        self._pressed_at = time.time()
        self._hold_consumed = False

    def _on_released(self) -> None:
        if self._pressed_at is None:
            return

        held_s = time.time() - self._pressed_at
        self._pressed_at = None

        # Holds override taps
        if held_s >= HOLD_SHUTDOWN_S:
            self._cancel_taps()
            self._hold_consumed = True
            shutdown_pi()
            return

        if held_s >= HOLD_CLOSE_ALL_S:
            self._cancel_taps()
            self._hold_consumed = True
            log("Hold action: close all windows and show desktop")
            close_all_windows()
            show_desktop()
            return

        if held_s >= HOLD_CLOSE_ACTIVE_S:
            self._cancel_taps()
            self._hold_consumed = True
            log("Hold action: close active window")
            close_active_window()
            return

        # Short press counts as a tap
        self._tap_count += 1
        self._restart_tap_timer()

    def _restart_tap_timer(self) -> None:
        if self._tap_timer:
            self._tap_timer.cancel()
        self._tap_timer = threading.Timer(MULTITAP_WINDOW_S, self._finalize_taps)
        self._tap_timer.daemon = True
        self._tap_timer.start()

    def _cancel_taps(self) -> None:
        self._tap_count = 0
        if self._tap_timer:
            self._tap_timer.cancel()
            self._tap_timer = None

    def _finalize_taps(self) -> None:
        taps = self._tap_count
        self._tap_count = 0

        desktop_file = DESKTOP_MAP.get(taps)
        if desktop_file:
            log(f"Tap action: {taps} tap(s)")
            launch_desktop(desktop_file)
        else:
            log(f"{taps} tap(s): no action mapped")

def main() -> None:
    # Prevent lgpio notify file weirdness under systemd
    os.chdir("/home/frost")

    log(f"Apple logo gesture button active on GPIO {GPIO_PIN}")
    log("Tap map: 1=Chromium, 2=MacOS9, 3=Winamp, 4=RetroPie")
    log("Hold: 2s close active, 6s close all + desktop, 10s shutdown")

    GestureButton(GPIO_PIN)

    while True:
        time.sleep(60)

if __name__ == "__main__":
    main()

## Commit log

2026-07-06 Add wiring documentation
2026-07-06 Add bill of materials
2026-07-06 Add printed parts documentation
2026-07-06 Add STL placeholder folder
2026-07-06 Add shelf STL folder placeholder
2026-07-06 Add bezel STL folder placeholder
2026-07-06 Add screen feet STL folder placeholder
2026-07-06 Add power rail STL folder placeholder
2026-07-06 Add battery plunger STL folder placeholder
2026-07-06 Add boot chime switch STL folder placeholder
2026-07-06 Add monitor stand STL folder placeholder
2026-07-15 Document PiForma mouse models and custom scroll wheel
2026-07-15 Archive verified PiForma configuration
    [config.txt]
2026-07-15 Document Raspberry Pi heat warping shelf
2026-07-16 Document package inventory and rebuild profiles
    Add forensic package snapshots, curated rebuild roots, development and experiment profiles, non-APT inventories, and fresh-install guidance. Include final review fixes for Tauri/Qt build dependencies, evidence-based GPIO runtime roots, dex fallback guidance, and the unverified About This PiForma package warning.
    [apt-installed.tsv, apt-package-roles.tsv, local-deb-packages.tsv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]
2026-07-16 Archive normalized PiForma printed parts
    Add normalized STL, 3MF, and OpenSCAD files for the finished PiForma build, plus a hashed manifest and complete printed-parts documentation covering compatibility, assembly, and safety notes.
    [5v-rail-enclosure.3mf, 5v-rail-enclosure.stl, anker-battery-button-plunger.3mf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]
2026-07-16 Remove stale STL placeholder READMEs
    Delete obsolete per-folder placeholder files now that the normalized printable models and top-level documentation are present.
